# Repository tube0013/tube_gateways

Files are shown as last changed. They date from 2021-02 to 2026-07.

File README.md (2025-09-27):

# TubesZB Coordinators and Routers

⚠️ **Site Re-Organization in progress** ⚠️

Latest Documentation can be found here: https://tube0013.github.io/tube_gateways/

Information and documentation on TubeZB coordinators and routers. Pre-assembled hardware devices can be purchased from https://tubeszb.com

TubesZB Coordinators work via serial over Ethernet for use with any zigbee controller project that can access and interface with a remote Serial to IP bridge/proxy server device. 

This can today be used by home automation applications such as example; [Home Assistant (ZHA integration)](https://www.home-assistant.io/integrations/zha/) and [Zigbee2MQTT](https://www.zigbee2mqtt.io/).

## Check out my Addon Repository
With Firmware flashing and other tools for HASSOS/Supervised users: https://github.com/tube0013/tubeszb_addons



## Current Products 
**Find latest Firmware and Source files**

| **CC2652 Products** | | |
| ----- | --- | --- |
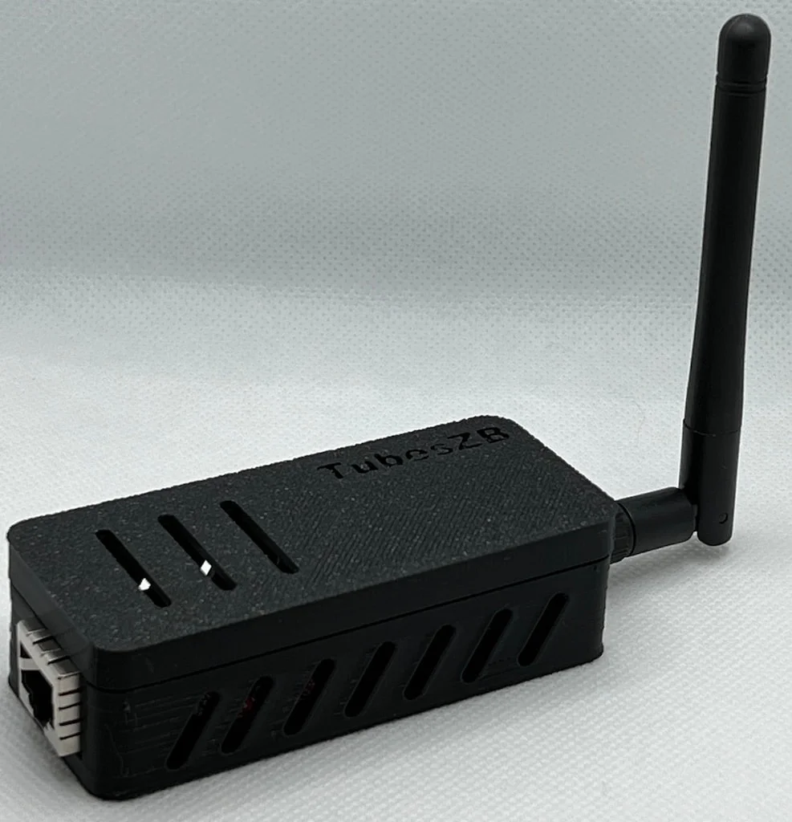
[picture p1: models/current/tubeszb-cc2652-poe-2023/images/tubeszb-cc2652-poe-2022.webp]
|   | [tubeszb-cc2652-poe-2023](https://github.com/tube0013/tube_gateways/tree/main/models/current/tubeszb-cc2652-poe-2023) | CC2652P2 Radio Module + Olimex ESP32-PoE Module |
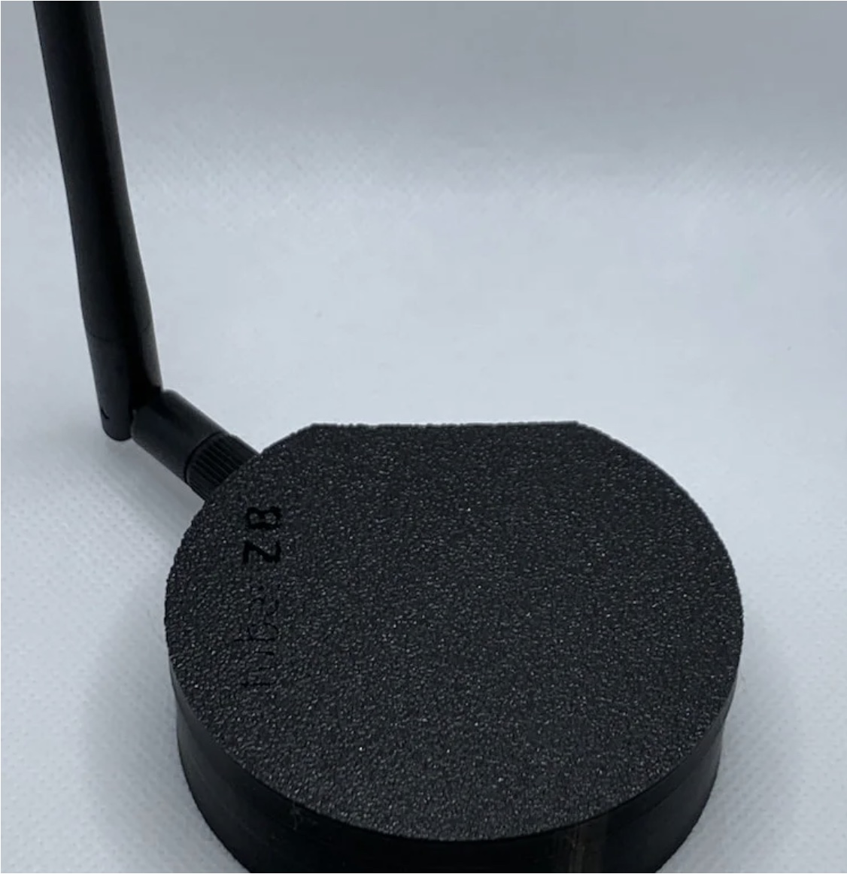
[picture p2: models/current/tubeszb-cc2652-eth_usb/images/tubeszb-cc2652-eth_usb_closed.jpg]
|   | [tubeszb-cc2652-eth_usb](https://github.com/tube0013/tube_gateways/tree/main/models/current/tubeszb-cc2652-eth_usb) | CC2652P2 Radio Module + WirelessTag WT32-ETH01 ESP32 Module |
| pic | [tubeszb-router](https://github.com/tube0013/tube_gateways/tree/main/models/current/tubeszb-router) | CC2652P2 Based Zigbee Router |
| **EFR32 Products** | | |
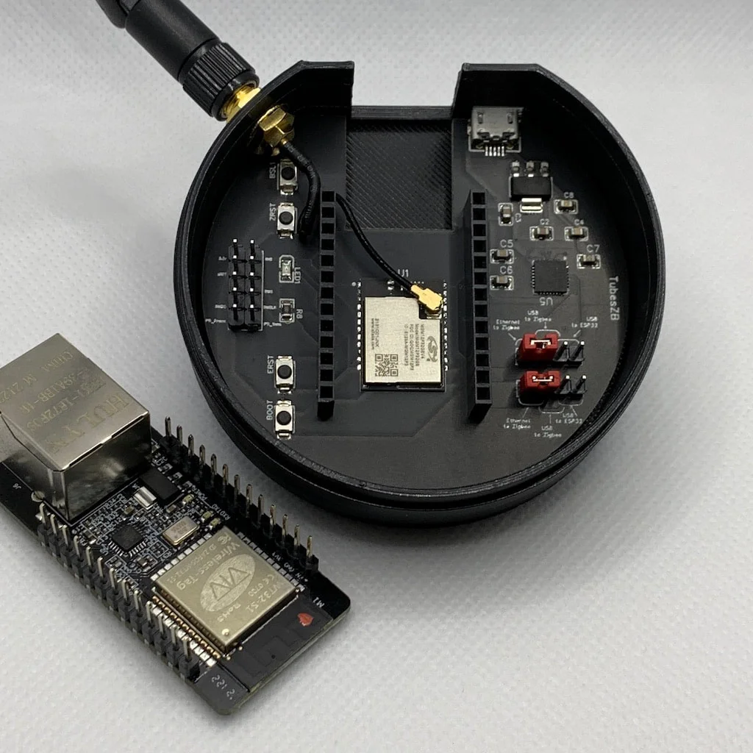
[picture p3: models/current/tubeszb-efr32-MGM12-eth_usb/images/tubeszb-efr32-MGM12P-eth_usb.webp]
|  | [tubeszb-efr32-MGM12-eth_usb](https://github.com/tube0013/tube_gateways/tree/main/models/current/tubeszb-efr32-MGM12-eth_usb) | MGM12P Radio Module + WirelessTag WT32-ETH01 ESP32 Module |
| BT Proxy | | |
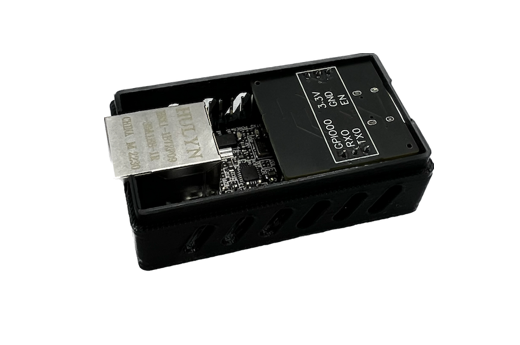
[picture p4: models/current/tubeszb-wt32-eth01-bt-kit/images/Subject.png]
|  | [tubeszb-wt32-eth01-bt-kit](https://github.com/tube0013/tube_gateways/tree/main/models/current/tubeszb-wt32-eth01-bt-kit) | WirelessTag WT32-ETH01 ESP32 Module with USB-C for Power/Flashing |

## Retired Products - Previous hardware versions 
**Find the latest Firmware and Source files**

| **CC2652 Products** | | |
| ----- | --- | --- |
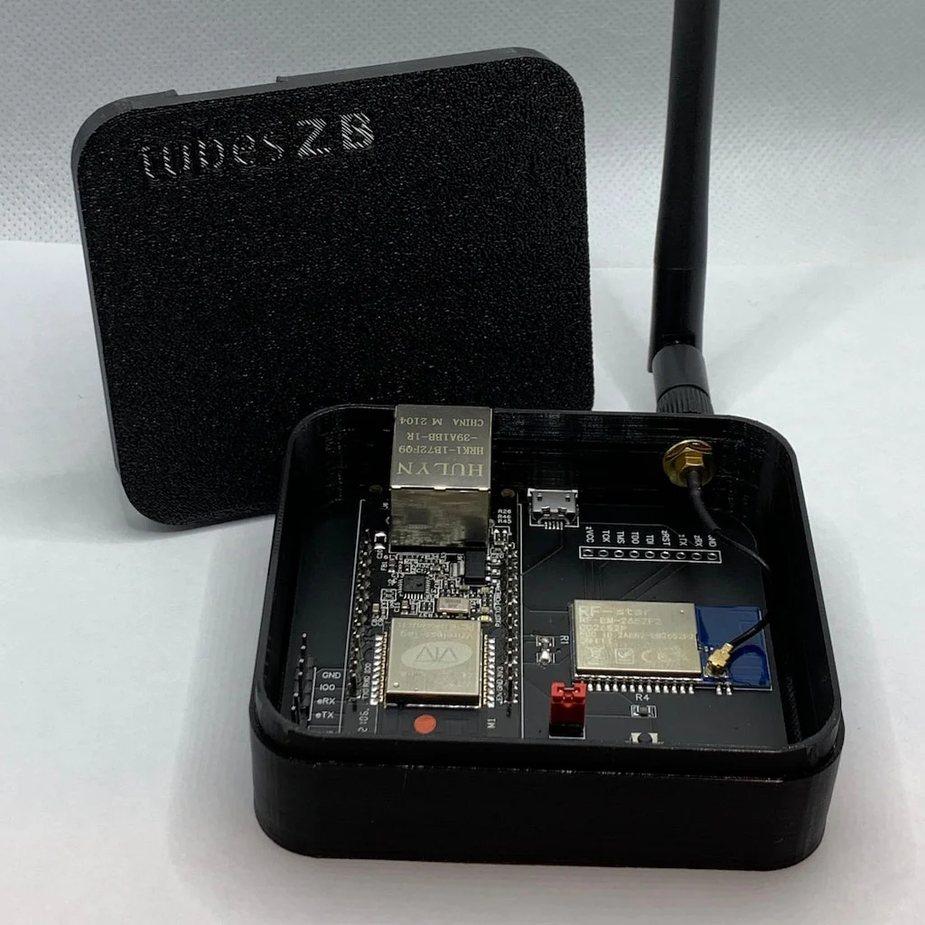
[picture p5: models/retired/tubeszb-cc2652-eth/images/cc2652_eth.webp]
|  | [tubeszb-cc2652-eth](https://github.com/tube0013/tube_gateways/tree/main/models/retired/tubeszb-cc2652-eth) | CC2652P2 Radio Module + WirelessTag WT32-ETH01 ESP32 Module |
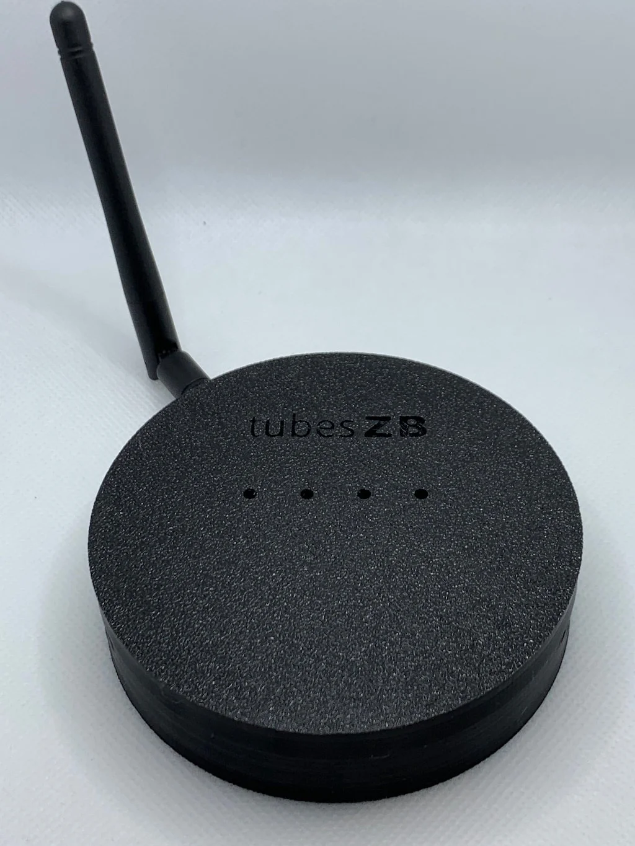
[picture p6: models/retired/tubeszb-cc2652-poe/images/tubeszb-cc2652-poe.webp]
|   | [tubeszb-cc2652-poe](https://github.com/tube0013/tube_gateways/tree/main/models/retired/tubeszb-cc2652-poe) | CC2652P2 Radio Module + Olimex ESP32-PoE Module |
| **EFR32 Products** | | |
| pic | [tubeszb-efr32-MGM112-pro1](https://github.com/tube0013/tube_gateways/tree/main/models/retired/tubeszb-efr32-MGM112-pro1) | MGM12P Radio Module + WirelessTag WT32-ETH01 ESP32 Module |
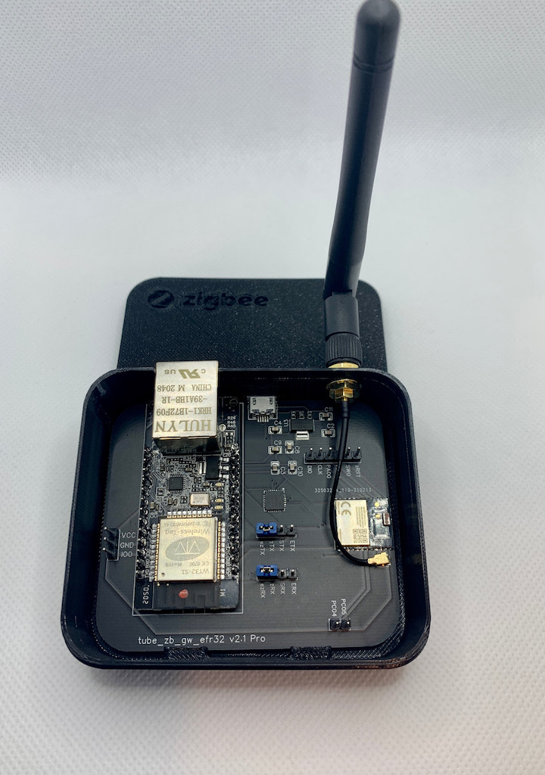
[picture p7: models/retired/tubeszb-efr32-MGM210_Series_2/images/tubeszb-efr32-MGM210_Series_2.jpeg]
|  | [tubeszb-efr32-MGM210_Series_2](https://github.com/tube0013/tube_gateways/tree/main/models/retired/tubeszb-efr32-MGM210_Series_2) | MGM210 Radio Module + WirelessTag WT32-ETH01 ESP32 Module |

## Getting up and Running

## ZHA 

### Network Coordinators
*For EFR32 Gateways see specific insturctions for config file* visit product page

1. Connect the gateway to a ethernet cable which has access you your local network.
2. Power on the gateway with a micro usb cable and 5v 1.5 - 2 amp power supply. The link lights on the ethernet port will start blinking as it tries to negotiate a connection with your home network router.

If the Device is AutoDiscovered, click through the Config flow to add it to HA. 

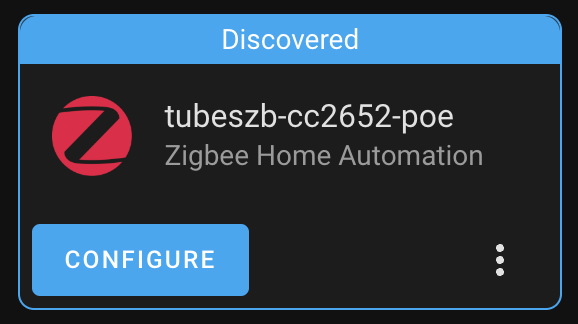
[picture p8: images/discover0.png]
 

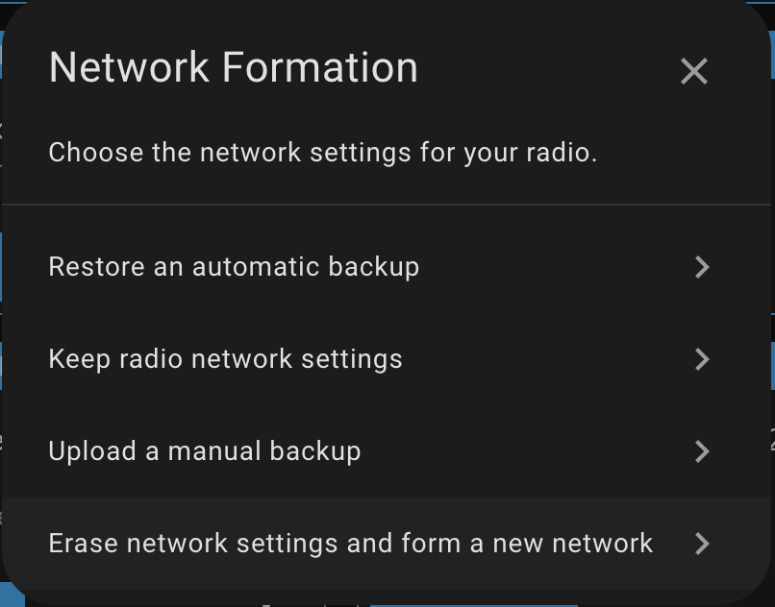
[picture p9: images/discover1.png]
 

If not move on to the below steps.

3. Determine the device's ip address

    **Using a Reserved or static IP Address is strongly advised. Reserve the address in the router **

4. Configure your software to access the device.

    **For HomeAssistant's Built in ZHA implementation:**

    Add the ZHA Integration via the Add Integrations option:

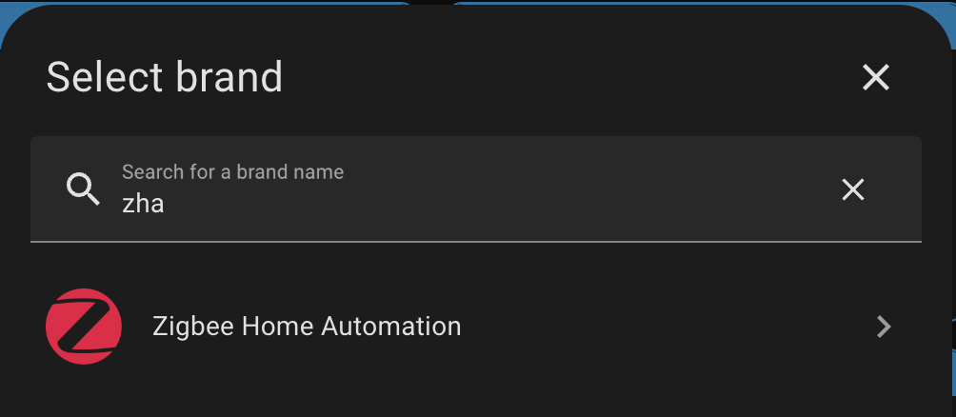
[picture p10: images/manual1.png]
    

    In the next dialog select *Set up another instance of Zigbee Home Automation*:

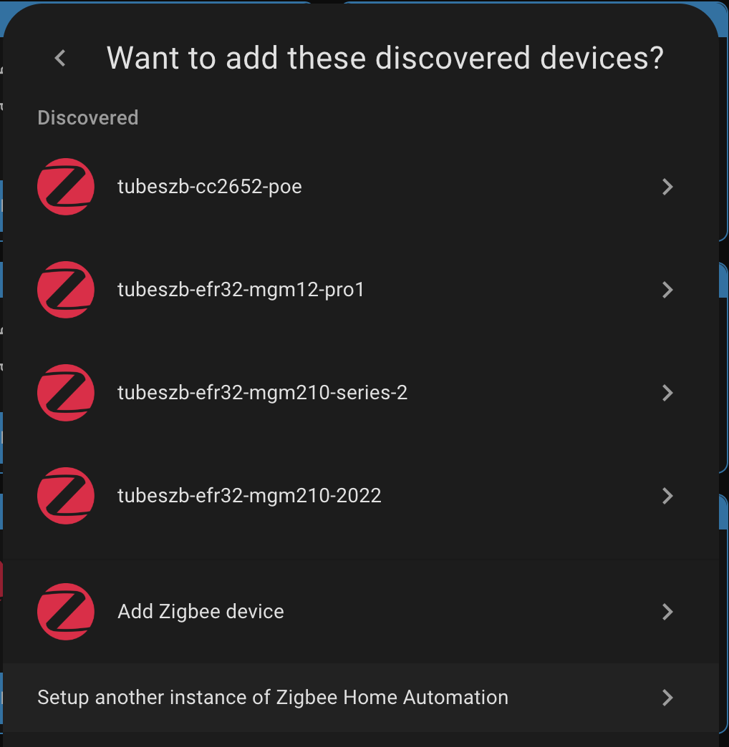
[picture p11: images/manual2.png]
    

    Select the Radio type:

    *For CC2652p based gateways select ZNP*

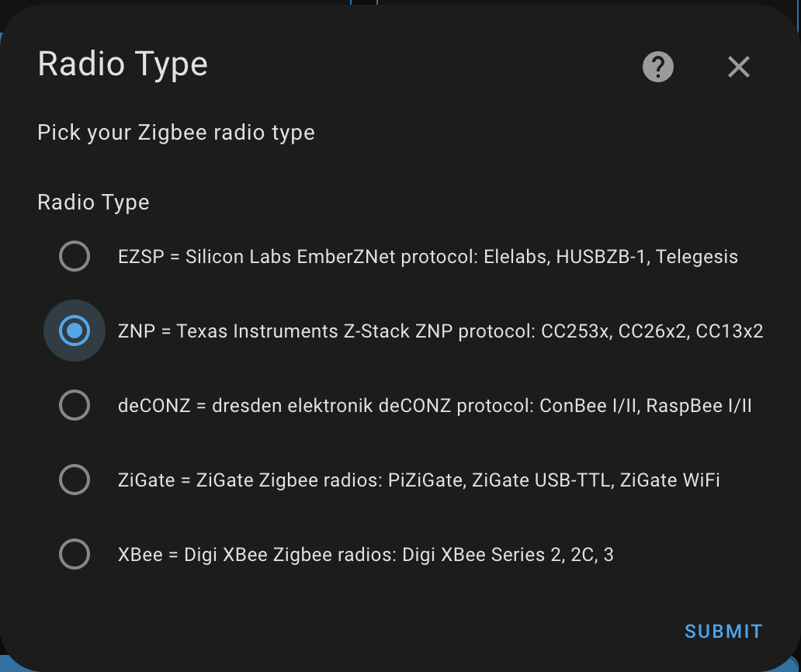
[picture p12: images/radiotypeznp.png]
    

    *For EFR32 based gateways select EZSP*
    
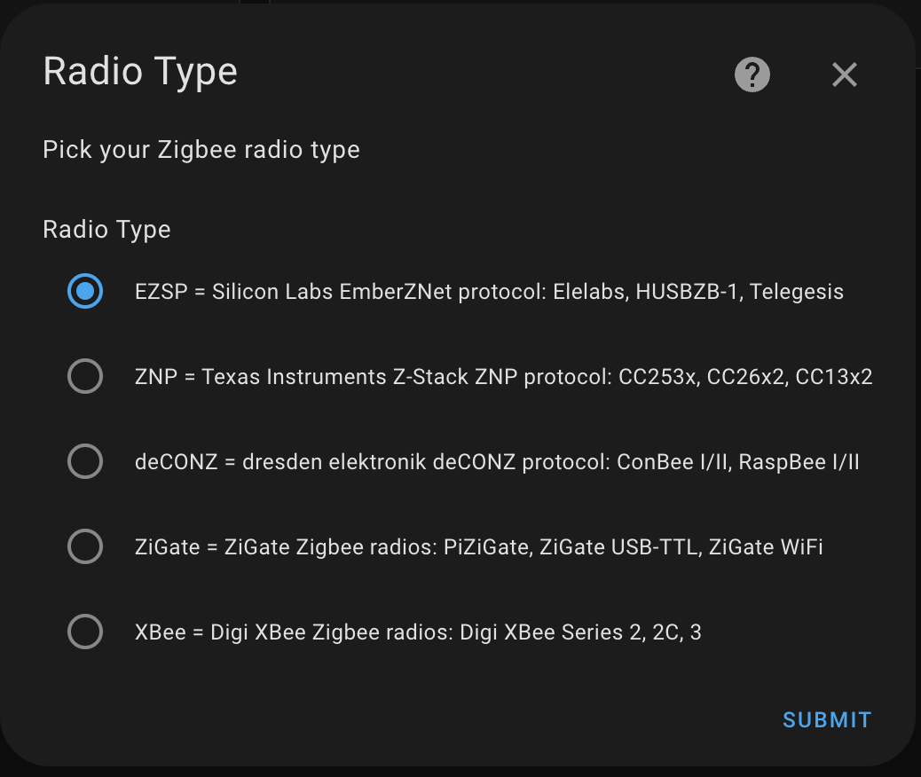
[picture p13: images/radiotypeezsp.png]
    

    For the Specifying the Port Specific Settings: Enter socket://ip_or_localdns_name:6638 and Port Speed of 115200 and Software Flow Control.

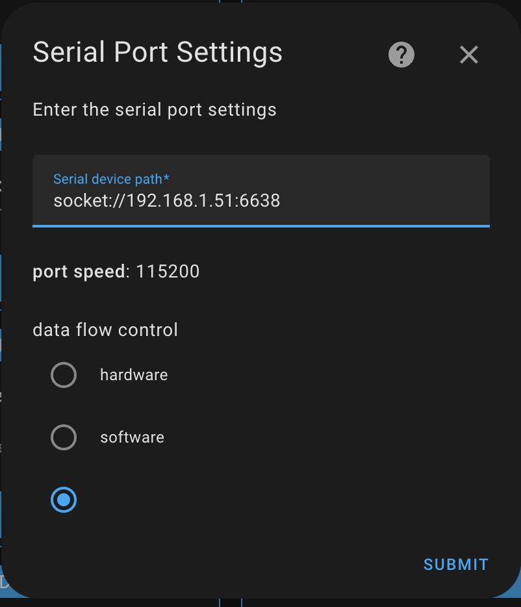
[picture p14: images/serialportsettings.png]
    

### USB Coordinators

Coordinator should be auto disovered 

## Zigbee2MQTT
*For Zigbee2mqtt - Only the CC2652p based gateway is supported at this time, EFR32 may work but is not recommended*

**If Autodiscovered for ZHA, select to ignore the device**

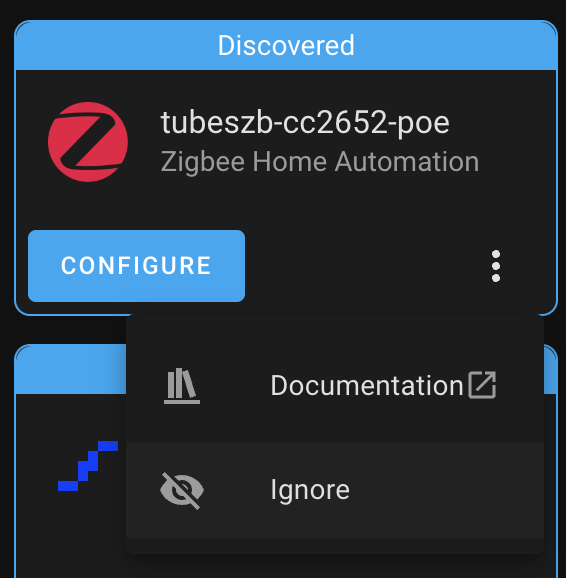
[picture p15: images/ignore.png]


### Network Coordinators 
No need to pass any devices through to Zigbee2MQTT docker container setups.
The docker containers for Zigbee2MQTT do not wrk well with mdns, so for coordinators WITH Ethernet use the ip address of the coordinator here.

Following the Zigbee2MQTT docs, you can skip to step 3. 
https://www.zigbee2mqtt.io/advanced/remote-adapter/connect_to_a_remote_adapter.html#_3-configure

in the Zigbee2MQTT `configuration.yaml`:

For CC2652 based Radios:

```yaml
serial:
  port: 'tcp://IPADDRESS:6638'
  adapter: zstack
```

For EFR32 based radios with 7.4.x or later firmware:
```yaml
serial:
  port: 'tcp://IPADDRESS:6638'
  adapter: ember
```
 
### USB Connected Coordinantors - NO Ethernet 

If not using HAOS be sure to pass the device through to the docker container. Donig that is outside the scope of this documentation.

Find the Devices port:

For using HAOS:
Settings > System > Hardware > 3 Dot menu > All Hardware

OR

Go to the HA command line (for exmaple using this https://community.home-assistant.io/t/home-assistant-community-add-on-ssh-web-terminal/33820) type `ha hardware info` and find the adapter and look for the line `by_id`.

It should look something like 

```
/dev/serial/by-id/usb-1a86_TubesZB_971207DO-if00-port0
```

But may not match exactly depending on the OS/System

Enter that value in the Zigbee2MQTT Addon config or  `configuration.yaml`:

```yaml
serial:
  port: '/dev/serial/by-id/usb-1a86_TubesZB_971207DO-if00-port0'
  adapter: zstack
```

## ESPHome

The ESP32 in the gateway runs ESPHome. Configured in ESPHome are switches in order to prep the zigbee modules for firmware updates if needed. **It is Highly Advised to Ignore these entities in HomeAssistant as accidential toggling could reset the zigbee modules.**

To access the ESPHome Web Interface on the gateway connect to it in your Browser via it's IP address.

Binaries and yaml configs for the devices are under the individual product pages.

## Firmware update instructions are under the individual product pages.

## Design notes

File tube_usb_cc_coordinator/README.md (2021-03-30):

# Tube USB CC2652P2 USB Coordinator

This device functions just as any other USB "Stick" with HA/Z2M. You plug it into your device running HA or z2m, and locate the serial port ceated, typically you will want to use the serial/by-id device so it stays consistent an example would be:

```
/dev/serial/by-id/usb-1a86_USB_Serial-if00-port0
```

HA should autodetect the serial port and show it as an option when setting up ZHA.

For z2m you need to device the port in Z2M's configuration.yaml file.

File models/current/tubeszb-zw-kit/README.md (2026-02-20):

## Notice

The ESPHome configs in this folder are superseded by the TubesZB-ESPHome-Builder repository.
The YAMLs here are kept for historical reference and are not expected to compile with current ESPHome versions.
Use the manifest for this device:
Manifest filename for Red PCB: `tubeszb-zw.yaml`
- [tubeszb-zw.yaml](https://github.com/tube0013/TubesZB-ESPHome-Builder/blob/main/manifests/tubeszb-zw.yaml)

Manifest filename for Purple PCB: `tubeszb-2026-zw.yaml`
- [tubeszb-2026-zw.yaml](https://github.com/tube0013/TubesZB-ESPHome-Builder/blob/main/manifests/tubeszb-2026-zw.yaml)

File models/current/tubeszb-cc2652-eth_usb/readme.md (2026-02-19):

## TubesZB CC2652 Ethernet/USB Coordiniator

## Notice

The ESPHome configs for this device are superseded by the TubesZB-ESPHome-Builder repository.
The YAMLs in this repo are kept for historical reference and are not expected to compile with current ESPHome versions.
Manifest filenames: `tubeszb-cc2652p2-ethusb-2022.yaml`, `tubeszb-cc2652p2-ethusb-2023.yaml`
- [tubeszb-cc2652p2-ethusb-2022.yaml](https://github.com/tube0013/TubesZB-ESPHome-Builder/blob/main/manifests/tubeszb-cc2652p2-ethusb-2022.yaml)
- [tubeszb-cc2652p2-ethusb-2023.yaml](https://github.com/tube0013/TubesZB-ESPHome-Builder/blob/main/manifests/tubeszb-cc2652p2-ethusb-2023.yaml)

<p float="left">
 
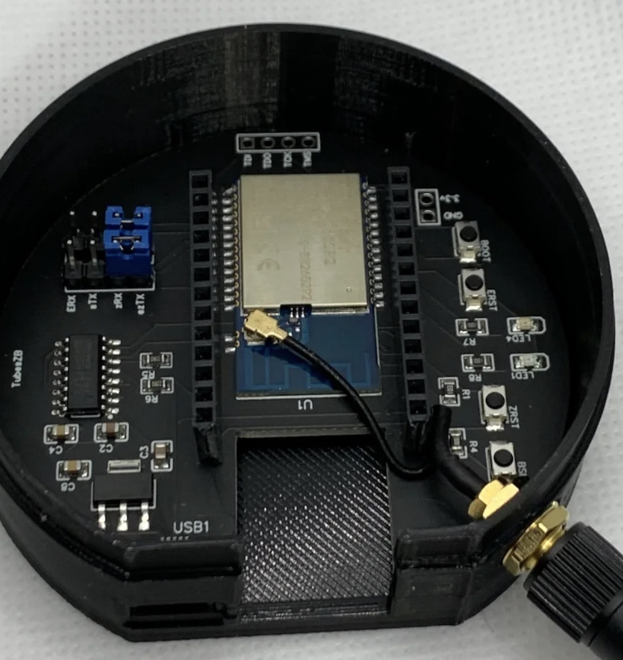
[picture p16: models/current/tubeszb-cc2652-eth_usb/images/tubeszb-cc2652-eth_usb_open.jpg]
 
 </p>

 Available to purchase at the [TubesZB Store](https://tubeszb.com/product/cc2652p2-based-zigbee-to-ethernet-usb-serial-coordinator/) 

 This is the second version of the TubesZB CC2652 Ethernet Coordinator. It takes the place of both the Original CC2652 Ethernet Coordninator and the Original TubesZB USB Coordinator as it can be bought/made with or without ethernet. 
 
 For the USB only variation ethernet can be added at a later time and attachs to the female headers shown in the image above. Adding it is shown in this short YouTube video: https://youtu.be/qbWw0O2dzP0
 
 With regard to flashing the device note that they come pre-flashed. Should an update be required then be aware the adapters WITH Ethernet have two different firmwares and the USB version has one. Both have the zigbee module firmware and how to update that is in the [CC2652 Firmware Flashing section](https://github.com/tube0013/tube_gateways/tree/main/models/current/tubeszb-cc2652-eth_usb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). For the adapters WITH Ethernet the flashing of that module is described in the [ESP32 Flashing section](https://github.com/tube0013/tube_gateways/tree/main/models/current/tubeszb-cc2652-eth_usb#esp32-flashing)  

***

## Jumper Discriptions:

### Zigbee connection over Ethernet (Serial over TCP):

Jumpers positioned on the 2 header pins closes to the Female headers for the WT032-E01 ESP32 module:

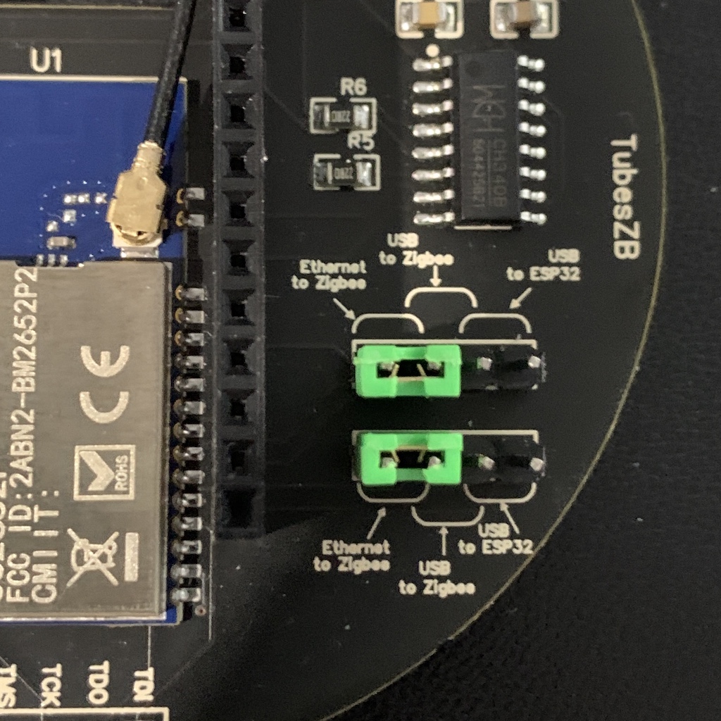
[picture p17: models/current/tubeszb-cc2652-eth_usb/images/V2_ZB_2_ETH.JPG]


---

### Zigbee connection via USB:

Jumpers positions on the middle 2 header pins:

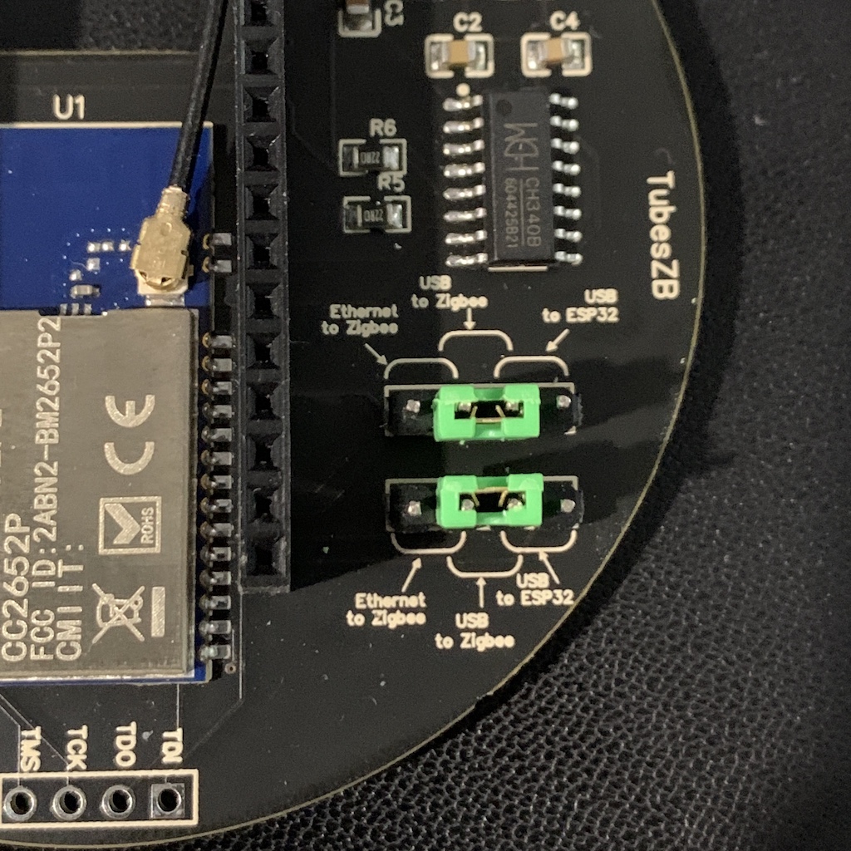
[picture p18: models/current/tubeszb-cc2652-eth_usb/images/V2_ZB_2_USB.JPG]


---

### ESP32 Flashing Mode - ESP32 serial connection via USB:

Jumpers positons on the 2 headers pins furthest from the female headers:

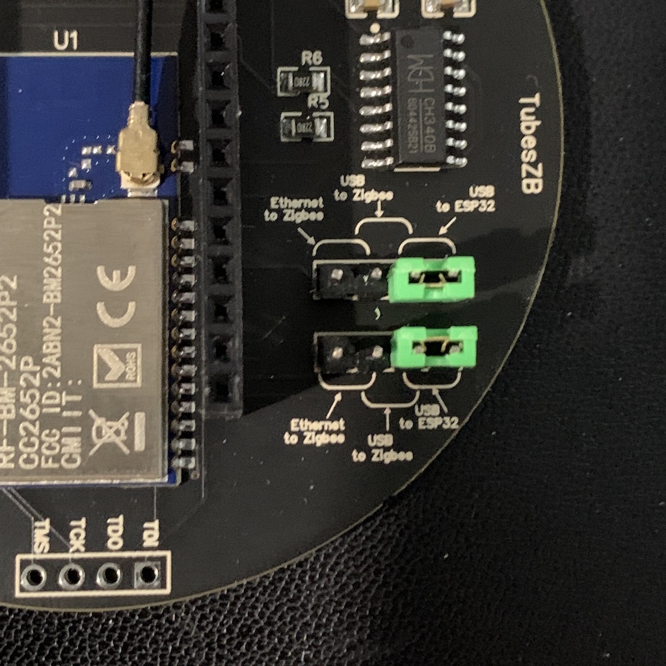
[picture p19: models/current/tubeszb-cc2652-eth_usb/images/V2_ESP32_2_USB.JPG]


---

### Zigbee over Ethernet with ESP32 Debug over USB access:

2 pairs of jumpers side by side:

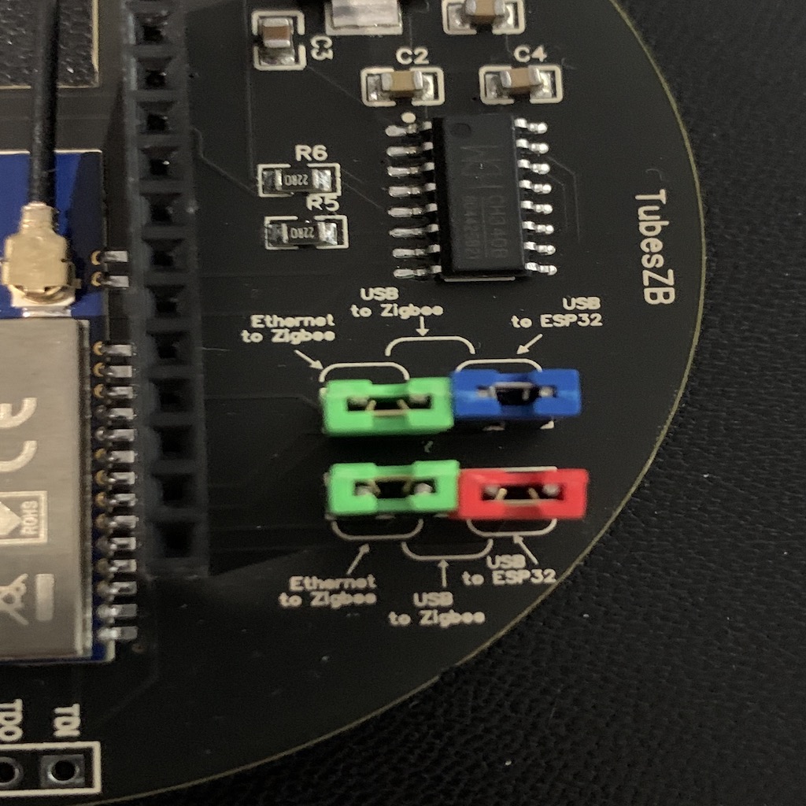
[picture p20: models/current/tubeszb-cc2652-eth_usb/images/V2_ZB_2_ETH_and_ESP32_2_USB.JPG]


## ESP32 Flashing

This section is only relevant for adapters with an ESP32 Ethernet module.

Firmware is available in the [firmware directory for this model](https://github.com/tube0013/tube_gateways/tree/main/models/current/tubeszb-cc2652-eth_usb/firmware/esphome).

Recommend the ESPHome Flasher tool:
https://github.com/esphome/esphome-flasher/releases

Windows will require the CH340 Serial driver. I version can be found [downloaded here](https://www.olimex.com/Products/Breadboarding/BB-CH340T/resources/CH341SER.zip)

Move the jumpers to the ESP32 Flashing mode as described above.

Press and hold the button labeled BOOT on the main pcb board while plugging the USB into the computer that will be flashing the device.

After the flashing completes you can tap the ERST button to do a first boot of the new FW while showing the console in the flashing tool window to confirm it was flashed okay.

## CC2652 Firmware Flashing
This section is relevant to all adapters and relates to the updating of the firmware on the zigbee module.

Firmware - use the **CC1352P2_CC2652P_launchpad_*.zip** based firmware available here:  
https://github.com/Koenkk/Z-Stack-firmware/tree/master/coordinator/Z-Stack_3.x.0/bin

**Be sure you have a current backup of your coordinator before flashing as the update will erase the zigbee module completely** 

Zigbee2MQTT should automatically create a backup on Startup, so start and stop Z2M one time to be sure it is current. Check your z2m config folder for the backup json before flashing.

ZHA Also takes periodic auto backups and will restore the last one automatically when the zha is restarted after an update. you can also download a backup from the ZHA configuration page.

The cc2538-bsl programmer available here:  
https://github.com/JelmerT/cc2538-bsl

(Please note the Dependecies called out on the cc2538-bsl main page: https://github.com/JelmerT/cc2538-bsl#dependencies )

### USB
Move jumpers to Zigbee to USB mode as shown above.

Windows will require the CH340 Serial driver. I version can be found [downloaded here](https://www.olimex.com/Products/Breadboarding/BB-CH340T/resources/CH341SER.zip)

1. Hold the BSL button while plugging in the usb cable.
2. Run the cc2538-bsl flasher:
```
cc2538-bsl.py -p /dev/serial/by-id/usb-1a86_TubesZB_971207DO-if00-port0 -evw path_to_firmware_file/CC1352P2_CC2652P_launchpad_coordinator_20220219.hex
```
Note firmware file name will be different depending on version

3. Confirm the successful flash via the out put from the cc2638-bsl.py script:
```
Verifying by comparing CRC32 calculations.
    Verified (match: 0xddfc152d)
```

### Network
Jumpers in Zigbee to Ethernet mode as shown above

1. Go to the Coordinators web console in your browser - http://coordinatore_ip_address

2. Click the Prep cc2652 for firmware toggle in the web interface - the console will show a message after ~ 10 seconds

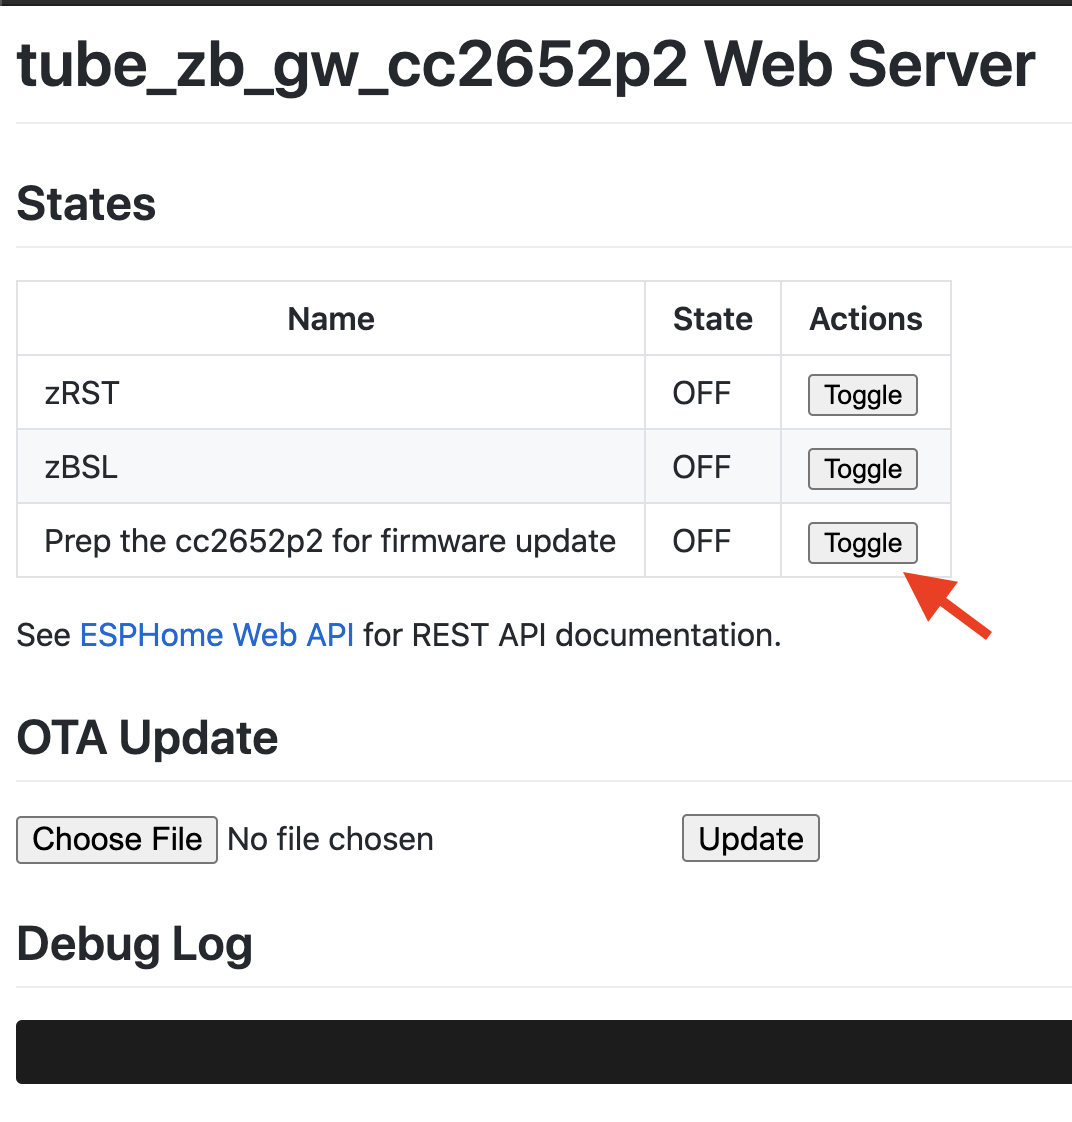
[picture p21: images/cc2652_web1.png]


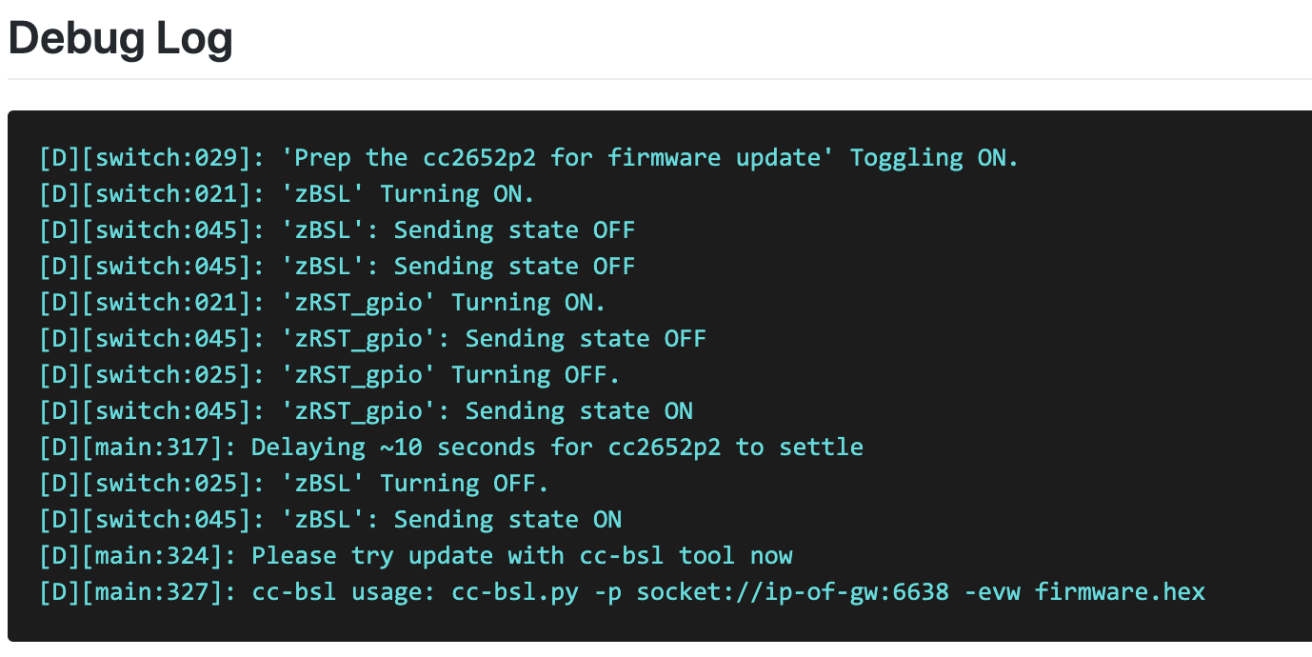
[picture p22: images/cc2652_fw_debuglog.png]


3. Run the cc2538-bsl flasher
```
cc2538-bsl.py -p socket://IP:6638 -evw path_to_firmware_file/CC1352P2_CC2652P_launchpad_coordinator_20220219.hex
```
Note firmware file name will be different depending on version
Flashing over network serial will take approxiamately 5 minutes.

4. Confirm the successful flash via the out put from the cc2638-bsl.py script:
```
Verifying by comparing CRC32 calculations.
    Verified (match: 0xddfc152d)
```

Retry the above steps if bootloader mode is not detected by the script:

```
ERROR: Timeout waiting for ACK/NACK after 'Synch (0x55 0x55)'
```

Another option is to trigger the bootloader manually, to do this, pop the top with the device unpowered, hold down the BSL button while plugging in power, it's important to hold it for several seconds as the ESP32 will trigger a reset of the zigbee module after it boots. Then try the update script again

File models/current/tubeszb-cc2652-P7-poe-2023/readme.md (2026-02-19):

# TubesZB CC2652 P7 PoE Coordinator

## Notice

The ESPHome configs for this device are superseded by the TubesZB-ESPHome-Builder repository.
The YAMLs in this repo are kept for historical reference and are not expected to compile with current ESPHome versions.
Manifest filename: `tubeszb-cc2652p7-poe-2023.yaml`
- [tubeszb-cc2652p7-poe-2023.yaml](https://github.com/tube0013/TubesZB-ESPHome-Builder/blob/main/manifests/tubeszb-cc2652p7-poe-2023.yaml)

<p float="left">
 
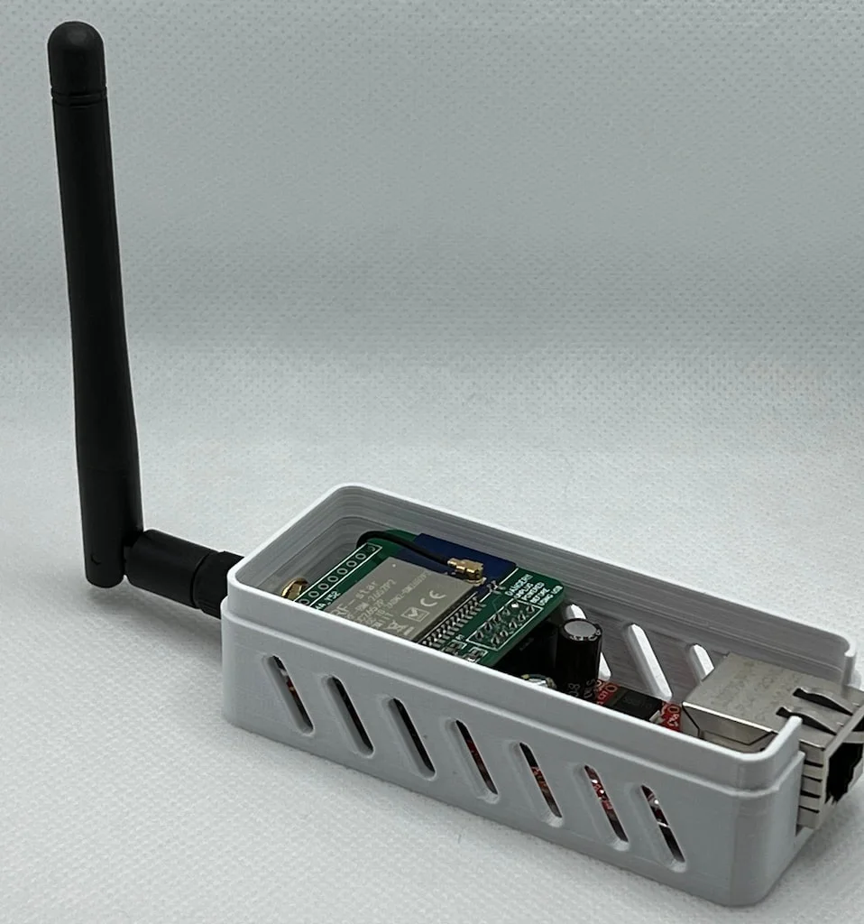
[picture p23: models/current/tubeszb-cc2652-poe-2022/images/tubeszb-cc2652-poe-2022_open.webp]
 
 </p>

 Available to purchase at the [TubesZB Store](https://tubeszb.com/product/cc2652p7-zigbee-to-poe-coordinator-2023/) 

## Power Requirement
PoE switch or Injector required to power

IEEE 802.3-compliant, including pre-standard (legacy) PoE support. The PoE powering requires at least 37V DC to operate successfully

🔴 **_Do Not connect PoE and USB (internal USB port) at the same time - you will burn out the board or computer or both!_** 🔴

## ESP32 Flashing

Firmware is available in the [firmware directory for this model](https://github.com/tube0013/tube_gateways/tree/main/models/current/tubeszb-cc2652-P7-poe-2023/firmware/esphome).

Recommend the ESPHome Flasher tool:
https://github.com/esphome/esphome-flasher/releases

Windows will require the CH340 Serial driver. A version can be found [downloaded here](https://www.olimex.com/Products/Breadboarding/BB-CH340T/resources/CH341SER.zip)

Partially removed the board from the case to access the microUSB port on the Olimex ESP32-PoE module. Use a USB cable (not power only) to connect the the board to the computer doing the flashing. Reminder do not connect USB and Powered ethernet concurrently.

After the flashing completes the esp32 will automatically reset and boot the new FW while showing the console in the flashing tool window to confirm it was flashed okay.

## CC2652 Firmware Flashing

Firmware - use the **CC1352P7_coordinator_*.zip** based firmware available here:  
https://github.com/Koenkk/Z-Stack-firmware/tree/master/coordinator/Z-Stack_3.x.0/bin

**Be sure you have a current backup of your coordinator before flashing as the update will erase the zigbee module completely** 

Zigbee2MQTT should automatically create a backup on Startup, so start and stop Z2M one time to be sure it is current. Check your z2m config folder for the backup json before flashing.

ZHA Also takes periodic auto backups and will restore the last one automatically when the zha is restarted after an update. you can also download a backup from the ZHA configuration page.

https://github.com/zigpy/zigpy-znp/blob/dev/TOOLS.md#backup-and-restore

The cc2538-bsl programmer available here: 
https://github.com/JelmerT/cc2538-bsl

(Please note the Dependecies called out on the cc2538-bsl main page: https://github.com/JelmerT/cc2538-bsl#dependencies )

### USB

USB can be used to flash the cc2652 module if you have an external USB to serial adapter and dupont connector cables.

(More details coming)

### Network

1. Go to the Coordinators web console in your browser - http://coordinatore_ip_address

2. Click the `Trigger Zigbee Module Bootloader` toggle in the web interface - the console will show a message after ~ 10 seconds

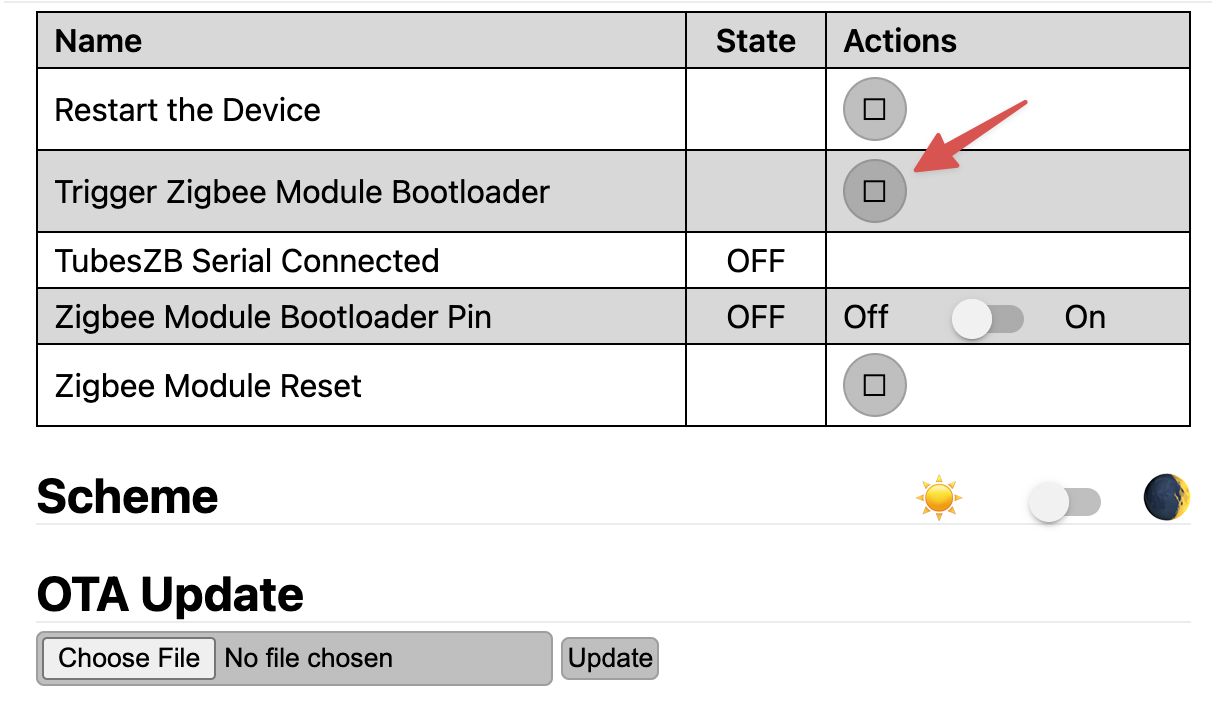
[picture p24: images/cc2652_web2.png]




3. Run the cc2538-bsl flasher
```
cc2538-bsl.py -p socket://IP:6638 -evw path_to_firmware_file/CC1352P7_coordinator_20240710.hex
```
Note firmware file name will be different depending on version
Flashing over network serial will take approxiamately 5 minutes.

4. Confirm the successful flash via the out put from the cc2638-bsl.py script:
```
Verifying by comparing CRC32 calculations.
    Verified (match: 0xddfc152d)
```

Retry the above steps if bootloader mode is not detected by the script:

```
ERROR: Timeout waiting for ACK/NACK after 'Synch (0x55 0x55)'
```

Another option is to trigger the bootloader manually, to do this, pop the top with the device unpowered, hold down the BSL button while plugging in power, it's important to hold it for several seconds as the ESP32 will trigger a reset of the zigbee module after it boots. Then try the update script again

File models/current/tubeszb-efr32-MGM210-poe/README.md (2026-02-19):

# TubesZB EFR32 MGM210 PoE Coordinator

## Notice

The ESPHome configs for this device are superseded by the TubesZB-ESPHome-Builder repository.
The YAMLs in this repo are kept for historical reference and are not expected to compile with current ESPHome versions.
Manifest filenames: `tubeszb-efr32-mgm210-poe-2022.yaml`, `tubeszb-efr32-mgm210-poe-2023.yaml`
- [tubeszb-efr32-mgm210-poe-2022.yaml](https://github.com/tube0013/TubesZB-ESPHome-Builder/blob/main/manifests/tubeszb-efr32-mgm210-poe-2022.yaml)
- [tubeszb-efr32-mgm210-poe-2023.yaml](https://github.com/tube0013/TubesZB-ESPHome-Builder/blob/main/manifests/tubeszb-efr32-mgm210-poe-2023.yaml)

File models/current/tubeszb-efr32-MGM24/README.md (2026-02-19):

# TubesZB EFR32 MGM24 Coordinator

## Notice

The ESPHome configs for this device are superseded by the TubesZB-ESPHome-Builder repository.
The YAMLs in this repo are kept for historical reference and are not expected to compile with current ESPHome versions.
Manifest filename: `tubeszb-efr32-mgm24-2023.yaml`
- [tubeszb-efr32-mgm24-2023.yaml](https://github.com/tube0013/TubesZB-ESPHome-Builder/blob/main/manifests/tubeszb-efr32-mgm24-2023.yaml)

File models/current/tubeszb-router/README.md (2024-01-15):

# Tube's Router

Device should go into pairing mode as soon as it is powered up for the first time.

To factory reset, open case (it's a friction fit) and a single press of the BSL button will reset the device.

FW Updates require the use of a serial to usb converter.
hold the BSL button when powering the device, keep it held for ~10 seconds to get the device into bootloader mode. Release the button and then use the Use the cc2538-bsl programmer available here: https://github.com/JelmerT/cc2538-bsl to update the FW. if it stalls or fails just repeat.

Devices shipped in 2021 are flashed with Firmware from the Z-Stack Router FW Repository: https://github.com/Koenkk/Z-Stack-firmware/tree/master/router/Z-Stack_3.x.0/bin  specfically the CC1352P2_CC2652P_launchpad_router_* FW.

In 2022 I made some tweaks to the FW and it can be found here along with the changes described: https://github.com/tube0013/tube_gateways/tree/main/models/current/tubeszb-router/firmware

## Flashing the Router

To flash new firmware onto the router you will need a USB to Serial adaptor. Something like this will work well and is similar to the ones I uses: [CP2102 USB to TTL modules](https://amzn.to/3HjQ7bx) Note generally you can find adaptors with the cp210x, ch340 for FTDI chips. most are supported fine on Linux or Mac but you may need drivers for Windows.

Just with the coordinator firmware you'll need the cc2538-bsl programmer available here: https://github.com/JelmerT/cc2538-bsl

Using the dupont jumper wires, connect them to the serial adaptor using the 3.3v, GND, RX and TX pins. line up the other end of the wires so that they are in the GND,TX,RX,3.3v order. these will connect to the router's GND,RX,TX, and 3.3v pins.

With the USB cto serial adaptor plugged into a computer, hold the 4 dupont connectors together lined up in order. Hold the BSL button down while sliding the 4 connectors over the pins on the board.

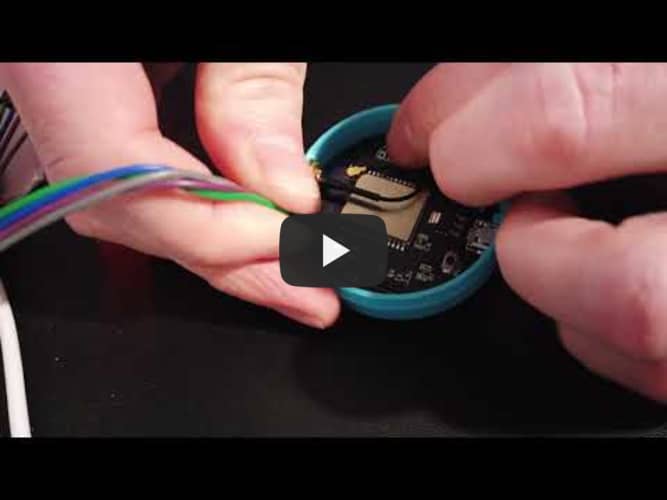
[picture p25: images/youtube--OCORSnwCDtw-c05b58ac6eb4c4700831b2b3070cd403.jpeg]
TubesZB Router FW Update Wiring Setup (https://youtu.be/OCORSnwCDtw "TubesZB Router FW Update Wiring Setup")


At this point the cc2652 module should be in bootloader mode, and flashing can be done with the cc2538-bsl tool.

```cc2538-bsl.py -p /dev/cu.usbserial-00F9450F -evw /PATH_TO/tubeszb_router_20220111.hex```

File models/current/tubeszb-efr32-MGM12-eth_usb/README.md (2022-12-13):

# Specific Configuration for the Tube EFR32 Gateways
Because the EFR32 gateways uses some firmware settings different than the bellows defaults it is recommended set them in the configuration.yaml so bellows will utilize them.

## For 2022 EFR32 Pro V2 Coordinators:
**Add these lines to your configuration.yaml file**

```
zha:
  custom_quirks_path: zha_custom_quirks  # Optional Customs Quirk Path
  zigpy_config:
    ota:                                 # Optional OTA device firmware settings
      otau_directory: /config/zigpy_ota
      ikea_provider: true
      ledvance_provider: true
    source_routing: true
    handle_unknown_devices: true
    ezsp_config:
      CONFIG_APS_UNICAST_MESSAGE_COUNT: 30
      CONFIG_TX_POWER_MODE: 3
      CONFIG_MAX_END_DEVICE_CHILDREN: 32
      CONFIG_BROADCAST_TABLE_SIZE: 60
      CONFIG_SOURCE_ROUTE_TABLE_SIZE: 200
      CONFIG_ROUTE_TABLE_SIZE: 32
      CONFIG_ADDRESS_TABLE_SIZE: 32
      CONFIG_PACKET_BUFFER_COUNT: 255
      CONFIG_BINDING_TABLE_SIZE: 32
      CONFIG_NEIGHBOR_TABLE_SIZE: 16
      CONFIG_MTORR_FLOW_CONTROL: 1
      CONFIG_MAX_HOPS: 5
```

**EFR32 Firmware Updates:**

https://www.youtube.com/watch?v=zKrISuWEzL4tube-

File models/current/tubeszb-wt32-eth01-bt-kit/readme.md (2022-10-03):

# TubesZB WT32-ETH01 Bluetooth Proxy kit

Devices are shipped preflashed from the ESPHome Bluetooth Proxy site:

https://esphome.github.io/bluetooth-proxies/?diy

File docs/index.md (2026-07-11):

# Welcome to the TubesZB Documentation

This site contains all the information and documentation for Tube's ZB hardware. Find the right guide to get your new device up and running with Home Assistant.

You can purchase pre-assembled hardware from the official store:

[**Shop at tubeszb.com**](https://tubeszb.com)

## Getting Started Guides

Click on the guide that matches your product to begin the setup process.

<div class="grid cards" markdown>

-   __Zigbee Coordinators__

    ---

    Step-by-step instructions for setting up your TubeZB Zigbee Coordinator with ZHA or Zigbee2MQTT.

    [:octicons-arrow-right-24: View Zigbee Guide](getting-started/zigbee.md)

-   __Z-Wave PoE Kit__

    ---

    How to set up your Z-Wave PoE kit using the Z-Wave JS UI addon in Home Assistant.

    [:octicons-arrow-right-24: View Z-Wave Guide](getting-started/z-wave.md)

-   __Zigbee Routers__

    ---

    How to pair your TubeZB Zigbee Router to extend the range of your network.

    [:octicons-arrow-right-24: View Router Guide](getting-started/router.md)

-   __Bluetooth Proxy__

    ---

    Quickly set up and extend the Bluetooth coverage of your Home Assistant instance.

    [:octicons-arrow-right-24: View Bluetooth Proxy Guide](getting-started/bluetooth-proxy.md)

-   __Dual Radio Kit__

    ---

    The Dual Radio Kit combines a Zigbee and a Z-Wave radio on a single device. You will need to set up **both** protocols.

    !!! info "Important Note for Dual Radio Kits"
        The Zigbee and Z-Wave radios share an IP address but connect differently.
        * **Zigbee** uses the serial stream on port `6638`.
        * **Z-Wave** uses the ESPHome Z-Wave proxy on port `6053` (`esphome://`). On firmware older than `2026.07.11.0` it is a serial stream on port `6639` instead.

    [:octicons-arrow-right-24: View Zigbee Guide](getting-started/zigbee.md)
    
    [:octicons-arrow-right-24: View Z-Wave Guide](getting-started/z-wave.md)

</div>

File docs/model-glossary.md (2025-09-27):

# Model Glossary

Use this guide to visually identify your TubeZB device and find links to its specific documentation and source files.

---

## Current Models

These are the models currently available for purchase on [tubeszb.com](https://tubeszb.com). Click the model name to go to the relevant documentation page.

| Image | Model Name | Description |
| :---: | :--- | :--- |
|  | [EFR32 MGM24 PoE Coordinator 2024](zigbee-coordinators/efr32-based/index.md) | EFR32MG24 Radio + Olimex ESP32-PoE Module |
|  | [CC2652P7 PoE Coordinator 2023](zigbee-coordinators/cc2652-based/index.md) | CC2652P7 Radio + Olimex ESP32-PoE Module |
|  | [CC2652P2 PoE Coordinator 2023](zigbee-coordinators/cc2652-based/index.md) | CC2652P2 Radio + Olimex ESP32-PoE Module |
|  | [CC2652P2 Ethernet/USB Coordinator 2023](zigbee-coordinators/cc2652-based/index.md) | CC2652P2 Radio + WirelessTag WT32-ETH01 Module |
|  | [Z-Wave PoE Kit](zwave-kits/index.md) | Olimex ESP32-PoE base for Z-Wave modules |
|  | [Dual Radio Kit](dual-radio-kits/index.md) | Combines Zigbee and Z-Wave radios |
|  | [Zigbee Router](zigbee-routers/cc2652-based-routers/index.md) | CC2652P2 Based Zigbee Router/Repeater |
|  | [Bluetooth Proxy Kit](bluetooth-proxy/index.md) | WirelessTag WT32-ETH01 ESP32 Module |

---

## Retired Models

These are previous hardware versions that are no longer sold but are still supported. The links below go to the source files on GitHub.

| Image | Model Name | Description |
| :---: | :--- | :--- |
|  | [tubeszb-efr32-MGM12-eth_usb](https://github.com/tube0013/tube_gateways/tree/main/models/current/tubeszb-efr32-MGM12-eth_usb) | MGM12P Radio Module + WirelessTag WT32-ETH01 ESP32 Module |
|  | [tubeszb-cc2652-eth](https://github.com/tube0013/tube_gateways/tree/main/models/retired/tubeszb-cc2652-eth) | CC2652P2 Radio Module + WirelessTag WT32-ETH01 ESP32 Module |
|  | [tubeszb-cc2652-poe](https://github.com/tube0013/tube_gateways/tree/main/models/retired/tubeszb-cc2652-poe) | CC2652P2 Radio Module + Olimex ESP32-PoE Module |
| *Image Needed* | [tubeszb-efr32-MGM112-pro1](https://github.com/tube0013/tube_gateways/tree/main/models/retired/tubeszb-efr32-MGM112-pro1) | MGM12P Radio Module + WirelessTag WT32-ETH01 ESP32 Module |
|  | [tubeszb-efr32-MGM210_Series_2](https://github.com/tube0013/tube_gateways/tree/main/models/retired/tubeszb-efr32-MGM210_Series_2) | MGM210 Radio Module + WirelessTag WT32-ETH01 ESP32 Module |

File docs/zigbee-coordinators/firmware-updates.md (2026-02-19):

# Coordinator Firmware Updates

TubesZB coordinators have two independent firmwares:

- ESP32 firmware (ESPHome): handles Ethernet/USB bridging, web UI, and diagnostics.
- Zigbee radio firmware: the CC2652/CC1352 or EFR32 radio itself.

!!! warning "Back up before updating"
    Zigbee radio firmware updates erase the coordinator state. ZHA and Zigbee2MQTT both create automatic backups, but confirm you have a recent backup before updating.

## ESP32 Firmware (ESPHome)

ESPHome firmware is now built in the **TubesZB ESPHome Builder**. The standalone ESPHome Flasher app is no longer maintained and is not recommended.

### Recommended: Update from the device web UI

Modern TubesZB firmware supports updating directly from the coordinator without any external program.

1. Open the coordinator web UI at `http://IP_ADDRESS`.
2. Use the **Update** or **Firmware** option in the UI.
3. Upload the new `.bin` from the TubesZB ESPHome Builder.
4. Wait for the device to reboot and reconnect.

### Web flasher (USB)

If you need to flash over USB or recover a device, use the ESPHome Web Flasher:

1. Build or download the firmware `.bin` from the TubesZB ESPHome Builder.
2. Open `https://web.esphome.io` in a Chromium-based browser.
3. Connect the coordinator over USB and select the correct serial device.
4. Choose the `.bin` file and flash.

!!! tip "When to use the web flasher"
    Use the web flasher for first-time installs, recovery, or when the device web UI is unavailable.

## Zigbee Radio Firmware (CC2652/CC1352)

CC2652 and CC1352 radios update over the same TCP or USB path used for Zigbee traffic.

1. Download a coordinator firmware from the Z-Stack repository.
https://github.com/Koenkk/Z-Stack-firmware/tree/master/coordinator/Z-Stack_3.x.0/bin
2. Install the cc2538-bsl flasher.
https://github.com/JelmerT/cc2538-bsl

### Ethernet update (PoE or Ethernet/USB in Ethernet mode)

1. Open the coordinator web UI at `http://IP_ADDRESS`.
2. Trigger the Zigbee bootloader from the web UI. The toggle is labeled "Trigger Zigbee Module Bootloader" or "Prep CC2652 for firmware" depending on the firmware build.
3. Run the flasher:

```bash
cc2538-bsl.py -p socket://IP_ADDRESS:6638 -evw path_to_firmware/CC1352P2_CC2652P_launchpad_coordinator_YYYYMMDD.hex
```

For CC2652 P7 models, use a `CC1352P7_coordinator_*.hex` firmware file.

### USB update (Ethernet/USB model in USB mode)

1. Hold the BSL button while plugging the USB cable in.
2. Run the flasher:

```bash
cc2538-bsl.py -p /dev/serial/by-id/usb-1a86_TubesZB_XXXXXXXX-if00-port0 -evw path_to_firmware/CC1352P2_CC2652P_launchpad_coordinator_YYYYMMDD.hex
```

Windows users may need the CH340 USB serial driver for USB flashing.

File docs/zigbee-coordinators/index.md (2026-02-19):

# Zigbee Coordinators

TubesZB coordinators provide a reliable Ethernet or USB bridge between your Zigbee radio and Home Assistant or Zigbee2MQTT. The two platform families below cover different radio stacks while sharing the same setup flow.

## [EFR32 Platform (Silicon Labs EZSP)](efr32-based/index.md)

EFR32 radios use the Silicon Labs EZSP/Ember stack. They are supported by both ZHA and Zigbee2MQTT and are a strong choice for modern Zigbee networks.

- ZHA radio type: **EZSP**
- Zigbee2MQTT adapter: **ember**

### MGM24

- 2.4 GHz radio
- TX power up to +19.9 dBm
- 32-bit ARM Cortex-M33, 78 MHz
- 1536 KB flash program memory
- 256 KB RAM data memory

### MGM21

- 2.4 GHz radio
- TX power up to +20 dBm
- 32-bit ARM Cortex-M33 with DSP instructions and floating point unit
- 1024 KB flash program memory
- 96 KB RAM data memory
- Embedded Trace Macrocell (ETM) for advanced debugging

### MGM12

- 32-bit ARM Cortex-M4 core, 40 MHz maximum operating frequency
- Up to 1 MB flash and 256 KB RAM
- Pin-compatible across EFR32MG families (5V-tolerant pins excluded)
- 12-channel Peripheral Reflex System, low-energy sensor interface, and multi-channel capacitive sense interface
- Autonomous hardware crypto accelerator and true random number generator
- Integrated PA with up to 19 dBm (2.4 GHz) or 20 dBm (Sub-GHz) TX power
- Integrated balun for 2.4 GHz
- Robust peripheral set and up to 65 GPIO

## [CC2652 Platform (TI ZNP)](cc2652-based/index.md)

CC2652/CC1352 radios use the Texas Instruments ZNP stack and are widely supported in both ZHA and Zigbee2MQTT. These models are known for broad device compatibility and a mature firmware ecosystem.

- ZHA radio type: **ZNP**
- Zigbee2MQTT adapter: **zstack**

### CC2652 / CC1352

- 48 MHz ARM Cortex-M4F processor
- 704 KB in-system programmable flash (352 KB on P2)
- 256 KB ROM for protocol and library functions
- 8 KB cache SRAM (or general-purpose RAM)
- 144 KB ultra-low leakage SRAM (80 KB on P2)
- Output power up to +20 dBm
- Z-Stack firmware supports 50 direct children, 100 normal routes, and 200 source routes

## Supported in ZHA and Zigbee2MQTT

Both CC2652 and EFR32 platforms are supported by Home Assistant's ZHA integration and Zigbee2MQTT. The main difference is the adapter selection in each platform's configuration. Setup steps and TCP/USB connection paths are the same across both families.

## Radio Migration Guides

- ZHA migration: <a href="https://www.home-assistant.io/integrations/zha/#migrating-to-a-new-zigbee-adapter-inside-zha" target="_blank" rel="noopener">Home Assistant ZHA migration guide</a>
- Zigbee2MQTT migration: <a href="https://www.zigbee2mqtt.io/guide/faq/#how-do-i-migrate-from-one-adapter-to-another" target="_blank" rel="noopener">Zigbee2MQTT adapter migration FAQ</a>

## Choose Your Path

- [CC2652-Based Coordinators](cc2652-based/index.md)
- [EFR32-Based Coordinators](efr32-based/index.md)
- [Coordinator Firmware Updates](firmware-updates.md)

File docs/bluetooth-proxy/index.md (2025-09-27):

# WT32-ETH01 Bluetooth Proxy Kit

<figure markdown>
  Bluetooth Proxy Kit
</figure>

The TubeZB Bluetooth Proxy Kit is a simple and effective way to extend the Bluetooth coverage of your Home Assistant instance. It uses a wired ethernet connection for maximum reliability.

---

## Getting Started

For initial setup and integration with Home Assistant, please follow the main Bluetooth Proxy getting started guide.

[:octicons-arrow-right-24: View Bluetooth Proxy Getting Started Guide](../getting-started/bluetooth-proxy.md)

---

## How It Works

This kit acts as a remote "ear" for Home Assistant. You can place it anywhere in your home where you have an ethernet connection. It will listen for Bluetooth Low Energy (BLE) advertisements from devices like temperature sensors, smart locks, and more. It then relays these messages back to Home Assistant over your wired network.

This allows you to integrate Bluetooth devices that are far away from your main Home Assistant server.

---

## Firmware

The device comes pre-flashed with a standard ESPHome Bluetooth proxy firmware. If you ever need to re-flash or update the device, you can do so easily.

### Flashing Instructions

1.  Connect the Bluetooth Proxy Kit to your computer using a **USB-C data cable**.
2.  Navigate to the **[TubesZB Web Flasher](https://tube0013.github.io/TubesZB-ESPHome-Builder/)**.
3.  Select "Bluetooth Proxy" from the device dropdown menu.
4.  Follow the on-screen instructions to connect to the device and flash the latest firmware.

### Advanced Users & Source YAML

This kit is based on the official ESPHome Wireless Tag WT32-ETH01 project. Advanced users who wish to compile their own custom firmware can find the base YAML configuration files in the **[ESPHome GitHub repository](https://github.com/esphome/bluetooth-proxies/tree/main/wt32)**.

For more in-depth details on how the proxy functionality works within ESPHome, please refer to the official **[ESPHome Bluetooth Proxy Documentation](https://esphome.io/components/bluetooth_proxy.html)**.

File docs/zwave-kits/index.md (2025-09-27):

# Z-Wave PoE Kit

<figure markdown>
  Z-Wave PoE Kit
</figure>

The TubeZB Z-Wave PoE Kit provides a reliable, network-connected Z-Wave radio for Home Assistant. It is powered by Power over Ethernet (PoE) and uses an ESP32 microcontroller to bridge the Z-Wave serial module to your network.

---

## Getting Started

For initial setup and integration with Home Assistant, please follow the main Z-Wave getting started guide.

[:octicons-arrow-right-24: View Z-Wave Getting Started Guide](../getting-started/z-wave.md)

---

## Hardware Components

The Z-Wave PoE Kit consists of two main printed circuit boards (PCBs):

1.  **Olimex ESP32-PoE Board:** This is the brains of the device. It's an ESP32 development board that includes a built-in PoE module, allowing it to be powered directly from a compatible network switch or injector. It runs a custom ESPHome firmware to manage the network connection and communication with the Z-Wave radio.

2.  **Raspberry Pi GPIO to Olimex UEXT Converter:** This is a custom adapter board designed specifically to connect Z-Wave modules with a Raspberry Pi GPIO-style header to the Olimex board's UEXT connector. You can find more details on the [converter's product page](https://tubeszb.com/product/raspberry-pi-gpio-to-olimex-uext-for-z-wave-adaptors/).

### 3D Printed Enclosure

For those who wish to print their own case, the STL files are available on GitHub.

[:octicons-file-zip-16: Download Case STL Files](https://github.com/tube0013/tube_gateways/tree/main/models/current/tubeszb-zw-kit/Case)

---

## Firmware Updates

There are two separate firmwares on this device that can be updated: the **ESPHome firmware** on the ESP32, and the **firmware on the Z-Wave radio module** itself.

### ESPHome Firmware (ESP32)

The ESPHome firmware handles the network connectivity. You can update it using the web-based flashing tool. For advanced users, the base ESPHome YAML configuration is also available.

- **[View the current ESPHome YAML Configuration](https://raw.githubusercontent.com/tube0013/TubesZB-ESPHome-Builder/refs/heads/main/manifests/tubeszb-zw.yaml)**

#### Flashing Instructions

1.  **Disconnect PoE Power:**
    !!! danger "CRITICAL SAFETY WARNING"
        You **MUST** unplug the ethernet cable providing PoE before connecting the device to your computer via USB. Failure to do so can permanently damage the USB port on the ESP32 board and potentially the USB controller on your computer.

2.  **Access the USB Port:**
    * Remove the lid from the 3D-printed enclosure.
    * Gently lift the end of the boards near the ethernet port to pivot the assembly upwards. This will expose the micro-USB port on the Olimex ESP32-PoE board.

3.  **Connect to Computer:**
    * Connect a micro-USB data cable from the ESP32 board to your computer.

4.  **Flash the Firmware:**
    * **For standard DHCP firmware:** Use the **[TubesZB Web Flasher](https://tube0013.github.io/TubesZB-ESPHome-Builder/)**. Select "TubesZB ZWave Kit" from the dropdown and follow the on-screen instructions to connect and flash.
    * **For a static IP:** You must first build a custom firmware binary. Go to the **[TubesZB ESPHome Builder repository](https://github.com/tube0013/TubesZB-ESPHome-Builder)** and create a new issue using the "ESPHome Static IP Configuration" template. Fill out your network details, and a GitHub Action will automatically compile a firmware for you to download and flash.

### Z-Wave Radio Firmware

Updating the firmware on the Z-Wave radio module itself depends on the model you are using.

#### Zooz ZAC93 Module

The firmware on the Zooz ZAC93 module can be updated directly through the Z-Wave JS UI in Home Assistant.

1.  Obtain the correct firmware file from the **[Zooz OTA Firmware Files page](https://www.support.getzooz.com/kb/article/1158-zooz-ota-firmware-files/)**.
2.  In the Z-Wave JS UI, navigate to the **Control Panel**.
3.  Select your Zooz controller node.
4.  Expand the **Advanced** actions.
5.  Under **Firmware update**, upload the file and begin the process.

#### Z-Wave.me RaZberry 7 Pro Module

Updating the RaZberry module is a more advanced process that currently requires a Raspberry Pi.

1.  Safely shut down your Z-Wave PoE Kit and remove the RaZberry module.
2.  Install the RaZberry module onto the GPIO header of a Raspberry Pi.
3.  Download and install the **[Z-Way software](https://z-wave.me/z-way/download-z-way/)** from Z-Wave.me on the Raspberry Pi.
4.  Access the Z-Way Expert UI in your browser.
5.  Use the built-in firmware update tool within the Expert UI to flash the new firmware onto the module.
6.  Once complete, remove the module from the Raspberry Pi and reinstall it in your Z-Wave PoE Kit.

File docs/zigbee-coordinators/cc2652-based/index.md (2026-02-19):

# CC2652-Based Coordinators

TubesZB CC2652 coordinators use the TI ZNP stack and expose the Zigbee radio over TCP (Ethernet/PoE) or USB. These models work with both ZHA and Zigbee2MQTT.

!!! tip "Start here"
    If you are setting up your coordinator for the first time, begin with the [Getting Started guide for Zigbee coordinators](../../getting-started/zigbee.md).

## Models

| Model | Connection | Radio | ESPHome Builder manifest |
| --- | --- | --- | --- |
| CC2652 PoE 2022 | Ethernet (PoE) | CC2652P2 | [tubeszb-cc2652p2-poe-2022.yaml](https://github.com/tube0013/TubesZB-ESPHome-Builder/blob/main/manifests/tubeszb-cc2652p2-poe-2022.yaml) |
| CC2652 PoE 2023 | Ethernet (PoE) | CC2652P2 | [tubeszb-cc2652p2-poe-2023.yaml](https://github.com/tube0013/TubesZB-ESPHome-Builder/blob/main/manifests/tubeszb-cc2652p2-poe-2023.yaml) |
| CC2652 P7 PoE 2023 | Ethernet (PoE) | CC1352P7 | [tubeszb-cc2652p7-poe-2023.yaml](https://github.com/tube0013/TubesZB-ESPHome-Builder/blob/main/manifests/tubeszb-cc2652p7-poe-2023.yaml) |
| CC2652 Ethernet/USB 2022/2023 | Ethernet or USB | CC2652P2 | [tubeszb-cc2652p2-ethusb-2022.yaml](https://github.com/tube0013/TubesZB-ESPHome-Builder/blob/main/manifests/tubeszb-cc2652p2-ethusb-2022.yaml) and [tubeszb-cc2652p2-ethusb-2023.yaml](https://github.com/tube0013/TubesZB-ESPHome-Builder/blob/main/manifests/tubeszb-cc2652p2-ethusb-2023.yaml) |

!!! note "ESPHome configs moved"
    ESPHome YAMLs in this repo are kept for historical reference and are not expected to compile with current ESPHome versions. Use the ESPHome Builder manifests above for active builds.

## Model Highlights

### CC2652 PoE 2022

Photo: [front view](https://github.com/tube0013/tube_gateways/raw/main/models/current/tubeszb-cc2652-poe-2022/images/tubeszb-cc2652-poe-2022.webp)

- PoE powered Ethernet coordinator
- CC2652P2 radio (ZNP)
- TCP port `6638`

### CC2652 PoE 2023

Photo: [front view](https://github.com/tube0013/tube_gateways/raw/main/models/current/tubeszb-cc2652-poe-2022/images/tubeszb-cc2652-poe-2022.webp)

- PoE powered Ethernet coordinator
- CC2652P2 radio (ZNP)
- TCP port `6638`

### CC2652 P7 PoE 2023

Photo: [front view](https://github.com/tube0013/tube_gateways/raw/main/models/current/tubeszb-cc2652-poe-2022/images/tubeszb-cc2652-poe-2022.webp)

- PoE powered Ethernet coordinator
- CC1352P7 radio (ZNP)
- TCP port `6638`

### CC2652 Ethernet/USB 2022/2023

Photo: [closed view](https://github.com/tube0013/tube_gateways/raw/main/models/current/tubeszb-cc2652-eth_usb/images/tubeszb-cc2652-eth_usb_closed.jpg)

- Works over Ethernet or USB
- CC2652P2 radio (ZNP)
- TCP port `6638` when in Ethernet mode

## Power and Safety

PoE models require a PoE switch or injector and at least 37V DC. USB-only models use standard 5V power.

!!! danger "Do not mix power sources"
    Do not connect PoE and USB power at the same time. Doing so can permanently damage the board or your computer.

## ZHA and Zigbee2MQTT Setup

ZHA setup uses the ZNP radio type and connects over TCP or USB.

ZHA over Ethernet:
`socket://IP_ADDRESS:6638`

ZHA over USB:
Use the `/dev/serial/by-id/...` path shown in Home Assistant Hardware.

Zigbee2MQTT over Ethernet:

```yaml
serial:
  port: 'tcp://IP_ADDRESS:6638'
  adapter: zstack
```

Zigbee2MQTT over USB:

```yaml
serial:
  port: '/dev/serial/by-id/usb-1a86_TubesZB_XXXXXXXX-if00-port0'
  adapter: zstack
```

## Firmware Updates

ESP32 firmware updates now use the TubesZB ESPHome Builder and the device web UI or the ESPHome Web Flasher. The standalone ESPHome Flasher app is no longer maintained.

See [Coordinator Firmware Updates](../firmware-updates.md) for the current workflow.

## CC2652 Ethernet/USB Jumper Modes

These images apply to the CC2652 Ethernet/USB coordinator.

Zigbee over Ethernet (serial over TCP):

<figure markdown>
  Zigbee to Ethernet jumpers
  <figcaption>Jumpers closest to the female headers route Zigbee to Ethernet.</figcaption>
</figure>

Zigbee over USB:

<figure markdown>
  Zigbee to USB jumpers
  <figcaption>Middle jumpers route Zigbee to USB.</figcaption>
</figure>

ESP32 flashing mode:

<figure markdown>
  ESP32 flashing jumpers
  <figcaption>Jumpers farthest from the female headers route the ESP32 serial to USB.</figcaption>
</figure>

Zigbee over Ethernet with ESP32 debug over USB:

<figure markdown>
  Zigbee to Ethernet and ESP32 debug
  <figcaption>Two jumper pairs enable Zigbee over Ethernet while keeping ESP32 debug on USB.</figcaption>
</figure>

## Legacy Models

Retired CC2652 coordinators and legacy instructions are kept in the legacy page.

See [CC2652 Legacy Models](legacy.md).

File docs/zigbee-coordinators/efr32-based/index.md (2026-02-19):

# EFR32-Based Coordinators

TubesZB EFR32 coordinators use Silicon Labs EZSP (Ember) radios and expose the Zigbee interface over TCP (Ethernet/PoE) or USB depending on model. These models work with ZHA and Zigbee2MQTT.

!!! tip "Start here"
    If you are setting up your coordinator for the first time, begin with the [Getting Started guide for Zigbee coordinators](../../getting-started/zigbee.md).

## Models

| Model | Connection | Radio | Photo | ESPHome Builder manifest |
| --- | --- | --- | --- | --- |
| EFR32 MGM210 PoE 2022/2023 | Ethernet (PoE) | EZSP | [enclosure reference](https://github.com/tube0013/tube_gateways/raw/main/models/current/tubeszb-cc2652-poe-2022/images/tubeszb-cc2652-poe-2022.webp) | [tubeszb-efr32-mgm210-poe-2022.yaml](https://github.com/tube0013/TubesZB-ESPHome-Builder/blob/main/manifests/tubeszb-efr32-mgm210-poe-2022.yaml) and [tubeszb-efr32-mgm210-poe-2023.yaml](https://github.com/tube0013/TubesZB-ESPHome-Builder/blob/main/manifests/tubeszb-efr32-mgm210-poe-2023.yaml) |
| EFR32 MGM24 2023 | Ethernet (PoE) | EZSP | [connection diagram](https://github.com/tube0013/tube_gateways/raw/main/images/efr32_connection.png) | [tubeszb-efr32-mgm24-2023.yaml](https://github.com/tube0013/TubesZB-ESPHome-Builder/blob/main/manifests/tubeszb-efr32-mgm24-2023.yaml) |
| EFR32 MGM12 2022 | Ethernet or USB | EZSP | [front view](https://github.com/tube0013/tube_gateways/raw/main/models/current/tubeszb-efr32-MGM12-eth_usb/images/tubeszb-efr32-MGM12P-eth_usb.webp) | Not yet in the ESPHome Builder manifests |

!!! note "ESPHome configs moved"
    ESPHome YAMLs in this repo are kept for historical reference and are not expected to compile with current ESPHome versions. Use the ESPHome Builder manifests when available.

## Model Highlights

### EFR32 MGM210 PoE 2022/2023

Photo: [enclosure reference](https://github.com/tube0013/tube_gateways/raw/main/models/current/tubeszb-cc2652-poe-2022/images/tubeszb-cc2652-poe-2022.webp)

- PoE powered Ethernet coordinator
- EZSP radio
- TCP port `6638`

### EFR32 MGM24 2023

Photo: [connection diagram](https://github.com/tube0013/tube_gateways/raw/main/images/efr32_connection.png)

- PoE powered Ethernet coordinator
- EZSP radio
- TCP port `6638`

### EFR32 MGM12 2022

Photo: [front view](https://github.com/tube0013/tube_gateways/raw/main/models/current/tubeszb-efr32-MGM12-eth_usb/images/tubeszb-efr32-MGM12P-eth_usb.webp)

- Ethernet or USB connectivity
- EZSP radio
- TCP port `6638` when in Ethernet mode

## ZHA and Zigbee2MQTT Setup

ZHA setup uses the EZSP radio type and connects over TCP or USB.

ZHA over Ethernet:
`socket://IP_ADDRESS:6638`

ZHA over USB:
Use the `/dev/serial/by-id/...` path shown in Home Assistant Hardware.

Zigbee2MQTT over Ethernet:

```yaml
serial:
  port: 'tcp://IP_ADDRESS:6638'
  adapter: ember
```

Zigbee2MQTT over USB:

```yaml
serial:
  port: '/dev/serial/by-id/usb-1a86_TubesZB_XXXXXXXX-if00-port0'
  adapter: ember
```

!!! note "Zigbee2MQTT firmware requirement"
    Zigbee2MQTT requires EFR32 coordinator firmware 7.4.x or newer.

## Firmware Updates

ESP32 firmware updates now use the TubesZB ESPHome Builder and the device web UI or the ESPHome Web Flasher. The standalone ESPHome Flasher app is no longer maintained.

See [Coordinator Firmware Updates](../firmware-updates.md) for the current workflow.

## Legacy Settings and Jumpers

Legacy EFR32 settings and jumper references are documented separately.

See [EFR32 Legacy Reference](legacy.md).

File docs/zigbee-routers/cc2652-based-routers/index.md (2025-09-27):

# TubesZB CC2652P2 Zigbee Router

This page contains technical details for the TubesZB CC2652P2 Zigbee Router, including factory reset and firmware update procedures.

---

## Device Operations

### Factory Reset

If you need to re-pair the router or start fresh, you can perform a factory reset.

1.  Carefully open the router's enclosure to access the circuit board.
2.  Locate the small button labeled **BSL** (Boot Strap Loader).
3.  With the router powered on, give the **BSL** button a single, quick press.

The device will reset and should immediately enter pairing mode again.

---

## Firmware Updates

Updating the firmware on the CC2652P2 module requires a physical connection to a computer and the use of a specific flashing tool.

**Required Tool:** [cc2538-bsl.py](https://github.com/JelmerT/cc2538-bsl)

The flashing process differs slightly depending on whether your router has a USB-C or a Micro-USB port.

### Flashing a Router with a USB-C Port

Newer routers with a USB-C port have a built-in serial-to-USB converter, which simplifies the process.

1.  Press and hold the **BSL** button on the router's circuit board.
2.  While still holding the button, plug the router into your computer using a USB-C cable.
3.  Continue holding the BSL button for about 10 seconds, then release. The device is now in bootloader mode.
4.  Use the `cc2538-bsl.py` tool to flash the new firmware.

### Flashing a Router with a Micro-USB Port

Older routers with a Micro-USB port require an external USB-to-Serial adapter for flashing.

!!! warning "Serial Adapter Required"
    You will need a 3.3V USB-to-Serial TTL adapter to flash this device. Adapters using CP210x, CH340, or FTDI chips are common and will work.
    * [Example CP2102 USB to TTL module (Affiliate Link)](https://amzn.to/3HjQ7bx)

#### Flashing Steps

1.  **Connect the Adapter:** Use dupont jumper wires to connect your serial adapter to the router's programming pins. The connection order is critical:

| Serial Adapter | Router Pin |
| :--- | :--- |
| 3.3V | 3.3V |
| GND | GND |
| RX | TX |
| TX | RX |

2.  **Enter Bootloader Mode:**
    * Plug the USB-to-Serial adapter into your computer.
    * Press and hold the **BSL** button on the router.
    * While holding the button, slide the 4 connected dupont wires over the corresponding pins on the router.
    * Release the BSL button. The device is now in bootloader mode.

3.  **Flash the Firmware:** Use the `cc2538-bsl.py` tool to flash the new firmware.

    TubesZB Router FW Update Wiring Setup (https://youtu.be/OCORSnwCDtw "TubesZB Router FW Update Wiring Setup")

#### Example Flash Command

The command will look similar to this. Replace the port and file path with your own.

```bash
cc2538-bsl.py -p /dev/cu.usbserial-00F9450F -evw /PATH_TO/tubeszb_router_20220111.hex

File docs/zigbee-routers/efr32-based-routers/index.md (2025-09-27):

# EFR32 Based Zigbee Router

This page contains technical details for the Tube's EFR32 based Zigbee Routers, including button functions and firmware update procedures.

---

## Getting Started

Initial pairing is simple and works the same way as other TubeZB routers. Please follow the main router getting started guide for instructions.

[:octicons-arrow-right-24: View Router Getting Started Guide](../../getting-started/router.md)

---

## Device Operations

The single button on the EFR32 router has multiple functions depending on the state of the device and the duration of the press.

!!! tip "Settings are Temporary"
    Toggled statuses from a short button press (like network steering) only remain active while the router is powered on. Power cycling the router will reset it to its default behavior.

### If the Router is NOT Joined to a Network:

* **Short Press:** Toggles "Network Steering". This starts or stops the router's attempt to find and join a Zigbee network. This is useful if you want to power on the device without it immediately trying to pair.
* **Long Press (>5s):** Reboots the router into bootloader mode. This is used to prepare the device for a firmware update.

### If the Router IS Joined to a Network:

* **Short Press:** Toggles "Source Route Discovery". This is an advanced feature that is generally not needed for most networks. It starts/stops the broadcasting of MTORRs (Many-to-One Route Requests).
* **Long Press (>5s):** Makes the router leave its current Zigbee network. It will need to be re-paired after this action.

---

## Firmware Updates

### Firmware Source

The recommended firmware for these routers is developed by Nerivec and is available for download from the **[silabs-firmware-builder releases page](https://github.com/Nerivec/silabs-firmware-builder/releases)**.

### Flashing Methods

There are two primary methods for flashing firmware to the EFR32 routers.

#### Method 1: Universal Silicon Labs Flasher (Advanced)

This is a Python-based command-line tool for flashing Silicon Labs devices. It is a powerful tool for users who are comfortable working in a terminal.

1.  **Install the Tool:** Follow the installation instructions on the **[Universal Silicon Labs Flasher GitHub page](https://github.com/NabuCasa/universal-silabs-flasher/)**.
2.  **Enter Bootloader Mode:** Before flashing, you must put the router into bootloader mode. While the device is powered on, press and hold the button for more than 5 seconds until the LED changes.
3.  **Run the Flasher:** Use the tool to flash the downloaded firmware file. The command will look something like this:
    ```bash
    universal-silabs-flasher --device /dev/tty.usbmodem1101 flash --firmware your-firmware-file.gbl
    ```

#### Method 2: Tube's Home Assistant Addon (Recommended for HA Users)

For users running Home Assistant OS or Supervised, the easiest method is to use the TubesZB Addon, which provides a user-friendly interface for flashing.

1.  Install the **[TubesZB Addon Repository](https://github.com/tube0013/tubeszb_addons)** in Home Assistant.
2.  Install the appropriate flashing utility from the addon store.
3.  Follow the instructions within the addon's documentation to flash your router.

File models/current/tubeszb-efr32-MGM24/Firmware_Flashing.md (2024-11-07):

# Flashing Firware on a TubesZB MGM24 Coordinator using Universal-silabs-flasher

This guide provides step-by-step instructions for flashing a Network Co-Processor (NCP) `.gbl` firmware file to the Tube's Zigbee MGM24 PoE Coordinator over a remote TCP socket using the `universal-silabs-flasher`.

If you use HAOS and can install addons I recommend you use the [TubesZB Silicon Labs Flasher Add-on](https://github.com/tube0013/tubeszb_addons/blob/main/tzb-silabs-flasher/DOCS.md)

## Requirements

- **Tube's Zigbee MGM24 PoE Coordinator**
- **NCP `.gbl` file** for the MGM24 (e.g., `your_firmware.gbl`)  
  - You can download the latest `.gbl` firmware files from the [Tube Gateways Firmware Repository](https://github.com/tube0013/tube_gateways/tree/main/models/current/tubeszb-efr32-MGM24/firmware/mgm24/ncp).
- **Universal Silabs Flasher** software
- A computer with **Python 3.7+**
- **IP Address and Port** of the remote device socket

## Installation

### Step 1: Set Up a Python Virtual Environment

1. **Install Python 3.7+**  
   Make sure Python 3.7 or higher is installed. You can check your version by running:  
   ```python3 --version```

2. **Create a Virtual Environment**  
   In the directory where you want to set up the project, create a virtual environment:  
   ```python3 -m venv env```

3. **Activate the Virtual Environment**  
   - On **Linux/macOS**:  
     ```source env/bin/activate```
   - On **Windows**:  
     ```.\env\Scripts\activate```

   You should now see `(env)` at the beginning of your command line, indicating that the virtual environment is active.

### Step 2: Install Universal Silabs Flasher

Install `universal-silabs-flasher` directly from PyPI:  
```pip install universal-silabs-flasher```

For more details, you can visit the [universal-silabs-flasher GitHub repository](https://github.com/NabuCasa/universal-silabs-flasher).

## Flashing the Firmware Over a TCP Socket

1. **Get the Device IP Address and Port**  
   Ensure you have the correct IP address and port for the MGM24 Coordinator's remote TCP socket.

2. **Disable ZHA/Zigbee2MQTT**
   Ensure no services are connecting to the TCP Serial Port. You can check this by going to the coordinator's web frontend and observing the Serial Connected sensor state.

3. **Flash the NCP `.gbl` File**  
   Use `universal-silabs-flasher` to flash the `.gbl` file to the MGM24 Coordinator over the TCP socket by specifying the address in `socket://IP_ADDRESS:PORT` format:  
   ```universal-silabs-flasher --device socket://<IP_ADDRESS>:<PORT> --bootloader-baudrate 115200 --ezsp-baudrate 115200 flash --firmware--firmware your_firmware.gbl```

   Replace `<IP_ADDRESS>` and `<PORT>` with the actual IP address and port of your coordinator, and `your_firmware.gbl` with the path to your `.gbl` file.

   **Example Command:**  
   ```universal-silabs-flasher --device socket://192.168.1.100:6638 --bootloader-baudrate 115200 --ezsp-baudrate 115200 flash --firmware--firmware your_firmware.gbl```

4. **Wait for Flashing to Complete**  
   The flashing process will take a minute or 2 to complete. Once finished, you should see the progress bar showing 100% indicating that the firmware has been flashed successfully.

5. **Deactivate the Virtual Environment**  
   After you're done, you can deactivate the virtual environment by running:  
   ```deactivate```

6. **Restart ZHA/Zigbee2MQTT**
   Check logs for any errors.

## Troubleshooting

- **Errors*  
  Make sure ZHA or Zigbee2MQTT are shutdown and nothing is accessing the TCP Serial Port
  Ensure that the coordinator is properly connected and that the correct IP address and port are specified.

---

## Additional Resources

- [TubesZB GitHub Resository](https://github.com/tube0013/tube_gateways)
- [Universal Silabs Flasher GitHub Repository](https://github.com/NabuCasa/universal-silabs-flasher)
- [Latest NCP Firmware Files for MGM24 Coordinators](https://github.com/tube0013/tube_gateways/tree/main/models/current/tubeszb-efr32-MGM24/firmware/mgm24/ncp)

---

This guide should help you flash the NCP firmware to the Tube's Zigbee MGM24 PoE Coordinator over a TCP socket using a Python virtual environment.

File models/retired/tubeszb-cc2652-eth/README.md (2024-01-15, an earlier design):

## Zigbee Module Firmware Updates:
This section relates to updating the firmware of the zigbee module. If you have an adapter WITH Ethernet and want to update the firmware of the ESP32 Ethernet module then go back to the top of this page and select the links to the firmware for the product you have. These links also have further information for how to flash the zigbee module and should be read in conjunction with the below https://github.com/tube0013/tube_gateways#current-products

**CC2652p based Gateways:**  
Firmware - use the **CC1352P2_CC2652P_launchpad_*.zip** based firmware available here:  
https://github.com/Koenkk/Z-Stack-firmware/tree/master/coordinator/Z-Stack_3.x.0/bin

**Both Zigbee2MQTT and ZHA have automatic backups. It is still advised to confirm/save ahead of a FW update **
For ZHA, go to Settings > Devices & Services > ZHA - Cnnfigure and Click Download Backup

For Z2M check he Z2M Config folder for a backup.json or similar named file, and check the date stamp. If not recent shutdown and restart Z2M to generate a more current version.

Use the cc2538-bsl programmer available here: https://github.com/JelmerT/cc2538-bsl
(Please note the Dependecies called out on the cc2538-bsl main page: https://github.com/JelmerT/cc2538-bsl#dependencies )

**Ethernet version :**
1. Prep the Module for firmware update:

Click the button to intiate the bootloader mode for the module:



Watch the Debug output and when pompted go to step 2.



2. Run the cc2538-bsl programmer:
```
cc2538-bsl.py -p socket://tube_zb_gw_cc2652p2.local:6638  -evw ../CC1352P2_CC2652P_launchpad_20210120.hex
Opening port socket://tube_zb_gw_cc2652p2.local:6638, baud 500000
Reading data from ../CC1352P2_CC2652P_launchpad_20210120.hex
Your firmware looks like an Intel Hex file
Connecting to target...
CC1350 PG2.0 (7x7mm): 352KB Flash, 20KB SRAM, CCFG.BL_CONFIG at 0x00057FD8
Primary IEEE Address: 00:12:4B:00:21:B4:97:D8
    Performing mass erase
Erasing all main bank flash sectors
    Erase done
Writing 360448 bytes starting at address 0x00000000
Write 104 bytes at 0x00057F980
    Write done
Verifying by comparing CRC32 calculations.
    Verified (match: 0xdb4192ef)
```

## ESP32 Serial Flash

You will need an Serial to USB TTL adaptor - I use one similar to this one and it works well: [CP2102 USB to TTL modules](https://amzn.to/3HjQ7bx)

Grab the current esp fw bin file: https://github.com/tube0013/tube_gateways/tree/main/models/retired/tubeszb-cc2652-eth/firmware/esphome

I use the esphome flasher tool which works well for me:
https://github.com/esphome/esphome-flasher/releases

you’ll need 3 jumper wires, the board has pins, so will need females on that end and female/male on the other depending on your Serial TTL adaptor board.

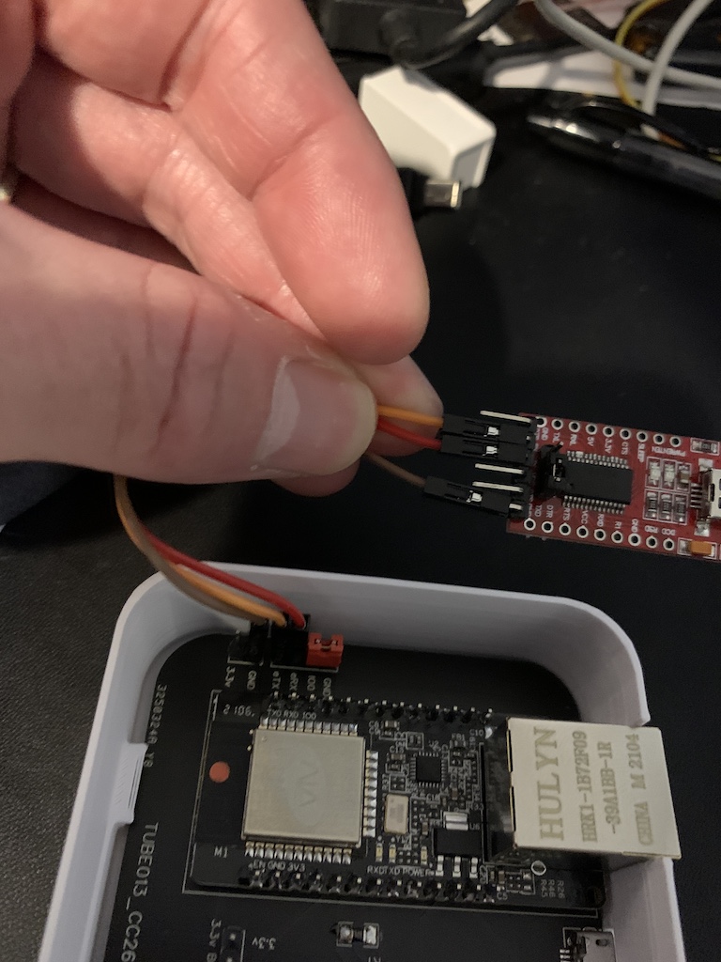
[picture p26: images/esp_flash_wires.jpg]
  

TX on the Serial TTL adaptor goes to the eRX pin on the board (red wire in pic)

RX on the Serial TTL adaptor goes to the eTX pin on the board (orange wire in pic)

Ground from the Serial TTL adaptor goes to the Ground pin on the board (closest to 3.3v) (brown wire in pic)

Use the jumper from the 3.3v_Bridge on the board (or another female to female jumper wire) to bridge the ground and IO0 pins (the spacing is tight I found tweezer so pinch nosed pliers best for adding the jumper)

Once all that is connected up, power on by plugging in the micro usb or by using a 4th jumper wire to connect the 3.3 volts on the Serial TTL adaptor to the 3.3v pin on the board.

## Flashing

Fire up the flasher and select the correct port and point it to the downloaded FW bin:

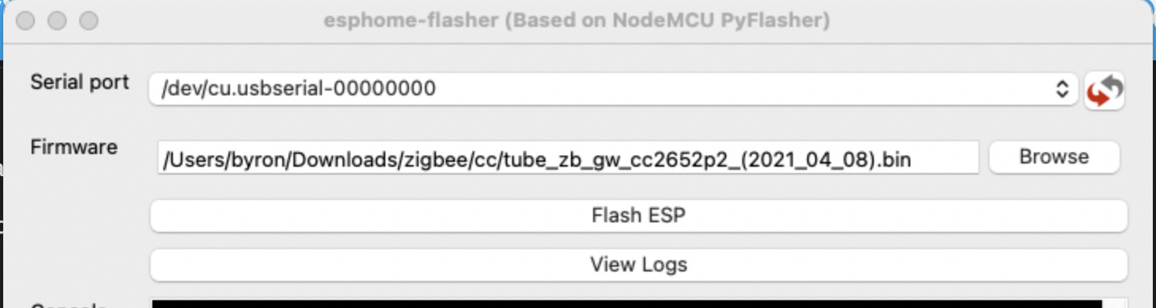
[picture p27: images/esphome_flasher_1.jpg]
  

Hit flash, and you should see something like this:

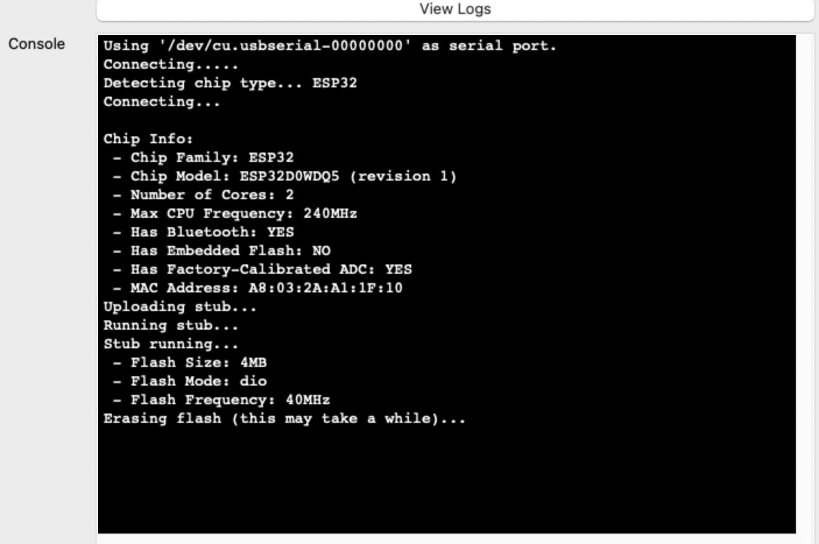
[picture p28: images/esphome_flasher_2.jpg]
  

after about a minute or so:

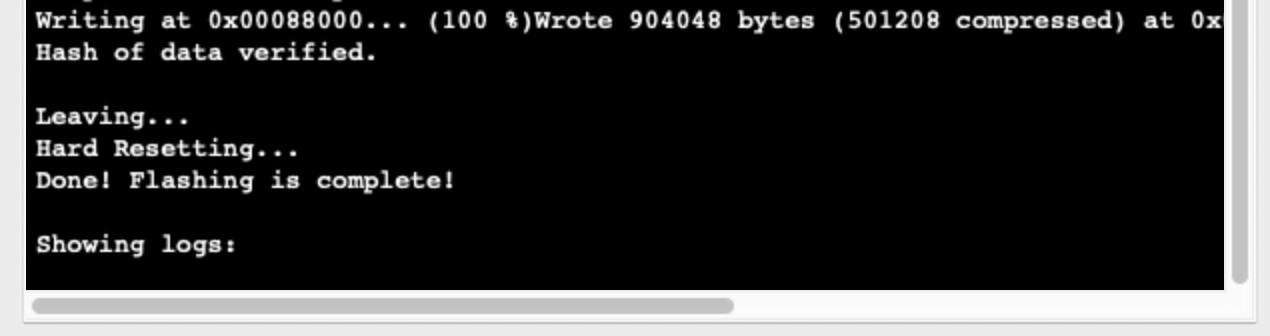
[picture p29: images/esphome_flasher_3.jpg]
  

pull the power, and move the jumper back to the 3.3v_Bridge. you can leave the cables connected to do a test boot with serial logging if you want. Just plug it back in, and hit the show logs button in the flasher:

you should see something like this if not connected to ethernet, or maybe on it’s first try of connecting:

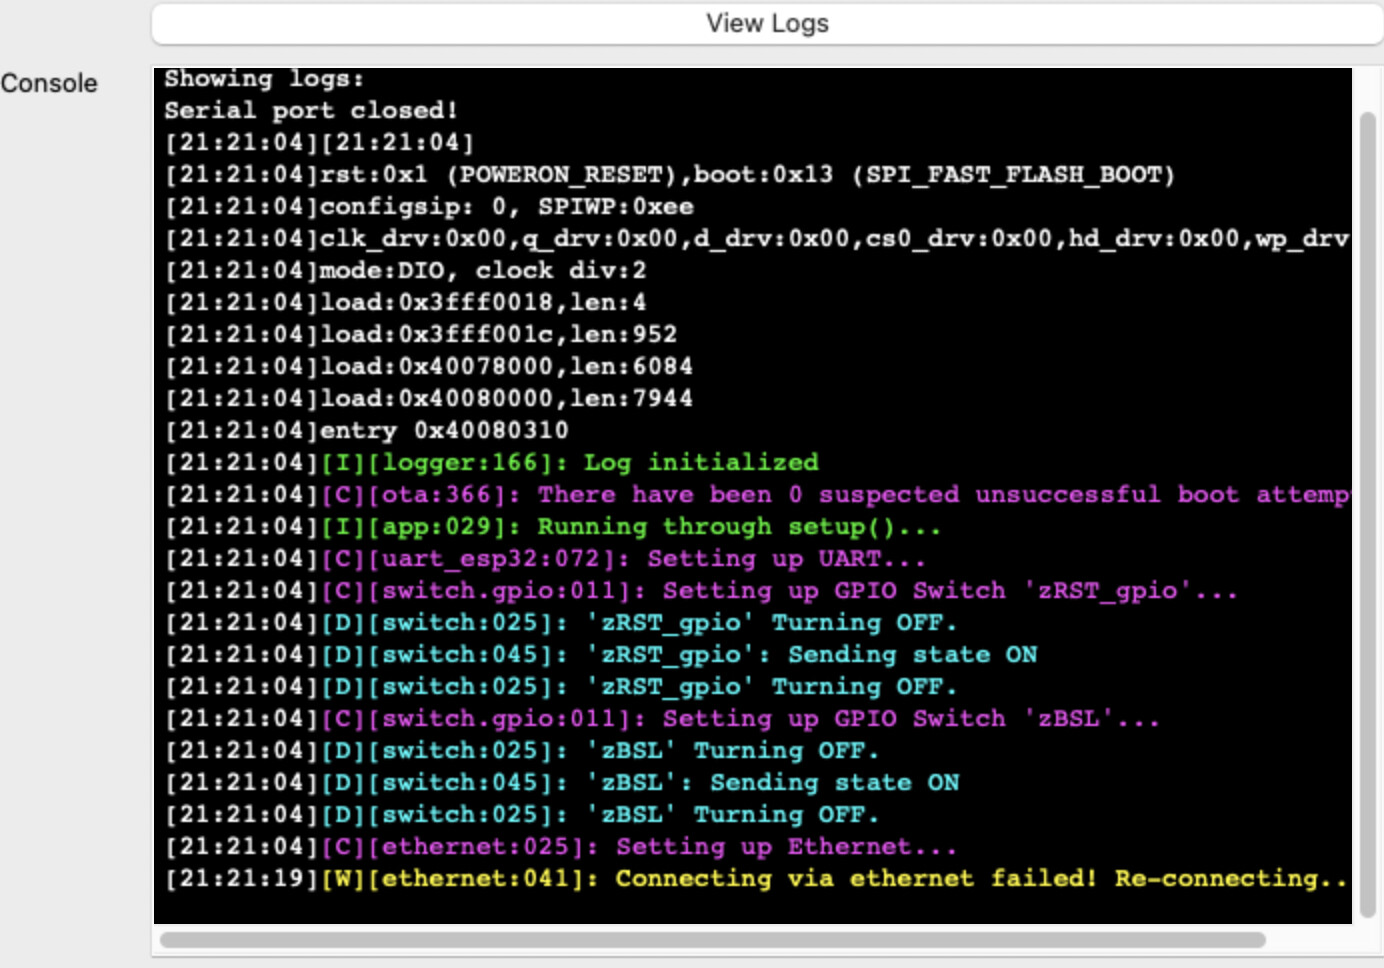
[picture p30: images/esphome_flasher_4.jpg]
  

if connected to network, should see something like this:

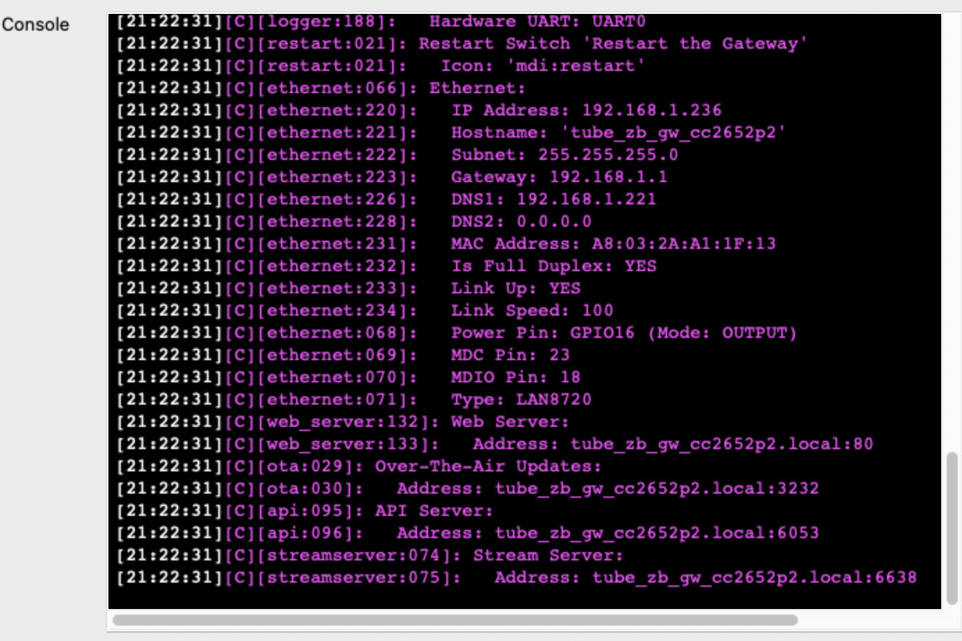
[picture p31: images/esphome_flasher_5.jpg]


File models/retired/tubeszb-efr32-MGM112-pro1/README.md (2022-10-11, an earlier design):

# Specific Configuration for the Tube EFR32 Gateways
Because the EFR32 gateways uses some firrmware settings different than the bellows defaults it is recommended set them in the configuration.yaml so bellows will utilize them.

## For EFR32 Pro and Series 2 Gateways with 6.9.1 based firmware (shippied before June 2021)
**Add these lines to your configuration.yaml file:**

```
zha:
  zigpy_config:
    source_routing: true
    ezsp_config:
      CONFIG_APS_UNICAST_MESSAGE_COUNT: 30
      CONFIG_MAX_END_DEVICE_CHILDREN: 64
      CONFIG_SOURCE_ROUTE_TABLE_SIZE: 200
      CONFIG_ROUTE_TABLE_SIZE: 16
      CONFIG_ADDRESS_TABLE_SIZE: 32
      CONFIG_PACKET_BUFFER_COUNT: 254
      CONFIG_BINDING_TABLE_SIZE: 32
      CONFIG_NEIGHBOR_TABLE_SIZE: 26
```

**Note if using HA lower than 2021.03.x you will need to use lower values as bellows was not able to use the higher values until the release bundled with 2021.03.**

Use these lines if using HA < 2021.03

```
zha:
  zigpy_config:
    source_routing: true
    ezsp_config:
      CONFIG_APS_UNICAST_MESSAGE_COUNT: 30
      CONFIG_MAX_END_DEVICE_CHILDREN: 32
      CONFIG_SOURCE_ROUTE_TABLE_SIZE: 200
      CONFIG_ROUTE_TABLE_SIZE: 16
      CONFIG_ADDRESS_TABLE_SIZE: 32
      CONFIG_PACKET_BUFFER_COUNT: 254
      CONFIG_BINDING_TABLE_SIZE: 32
      CONFIG_NEIGHBOR_TABLE_SIZE: 16
```

# Using the onboard headers/jumpers to select the serial output

The 2 groups of four headers control the connection of the serial.

  eTX and eRX connect to the esp’s main/flashing serial connection * *see note below*

  sTX and sRX are the TX and RX pins on the built I serial module.

  zTX and zRX are the TX and RX pins on the zigbee modules

  ezTX and ezRX are the secondary uart pins for the esp for use when running the coordinator through Ethernet

Jumpers all the way toward to esp module as pictured the serial runs to the esp for network usage:

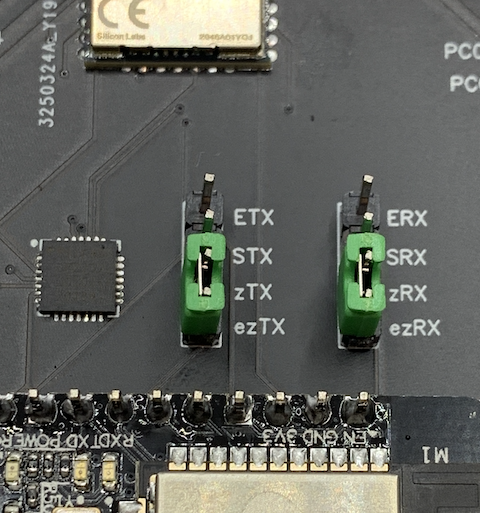
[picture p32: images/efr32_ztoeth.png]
 

Move the jumpers to the middle two pins and the zigbee serial goes through the embedded serial converter:

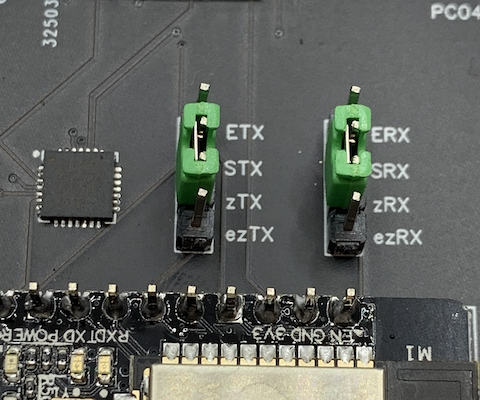
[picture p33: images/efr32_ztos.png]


*My goal was to have the esp’s main flashing/log console serial connection available by moving it all the way to the other side however I messed up the TX>RX and RX>TX here (and it’s the one place I can’t fix it with firmware) so jumpers are needed to connect the sTX to the eRX in the other row and the sRX to the eTX. Then the esp is available over serial and the log for esphome should show when connected to serial.

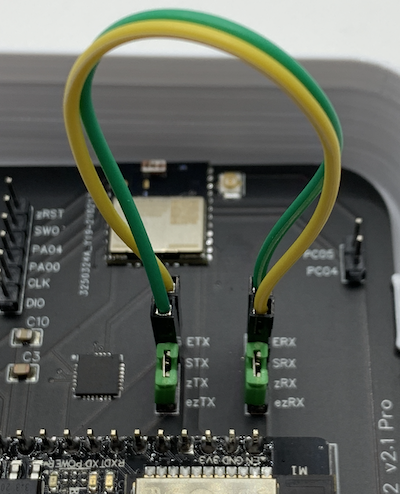
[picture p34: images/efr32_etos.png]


Finaly by connecting ground to IO0, you and powering up the gw, the ESP32 will be in flash mode and flashable over serial if needed.

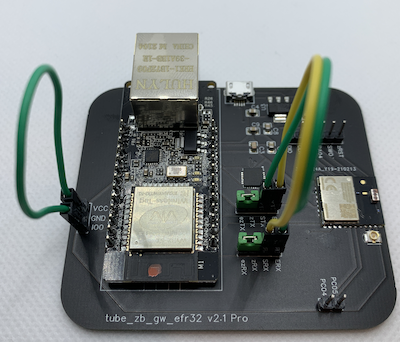
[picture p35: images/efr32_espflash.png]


**EFR32 Firmware Updates:**

https://www.youtube.com/watch?v=zKrISuWEzL4tube-

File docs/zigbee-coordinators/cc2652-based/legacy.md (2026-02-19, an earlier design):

# CC2652 Legacy Models

This page collects retired CC2652-based coordinators and legacy references. These models are no longer actively updated.

!!! note "Historical reference only"
    Files in the model folders are kept for historical reference and may not compile with current ESPHome versions.

## Retired Models

- CC2652 Ethernet (original)
- CC2652 PoE (original)
- CC2652 PoE ISO
- CC2652 USB

If you still operate a retired model, use the same Zigbee setup flow as current CC2652 models and refer to the coordinator firmware update instructions when needed.

See [Coordinator Firmware Updates](../firmware-updates.md).

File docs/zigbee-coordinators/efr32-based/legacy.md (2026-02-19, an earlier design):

# EFR32 Legacy Reference

This page captures legacy settings and jumper references for retired EFR32-based coordinators.

!!! note "Historical reference only"
    These settings apply to older 6.9.x firmware and pre-2021 Home Assistant builds. Current models usually do not need them.

## Legacy Jumper Reference (EFR32 Pro and Series 2)

Zigbee serial routed to Ethernet (ESP32):

<figure markdown>
  EFR32 Zigbee to Ethernet
  <figcaption>Jumpers toward the ESP32 route Zigbee serial to Ethernet.</figcaption>
</figure>

Zigbee serial routed to the onboard USB serial adapter:

<figure markdown>
  EFR32 Zigbee to Serial
  <figcaption>Middle jumpers route Zigbee serial to the USB adapter.</figcaption>
</figure>

ESP32 flashing mode:

<figure markdown>
  EFR32 ESP32 flashing
  <figcaption>Ground IO0 during boot to enter ESP32 flash mode.</figcaption>
</figure>

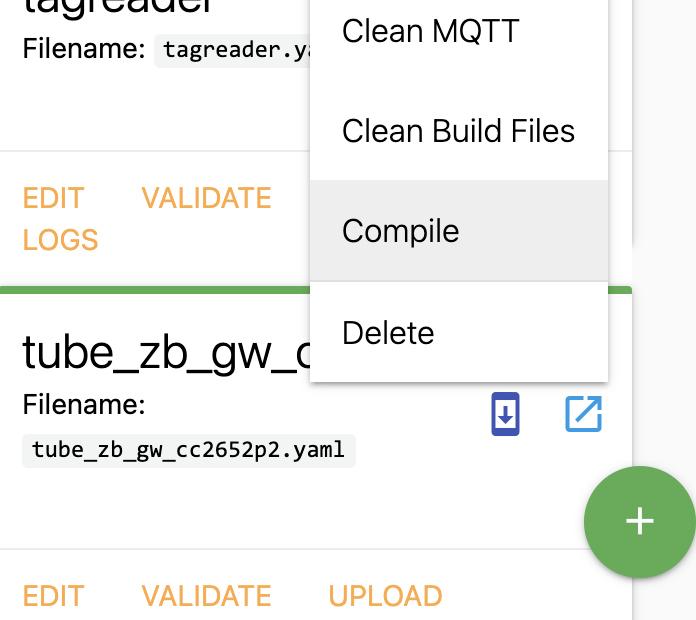
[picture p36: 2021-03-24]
images/esphome2.png

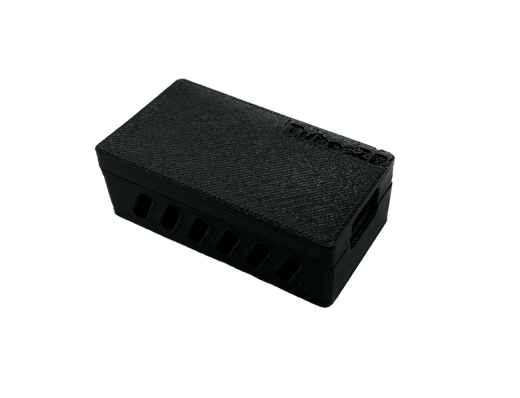
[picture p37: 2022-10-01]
models/current/tubeszb-wt32-eth01-bt-kit/images/WT32_BT_1.png

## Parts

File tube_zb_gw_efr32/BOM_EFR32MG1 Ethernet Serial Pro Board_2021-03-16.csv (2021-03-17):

ID | Name | Designator | Footprint | Quantity | Manufacturer Part | Manufacturer
1 | 10uF | C2,C3 | C0805 | 2 | 0805F106M160NT | FH
2 | 100nF | C4,C5,C6,C8 | C0805 | 4 | CL21B104KCFNNNE | SAMSUNG
3 | 4.7uF | C7 | C0805 | 1 | C0805C475K4RACAUTO | KEMET
4 | Header-Male-2.54_1x6 | H1 | HDR-TH_6P-P2.54-V | 1 | Header-Male-2.54_1x6 | BOOMELE
5 | Header-Male-2.54_1x4 | H2,H4 | HDR-TH_4P-P2.54-V | 2 | 210S-1*4P L=11.6MMGold-plated black | Ckmtw
6 | Header-Male-2.54_1x3 | H5 | HDR-TH_3P-P2.54-V | 1 | Header2.54mm 1*3P | BOOMELE
7 | WT32-ETH01 | U1 | WT32-ETH01 | 1 | WT32-ETH01 | Wireless-Tag
8 | MGM12P22F1024GA-V2 | U2 | WIRELM-SMD_MGM12P22F1024GA-V2 | 1 | MGM12P22F1024GA-V2 | SILICON LABS
9 | AMS1117-3.3_C165482 | U3 | SOT-223_L6.5-W3.5-P2.30-LS7.0-BR | 1 | AMS1117-3.3 | SK
10 | CP2102-GMR | U5 | QFN-28_L5.0-W5.0-P0.50-BL-EP | 1 | CP2102-GMR | SILICON LABS
11 | micro USBFemale | USB1 | MICRO-USB-SMD_5P-P0.65-H-F_C10418 | 1 | micro USBFemale | ValuePro

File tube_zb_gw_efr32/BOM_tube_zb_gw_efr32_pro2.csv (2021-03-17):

ID | Name | Designator | Footprint | Quantity | Manufacturer Part | Manufacturer
1 | 10uF | C2,C3 | C0805 | 2 | 0805F106M160NT | FH
2 | 100nF | C4,C8,C9,C10 | C0805 | 4 | CL21B104KCFNNNE | SAMSUNG
3 | 4.7uF | C11 | C0805 | 1 | C0805C475K4RACAUTO | KEMET
4 | U.FL-R-SMT-1 | CN1 | U.FL-R-SMT-1 | 1 | U.FL-R-SMT-1 | Hirose Electric Co Ltd
5 | Header-Male-2.54_1x6 | H1 | HDR-TH_6P-P2.54-V | 1 | Header-Male-2.54_1x6 | BOOMELE
6 | Header-Male-2.54_1x4 | H2,H4 | HDR-TH_4P-P2.54-V | 2 | 210S-1*4P L=11.6MMGold-plated black | Ckmtw
7 | Header-Male-2.54_1x2 | H3 | HDR-TH_2P-P2.54-V | 1 | 826629-2 | TE Connectivity
8 | Header-Male-2.54_1x3 | H5 | HDR-TH_3P-P2.54-V | 1 | Header2.54mm 1*3P | BOOMELE
9 | WT32-ETH01 | U2 | WT32-ETH01 | 1 | WT32-ETH01 | Wireless-Tag
10 | AMS1117-3.3_C165482 | U3 | SOT-223_L6.5-W3.5-P2.30-LS7.0-BR | 1 | AMS1117-3.3 | SK
11 | MGM210PA32JIA2 COPY | U4 | MGM210PA32JIA2 | 1 | MGM210PA32JIA2 | Silicon Labs
12 | CP2102-GMR | U5 | QFN-28_L5.0-W5.0-P0.50-BL-EP | 1 | CP2102-GMR | SILICON LABS
13 | micro USBFemale | USB1 | MICRO-USB-SMD_5P-P0.65-H-F_C10418 | 1 | micro USBFemale | ValuePro

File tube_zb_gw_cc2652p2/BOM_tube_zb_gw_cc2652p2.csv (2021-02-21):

ID | Name | Designator | Footprint | Quantity | Manufacturer Part
1 | DEBUG | H3 | HEADER 1X9_2.54 | 1
2 | 10K | R1 | 1206 | 1 | 1206W4J0103T5E
3 | micro USBFemale | USB1 | MICRO-USB-SMD_5P-P0.65-H-F_C10418 | 1 | micro USBFemale
4 | Header-Male-2.54_1x4 | H2 | HDR-TH_4P-P2.54-V | 1 | 210S-1*4P L=11.6MMGold-plated black
5 | WT32-ETH01 | U2 | WT32-ETH01 | 1 | WT32-ETH01
6 | 100 | R4 | R0805 | 1 | 080500F1000T5E
7 | Header-Male-2.54_1x2 | H1 | HDR-TH_2P-P2.54-V | 1 | 826629-2
8 | 3.3v_Jumper | H4 | HDR-TH_2P-P2.54-V | 1 | 826629-2
9 | cc2652 Modul | U1 | RF-BM-2652P2 | 1 | RF-star
10 | SKRKAEE020 | BSL | SW-SMD_L3.9-W3.0-P4.45 | 1 | SKRKAEE020

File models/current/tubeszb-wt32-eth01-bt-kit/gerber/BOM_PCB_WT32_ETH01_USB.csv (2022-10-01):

뿯붿ID | Name | Designator | Footprint | Quantity | Manufacturer Part | Manufacturer | Supplier | Supplier Part
1 | 10uF | C2,C3 | C0805 | 2 | 0805F106M160NT | FH | LCSC | C90545
2 | 100nF | C4,C8 | C0805 | 2 | CL21B104KCFNNNE | SAMSUNG | LCSC | C28233
3 | BC817 | Q1,Q2 | SOT-23(SOT-23-3) | 2 | BC817 | CJ | LCSC | C8589
4 | 5.1K | R2,R3 | R0805 | 2 | 0805W8F5101T5E | UniOhm | LCSC | C27834
5 | 10K | R13,R14 | 0805 | 2 | RC0805DR-0710KL | YAGEO | LCSC | C163503
6 | CH34䌰∀ऀ∀唀㄀∀ऀ∀匀伀䤀䌀ⴀ㄀㘀开䰀㤀⸀㤀ⴀ圀㌀⸀㤀ⴀ倀㄀⸀㈀㜀ⴀ䰀匀㘀⸀ ⴀ䈀䰀∀ऀ∀㄀∀ऀ∀䌀䠀㌀㐀 䌀∀ऀ∀圀䌀䠀∀ऀ∀䰀䌀匀䌀∀ऀ∀㡃㘴ㄸ
7 | AMS1117-3.3_C165482 | U3 | SOT-223_L6.5-W3.5-P2.30-LS7.0-BR | 1 | AMS1117-3.3 | SK | LCSC | C165482
8 | TYPE-C-31-M-12 | USBC1 | USB-C_SMD-TYPE-C-31-M-12 | 1 | TYPE-C-31-M-12 | Rectangular Connectors - Contacts | LCSC | C165948
�

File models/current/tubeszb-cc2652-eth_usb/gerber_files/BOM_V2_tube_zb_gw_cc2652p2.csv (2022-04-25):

ID | Name | Designator | Footprint | Quantity | Manufacturer Part | Manufacturer
1 | U254-051N-4BH806 | USB1 | MICRO-USB-SMD_U254-051N-4BH806 | 1 | U254-051N-4BH806 | XKB Enterprise
2 | Header-Male-2.54_1x4 | H1,H3,H4 | HDR-TH_4P-P2.54-V | 3 | 210S-1*4P L=11.6MMGold-plated black | Ckmtw
3 | Yellow green 0805 | LED1,LED4 | LED0805-R-RD | 2 | Yellow green 0805 | KENTO
4 | SKRKAEE020 | BOOT,BSL1,ERST,ZRST | SW-SMD_L3.9-W3.0-P4.45 | 4 | SKRKAEE020 | ALPS
5 | 10uF | C2,C3 | C0805 | 2 | 0805F106M160NT | FH
6 | 100nF | C4,C8 | C0805 | 2 | CL21B104KCFNNNE | SAMSUNG
7 | Header-Male-2.54_1x2 | H2 | HDR-TH_2P-P2.54-V | 1 | 826629-2 | TE Connectivity
8 | 10K | R1 | R0805 | 1 | 080500F1000T5E | UniOhm
9 | 100 | R4 | R0805 | 1 | 080500F1000T5E | UniOhm
10 | 1K | R7,R8 | R0805 | 2 | TC0525B1001T5E | UniOhm
11 | cc2652 Modul | U1 | RF-BM-2652P2 | 1 | NF-star
12 | AMS1117-3.3_C165482 | U3 | SOT-223_L6.5-W3.5-P2.30-LS7.0-BR | 1 | AMS1117-3.3 | SK
13 | CH340B | U4 | SOIC-16_L9.9-W3.9-P1.27-LS6.0-BL | 1 | CH340B | WCH
14 | 22 | R5,R6 | R0805 | 2 | 0805W8F220JT5E | UniOhm
15 | WT32-ETH01 | U2 | WT32-ETH01 COPY FP | 1 | WT32-ETH01 | Wireless-Tag

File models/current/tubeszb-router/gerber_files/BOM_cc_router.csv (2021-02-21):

ID | Name | Designator | Footprint | Quantity | Manufacturer Part | Manufacturer
1 | 10KΩ | R1 | R0805 | 1 | SDNT2012X103J3950HTF | Sunlord
2 | Yellow green 0805 | LED3,LED4 | LED0805-R-RD | 2 | Yellow green 0805 | KENTO
3 | 1K | R3,R2 | R0805 | 2 | TC0525B1001T5E | UniOhm
4 | micro USBFemale | USB1 | MICRO-USB-SMD_5P-P0.65-H-F_C10418 | 1 | micro USBFemale | ValuePro
5 | AMS1117-3.3_C165482 | U3 | SOT-223_L6.5-W3.5-P2.30-LS7.0-BR | 1 | AMS1117-3.3 | SK
6 | Header-Male-2.54_1x4 | H1,H2 | HDR-TH_4P-P2.54-V | 2 | 210S-1*4P L=11.6MMGold-plated black | Ckmtw
7 | 100 | R4 | R0805 | 1 | 080500F1000T5E | UniOhm
8 | 100nF | C8,C4 | C0805 | 2 | CL21B104KCFNNNE | SAMSUNG
9 | 10uF | C3,C2 | C0805 | 2 | 0805F106M160NT | FH
10 | cc2652 Modul | U1 | RF-BM-2652P2 | 1 | RF-star
11 | SKRKAEE020 | RST1,BSL1 | SW-SMD_L3.9-W3.0-P4.45 | 2 | SKRKAEE020 | ALPS

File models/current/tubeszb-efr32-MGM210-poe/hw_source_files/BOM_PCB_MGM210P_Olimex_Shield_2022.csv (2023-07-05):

ID | Name | Designator | Footprint | Quantity | Manufacturer Part | Manufacturer
1 | SKRKAEE020 | BOOTLOADER | SW-SMD_L3.9-W3.0-P4.45 | 1 | SKRKAEE020 | ALPS
2 | U.FL-R-SMT-1 | CN1 | U.FL-R-SMT-1 | 1 | U.FL-R-SMT-1 | Hirose Electric Co Ltd
3 | MGM210PA32JIA2 COPY | U4 | MGM210PA32JIA2 | 1 | MGM210PA32JIA2 | Silicon Labs
4 | Header-Male-2.54_1x10 | H1 | HDR-TH_10P-P2.54-V-M-1 | 1 | Headers Pins2.54mm1*10P
5 | HDR2X5-2.54 | U2 | HDR-TH_10P_C9900008731 | 1 | HDR2X5-2.54座 | null

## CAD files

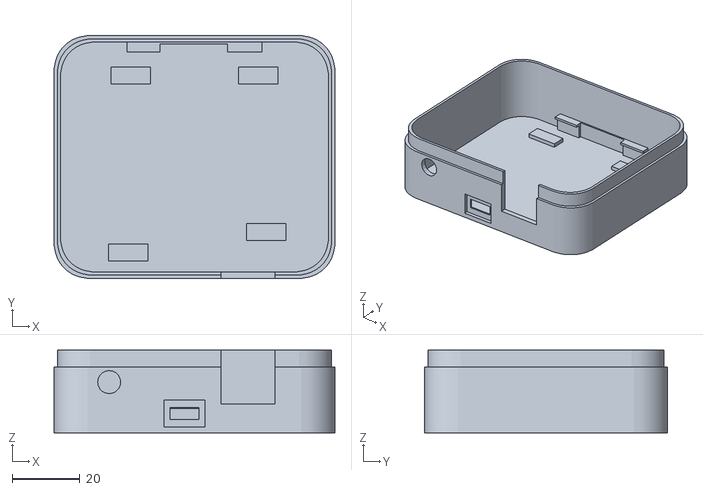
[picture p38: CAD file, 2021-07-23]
Case STL/GW_bottom_v7.stl
83.0 x 71.8 x 24.4

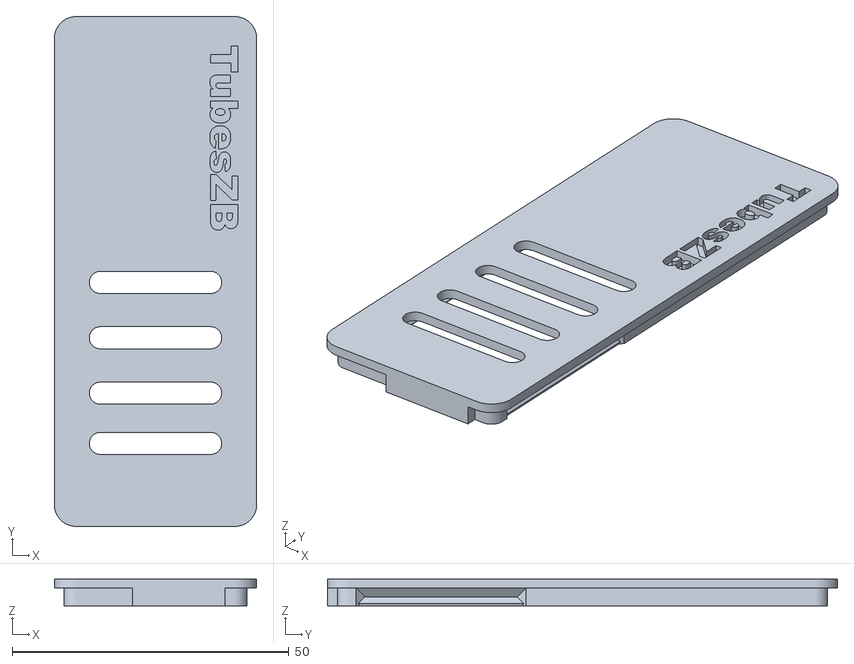
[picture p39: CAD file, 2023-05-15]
models/current/tubeszb-cc2652-P7-poe-2023/case/TubesZB_PoE_Top_20230305.stl
36.6 x 92.2 x 4.80

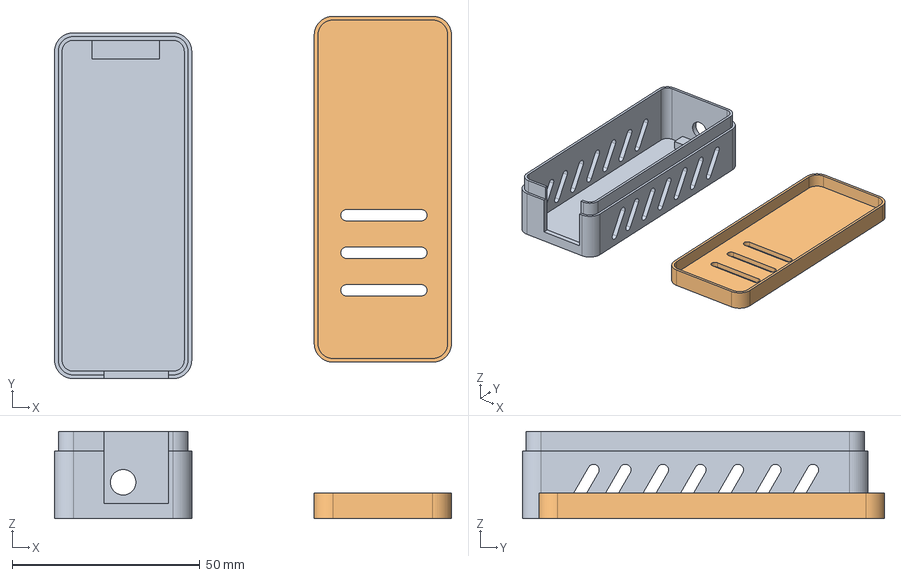
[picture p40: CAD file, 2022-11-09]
models/current/tubeszb-cc2652-poe-2022/case/Step_Fusion360/TubesZB_2022_PoE_Coordinator_Case_Rev_K_Olimex.step
105.8 x 96.6 x 23.2 mm

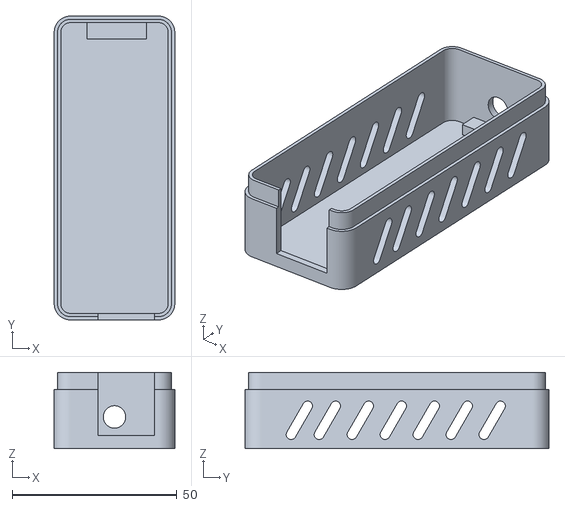
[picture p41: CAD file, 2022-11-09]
models/current/tubeszb-cc2652-poe-2022/case/tubeszb-cc2652-poe-2022_Bot_Rev_K_Olimex.stl
36.6 x 92.2 x 23.2

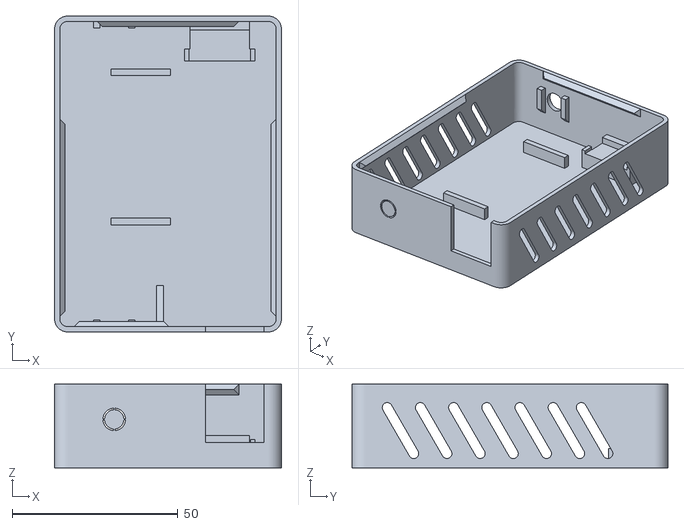
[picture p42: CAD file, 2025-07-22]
models/current/tubeszb-dual-radio-kit/case/tubeszb_dual-radio_bottom_07012025.stl
68.4 x 95.2 x 25.2

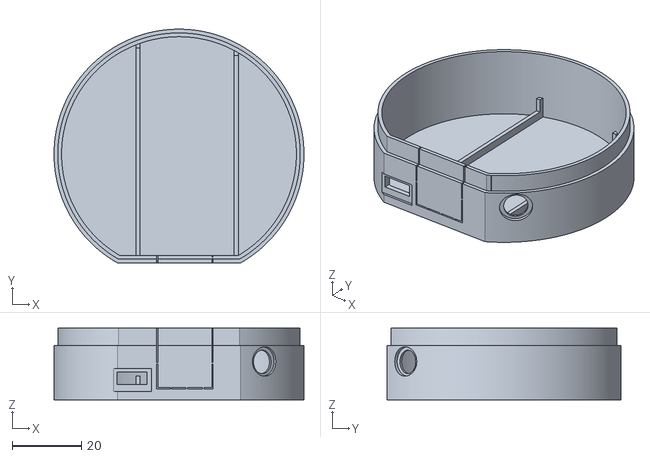
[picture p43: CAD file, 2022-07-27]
models/current/tubeszb-efr32-MGM12-eth_usb/case/tubeszb-cc2652-eth_usb_bottom.stl
72.4 x 67.7 x 20.8

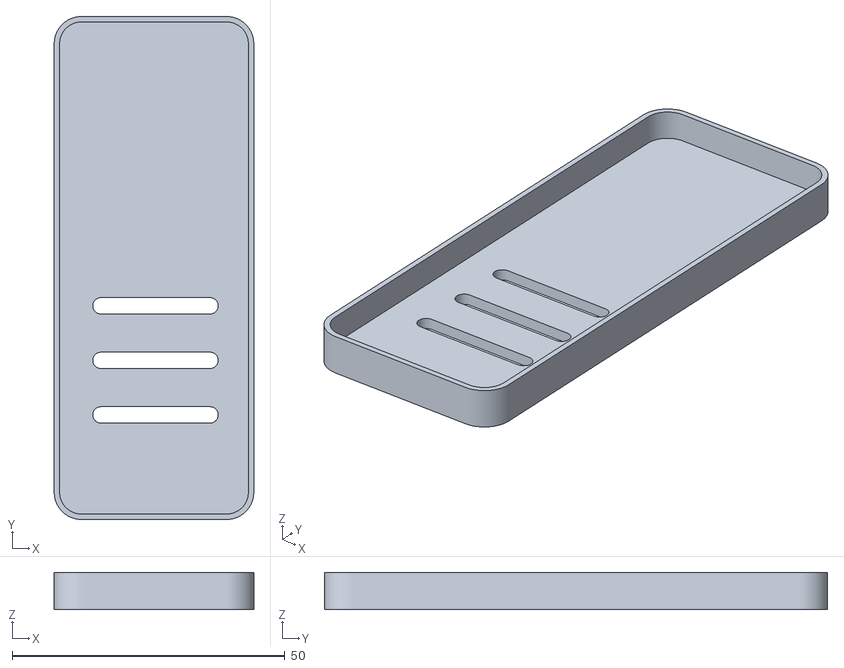
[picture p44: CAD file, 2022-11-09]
models/current/tubeszb-efr32-MGM210-poe/case/tubeszb-cc2652-poe-2022_Top_Rev_K_Olimex.stl
36.6 x 92.2 x 6.80

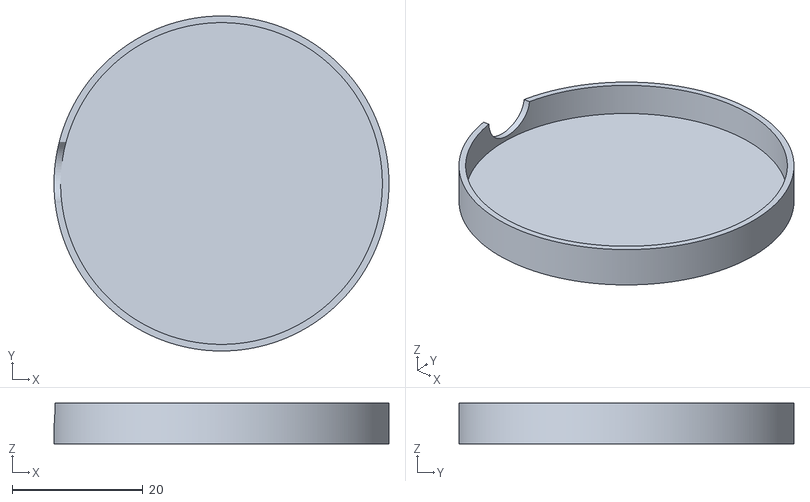
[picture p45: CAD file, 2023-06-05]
models/current/tubeszb-router/case/tubesZB_router_top_v12.stl
51.2 x 51.2 x 6.24

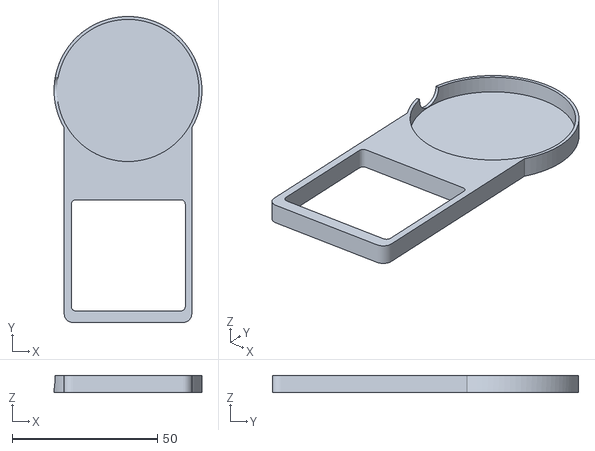
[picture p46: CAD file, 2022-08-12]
models/current/tubeszb-router/case/usermods/cover over usb power.stl
51.0 x 105.5 x 6.00

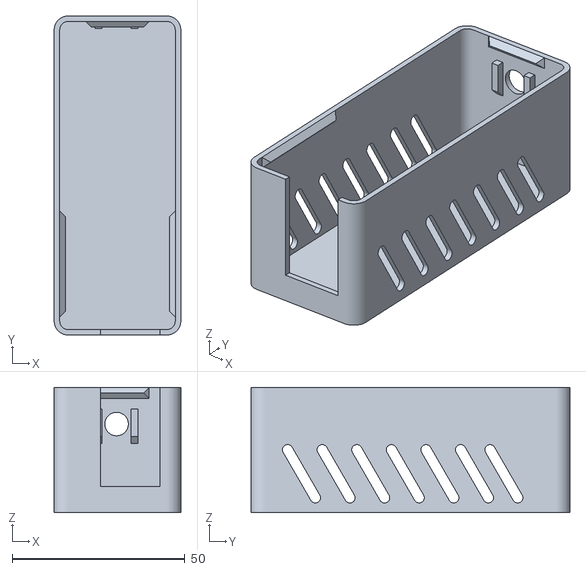
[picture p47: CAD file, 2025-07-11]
models/current/tubeszb-zw-kit/Case/Z-Wave_POE_RAZ_Bottom.stl
36.6 x 92.2 x 36.2

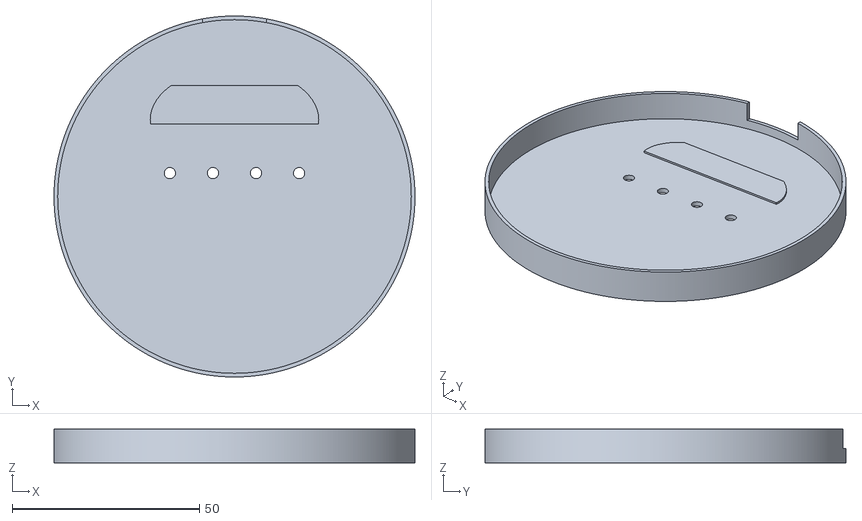
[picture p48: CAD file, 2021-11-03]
tube_poe_coordinator/PoE2_Top_v0.1c.stl
96.4 x 96.4 x 9.05

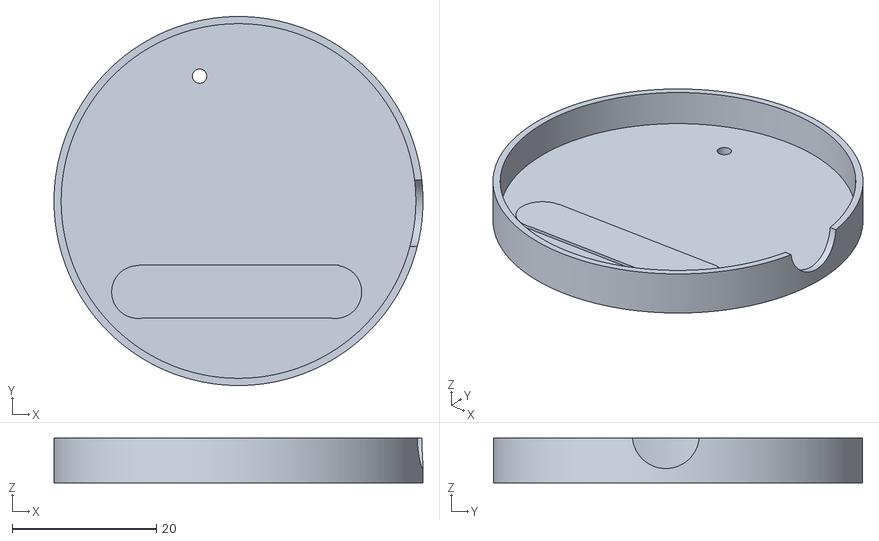
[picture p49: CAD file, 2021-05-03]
tube_usb_cc_coordinator/STL_files/cc_usb_cord_top_v0.5.stl
51.2 x 51.2 x 6.24

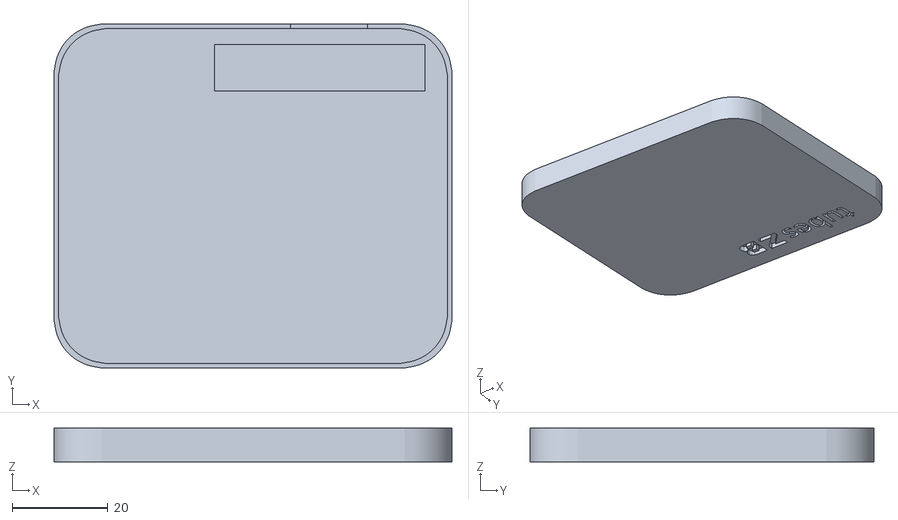
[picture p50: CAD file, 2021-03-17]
Case STL/GW_top_v7.stl
83.0 x 71.8 x 7.00

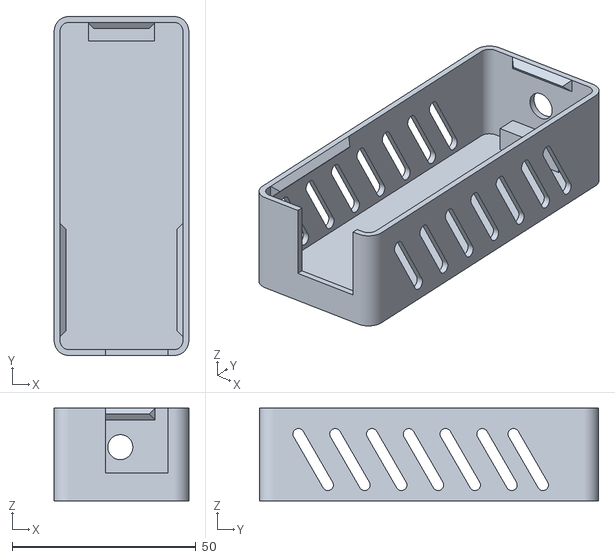
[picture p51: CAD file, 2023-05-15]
models/current/tubeszb-cc2652-P7-poe-2023/case/TubesZB_PoE_Bottom_20230305.stl
36.6 x 92.2 x 25.2

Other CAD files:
models/current/tubeszb-dual-radio-kit/case/tubeszb_dual-radio_top_2025.stl
models/current/tubeszb-efr32-MGM12-eth_usb/case/tubeszb-cc2652-eth_usb_top.stl
models/current/tubeszb-cc2652-poe-2022/case/Step_Fusion360/TubesZB_2022_PoE_Coordinator_Case_Rev_K_Olimex.3mf
models/current/tubeszb-cc2652-poe-2022/case/Step_Fusion360/TubesZB_2022_PoE_Coordinator_Case_Rev_K_Olimex.f3d
models/current/tubeszb-efr32-MGM210-poe/case/Step_Fusion360/TubesZB_2022_PoE_Coordinator_Case.f3d
models/current/tubeszb-efr32-MGM210-poe/case/Step_Fusion360/TubesZB_2022_PoE_Coordinator_Case.step
models/current/tubeszb-efr32-MGM210-poe/case/Step_Fusion360/TubesZB_2022_PoE_Coordinator_Case_Rev_K_Olimex.3mf
models/current/tubeszb-efr32-MGM210-poe/case/Step_Fusion360/TubesZB_2022_PoE_Coordinator_Case_Rev_K_Olimex.f3d
models/current/tubeszb-efr32-MGM210-poe/case/tubeszb-cc2652-poe-2022_Bot.stl
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

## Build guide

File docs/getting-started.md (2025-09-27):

# Getting Started

This guide will walk you through setting up your new TubeZB Coordinator.

## First Steps: Physical Setup

For **Network (Ethernet) Coordinators**:

1.  Connect the gateway to your local network using an ethernet cable.
2.  Power on the gateway using a 5v 1.5-2A power supply with a micro USB cable. The ethernet port's link lights will begin to blink as it connects to your network.
3.  Determine the device's IP address from your router's client list.

!!! tip "Use a Static IP"
    It is strongly advised to configure a static IP address or DHCP reservation for your coordinator in your router's settings. This prevents connection issues if the IP address changes.

For **USB Coordinators**:

1.  Simply plug the coordinator into an available USB port on your Home Assistant machine. It should be auto-discovered.

---

## Home Assistant (ZHA) Setup

Follow these instructions to configure your coordinator with the built-in ZHA integration.

### Method 1: Auto-Discovery (Recommended)

If Home Assistant discovers the device automatically, you will see a notification. Simply click through the configuration flow to add it to Home Assistant.

<figure markdown>
  ZHA Discovery Notification
  <figcaption>ZHA Discovery Notification</figcaption>
</figure>

<figure markdown>
  ZHA Discovery Configuration
  <figcaption>ZHA Discovery Configuration</figcaption>
</figure>

### Method 2: Manual Setup

If your coordinator is not discovered automatically, follow these steps:

1.  Navigate to **Settings > Devices & Services** and click **Add Integration**.
2.  Search for and select **Zigbee Home Automation**.
    Add ZHA Integration
3.  When asked, choose to **Set up another instance of Zigbee Home Automation**.
    Set up another instance
4.  Select the **Radio Type** based on your coordinator model:
    * For **CC2652p** based gateways, select **ZNP**.
    * For **EFR32** based gateways, select **EZSP**.
5.  In the Port Specific Settings dialog:
    * Enter `socket://IP_ADDRESS:6638` (replace `IP_ADDRESS` with your device's actual IP).
    * Set Port Speed to `115200`.
    * Select **Software** Flow Control.
    ZHA Serial Port Settings

---

## Zigbee2MQTT Setup

!!! warning "ZHA vs. Zigbee2MQTT"
    A coordinator can only be controlled by **one** service at a time. If Home Assistant auto-discovers the device for ZHA, you **must** choose to **Ignore** it before setting up Zigbee2MQTT.
    Ignore ZHA Discovery

!!! note "EFR32 Support"
    At this time, only CC2652p based gateways are officially supported by Zigbee2MQTT. EFR32 gateways may work but are not recommended.

### Configuring the `serial` section

Whether you are using the Zigbee2MQTT addon or a standalone `configuration.yaml` file, you will need to edit the `serial` section.

1.  Navigate to the Zigbee2MQTT addon **Configuration** tab or open your `configuration.yaml` file.
2.  Find the `serial:` block. If it doesn't exist, add it.
3.  Use the tabs below to copy the correct configuration for your device.

<figure markdown>
  Zigbee2MQTT Addon Configuration
  <figcaption>Editing the serial settings in the addon configuration tab.</figcaption>
</figure>

=== "Network Coordinator (Ethernet)"

    For coordinators connected via Ethernet, use the `tcp://` port format. Replace `IP_ADDRESS` with your device's actual IP.

    ```yaml
    serial:
      port: 'tcp://IP_ADDRESS:6638'
      # adapter: zstack  # For CC2652 based radios
      # adapter: ember   # For EFR32 based radios
    ```

=== "USB Coordinator"

    For coordinators connected via USB, find the device path under **Settings > System > Hardware > All Hardware**. It will start with `/dev/serial/by-id/...`.

    ```yaml
    serial:
      port: '/dev/serial/by-id/usb-1a86_TubesZB_971207DO-if00-port0'
      # adapter: zstack  # For CC2652 based radios
      # adapter: ember   # For EFR32 based radios
    ```

---

## ESPHome Web Interface

The ESP32 microcontroller inside the gateway runs ESPHome. You can access its web interface by navigating to the device's IP address in a browser.

!!! danger "Ignore ESPHome Entities in Home Assistant"
    ESPHome creates switch entities in Home Assistant that are used to prep the Zigbee module for firmware updates. It is **highly advised** to ignore or disable these entities. Accidentally toggling them can reset the Zigbee module and disrupt your network.

## Firmware Updates
Firmware update instructions can be found on the individual product pages.

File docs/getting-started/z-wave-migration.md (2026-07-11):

# Advanced: Migrating an Existing Z-Wave Network

Migrating your Z-Wave mesh to a TubesZB network controller lets you retire a USB stick without re-including every device. This guide focuses on migrations performed entirely inside **Z-Wave JS UI** while connecting to the TubesZB controller over the network (`esphome://`).

!!! warning "Read this first"
    Migrations copy the controller's Non-Volatile Memory (NVM). If anything goes wrong you may lose access to your devices until the original controller is restored. 

## When to Use This Guide

Use these instructions when you already run Home Assistant with the **Z-Wave JS** or **Z-Wave JS UI** add-on (or a separate Z-Wave JS UI instance) and want to move the existing network to one of the following TubesZB controllers:

* Z-Wave PoE kit (single radio)
* Dual radio PoE kit

Both connect through the ESPHome Z-Wave proxy on port `6053` (firmware `2026.07.11.0` and newer — see the [Z-Wave Proxy Firmware Update](z-wave-proxy-update.md) guide). On older firmware the Z-Wave radio is instead exposed as a TCP serial stream on port `6638` (single radio) or `6639` (dual radio).

If you are starting from scratch, follow the standard [Z-Wave Getting Started guide](z-wave.md) instead.

## Prerequisites

Before you touch any hardware, confirm the following:

- **Z-Wave JS UI access**: You can open the web UI for the instance that manages your current Z-Wave network.
- **Security keys recorded**: Copy the existing `S2 Access Control`, `S2 Authenticated`, `S2 Unauthenticated`, and `S0 Legacy` keys from the current controller. Reusing the exact values is mandatory for secure devices to function after the migration.
- **Old controller firmware**: Update the firmware on the controller you are migrating *from* to the latest vendor release (SDK 7.19.x+ for 800-series radios is strongly recommended). Updated firmware fixes NVM compatibility bugs that can block migration.
- **Home Assistant 2023.9 or newer**: Required for the most recent `zwave_js` integration features referenced here.
- **TubesZB controller on your network**: The device is powered on, reachable over the LAN, and you know its IP address (or hostname). Assign a DHCP reservation so the address does not change mid-migration.

## Step 1 – Back Up the Existing Controller

1. Open **Z-Wave JS UI** for your current controller.
2. Go to **Settings → Z-Wave → Security Keys** and copy the four key values to a safe location (password manager or encrypted notes).
3. Scroll to the bottom of the page and select **Advanced Actions**.
4. Under **NVM Management**, click **Backup**.
5. Wait for the `.bin` (or `.nvm`) file to download. Verify the file size is larger than 100 kB; small files usually indicate a failed backup.

<figure markdown>
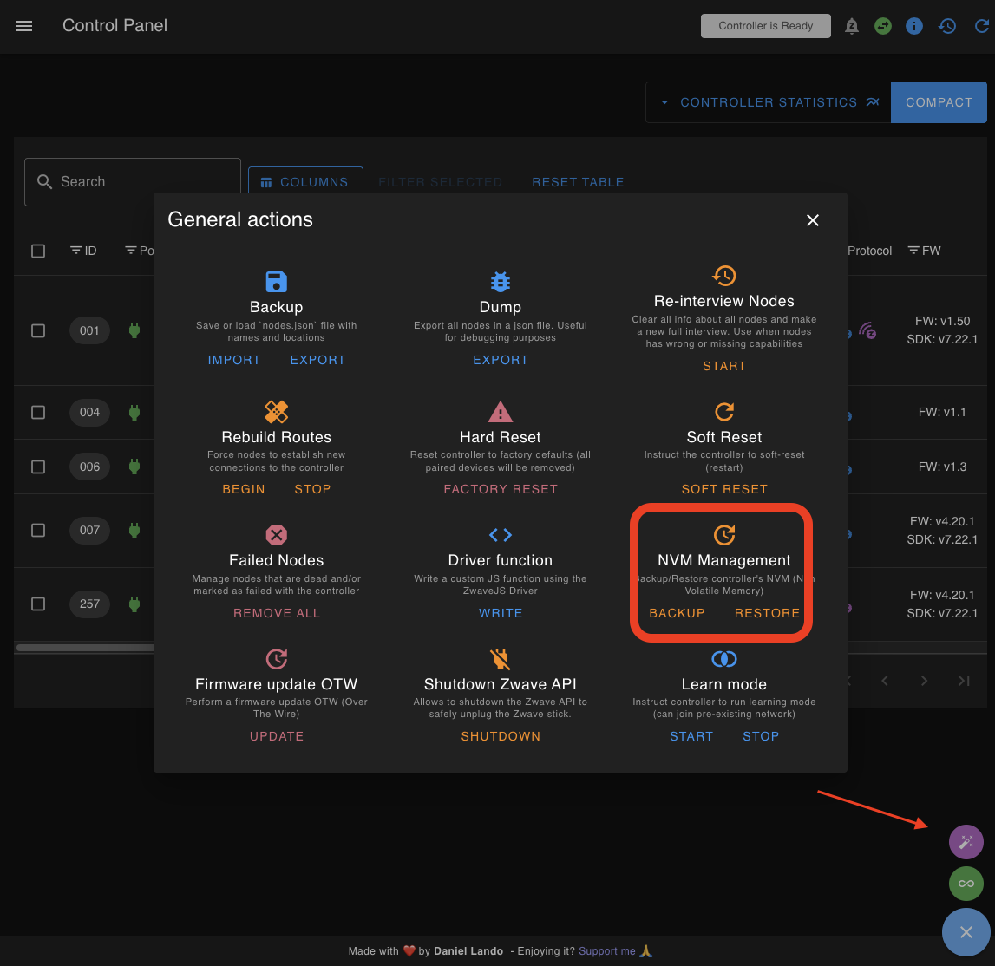
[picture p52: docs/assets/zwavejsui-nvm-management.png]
Z-Wave JS UI NVM Management dialog
  
  <figcaption>Use the NVM Management panel in Z-Wave JS UI to create the backup you will restore onto the TubesZB controller.</figcaption>
</figure>

### Download the backup from Home Assistant

Backing up from the Home Assistant UI is useful when you do not have direct access to Z-Wave JS UI or want a second copy of the data.

**Why create a backup?**
:   It is recommended to create a backup before making major changes to your Z-Wave network, such as migrating between adapters or resetting hardware. The backup captures the adapter's Non-Volatile Memory (NVM), including your node and security information, in a binary file that you can download.

**Prerequisites**
:   Administrator rights in Home Assistant.

**To download the backup**
1. In Home Assistant, go to **Settings → Devices & services**.
2. Select the **Z-Wave** integration.
3. Choose the **cogwheel** icon to open the integration options.
4. Under **Backup and restore**, select **Download backup**.
5. Confirm the browser downloads the file on the device you are using to access Home Assistant.

!!! tip "Using the Z-Wave JS add-on (no UI)"
    If you still run the legacy **Z-Wave JS** add-on without the UI, install the **Z-Wave JS UI** add-on alongside it, stop the **Z-Wave JS** add-on, start the UI version, and point it to your existing USB stick. Once the UI sees your nodes, you can take the NVM backup from the UI and continue the migration.

    Alternatively, download the backup from within Home Assistant:

    1. In Home Assistant, go to **Settings → Devices & services**.
    2. Select the **Z-Wave** integration and choose the **cogwheel** icon.
    3. Under **Backup and restore**, select **Download backup**. The file saves to the device you are using.
    4. Stop the **Z-Wave JS** add-on and disable auto-start.
    5. Remove your old controller.

## Step 2 – Prepare the TubesZB Controller

1. Make sure the TubesZB hardware is powered and connected to your network.
2. In **Z-Wave JS UI**, stay on **Settings → Z-Wave** and populate the **Serial Port** field with the path to the TubesZB kit, for example `esphome://192.168.1.42:6053` (same format for single and dual radio kits).

    !!! info "Older firmware (before 2026.07.11.0)"
        On firmware older than `2026.07.11.0`, use the TCP serial stream instead: `tcp://192.168.1.42:6638` (single radio) or `tcp://192.168.1.42:6639` (dual radio, Z-Wave side).
3. Paste the security keys you collected in Step 1 into the matching fields. Do **not** generate new keys when migrating an existing mesh.
4. Click **Save**. The service will restart and attempt to reach the new controller over TCP.

!!! danger "Only one controller at a time"
    After clicking **Save**, immediately unplug or power down the old USB controller. Running two controllers with the same Home ID at once can corrupt your mesh and create routing chaos.

## Step 3 – Restore the NVM Backup

1. In **Z-Wave JS UI**, open **Advanced Actions → NVM Management** again.
2. Choose **Restore** and upload the backup file you created in Step 1.
3. Wait for the progress dialog to reach 100%. Do not close the browser or refresh the page.
4. When prompted, allow Z-Wave JS UI to restart the controller.
5. After the restart completes, the controller should display the same Home ID as the old stick, and your devices will appear in the control panel.

!!! info "RF region and power"
    Double-check **Settings → Z-Wave → RF Region**. Z-Wave JS should auto select the correct region if not select the region that matches your regulatory requirements before you restore the NVM. Changing the region afterwards requires another restore.

## Step 4 – Verify Home Assistant and Rebuild Routes

1. Open **Settings → Devices & Services** in Home Assistant and ensure the existing `Z-Wave JS` integration shows as **Connected**. If it is unavailable, select **Configure** and confirm that the WebSocket URL still points to your Z-Wave JS UI instance (typically `ws://a0d7b954-zwavejsui:3000`).
2. In **Z-Wave JS UI**, review a few nodes to confirm their interview status is **Complete**.
3. Launch **Advanced Actions → Rebuild Routes**.
   - Enable **Include sleeping nodes** so battery-powered devices refresh their paths.
   - Enable **Delete priority return routes** to discard stale manual routes from the old controller.
4. Monitor the control panel for failed nodes. Wake sleeping devices manually if needed to finish the rebuild.
5. Once the rebuild finishes, verify automations and entities in Home Assistant behave as expected.

## Step 5 – Clean Up and Update Backups

- Archive the NVM backup you created in Step 1 along with a fresh backup taken from the TubesZB controller after the restore.
- Label the old USB stick and store it powered off. Do not plug it back in unless you intend to roll back to it.
- Update any documentation or diagrams that list the controller address so they reference the `esphome://` endpoint.

## Troubleshooting

**Controller refuses the connection**
:   Confirm the TubesZB kit is running the latest ESPHome firmware and that your firewall allows outbound TCP 6053 from Home Assistant (6638/6639 on pre-`2026.07.11.0` firmware).

**Nodes show as failed or missing after restore**
:   Wake battery devices, then run **Advanced Actions → Heal Node** on problematic nodes. If secure devices still fail, verify the security keys exactly match the originals (no extra whitespace).

**Home Assistant keeps rediscovering a second controller**
:   You may have left the old USB stick connected. Remove it, reboot Home Assistant, and clear ignored discovery notifications.

**Restoring the NVM fails immediately**
:   The old controller firmware may pre-date the TubesZB controller's stack version. Update the original controller to a newer SDK, re-connect it temporarily, create a fresh backup, and try again.

## Further Reading

- [Home Assistant: Migrating a Z-Wave network to a new adapter](https://www.home-assistant.io/integrations/zwave_js/#migrating-a-z-wave-network-to-a-new-adapter)
- [Nabu Casa: Migrating an existing Z-Wave network to Home Assistant Connect ZWA-2](https://support.nabucasa.com/hc/en-us/articles/29529265751965)
- [Z-Wave JS UI Documentation](https://zwave-js.github.io/zwave-js-ui/)

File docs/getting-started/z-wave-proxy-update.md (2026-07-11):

# Updating to the Z-Wave Proxy Firmware

Firmware **2026.07.11.0** moves all TubesZB devices with a Z-Wave radio from the raw TCP serial stream to the native **ESPHome Z-Wave Proxy**. A recent zwave-js change ([zwave-js#8861](https://github.com/zwave-js/zwave-js/pull/8861)) breaks reconnection over serial-over-TCP streams; the proxy is the supported path going forward.

!!! danger "Breaking change — action required"
    After installing this firmware update, the Z-Wave TCP serial port is **removed** (`6638` on Z-Wave-only kits, `6639` on Dual Radio kits). Z-Wave JS will **not reconnect** until you update its connection settings as described below. Plan for a few minutes of Z-Wave downtime.

**Affected devices:**

* Z-Wave PoE Kit (`tubeszb-zw`, `tubeszb-2026-zw`)
* Dual Radio Kits (`tubeszb-dual-radio-kit-cc2652`, `tubeszb-dual-radio-kit-mgm24`, `tubeszb-dual-radio-mgm21-2022`)

!!! note "Zigbee is unaffected"
    On Dual Radio kits, the Zigbee serial stream (port `6638`) is unchanged. No Zigbee2MQTT or ZHA changes are needed.

## Before You Update

* **Your Z-Wave network is safe.** The network (nodes, security, routing) is stored on the Z-Wave radio module itself; this firmware update does not touch it.
* **Take a backup anyway (recommended).** In Home Assistant go to **Settings → Devices & Services → Z-Wave**, and under **Backup and restore** select **Download backup**. It's free insurance.
* **Note your device's IP address.** You'll need it for the new connection path. A DHCP reservation is strongly recommended if you don't have one already.
* **Update Z-Wave JS UI / the Z-Wave JS add-on to the latest version** so it supports `esphome://` connections.

## Step 1 – Install the Firmware Update

1. In Home Assistant, open the TubesZB device page under **Settings → Devices & Services → ESPHome**.
2. Find the **TubesZB Firmware Update** entity and select **Install**.
3. Wait for the device to flash and reboot (about a minute). The Z-Wave JS connection will drop — this is expected.

!!! tip "Alternative: web installer"
    You can also update from the device's built-in web page (`http://<device-ip>`) using the firmware update entity there, or flash the latest release binary from the [Latest Release folder](https://tube0013.github.io/TubesZB-ESPHome-Builder/Latest_Release/).

## Step 2 – Point Z-Wave JS at the Proxy

The connection path changes from `tcp://<device-ip>:6638` (or `:6639`) to:

```
esphome://<device-ip>:6053
```

Follow the section that matches your setup.

### Home Assistant Z-Wave Integration

1. Go to **Settings → Devices & Services → Z-Wave**.
2. Select **Migrate adapter** (under the integration's configuration).
3. In the **Migrate or reconfigure** dialog, choose **Reconfigure the current adapter** — you are keeping the same radio, only changing how it's reached.
4. Select **Use Socket**, and replace the old `tcp://` path in the **Socket device path** field with the new one, e.g. `esphome://192.168.1.7:6053`.
5. Submit and wait for the driver to restart.

<figure markdown>
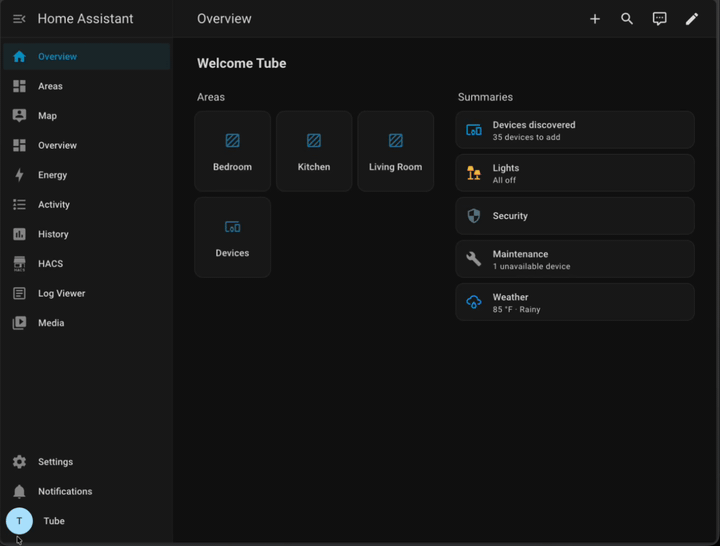
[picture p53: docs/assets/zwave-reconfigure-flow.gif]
Reconfiguring the adapter to the ESPHome proxy
  
  <figcaption>The full flow: Migrate adapter → Reconfigure the current adapter → Use Socket → esphome:// path.</figcaption>
</figure>

### Z-Wave JS UI (Standalone / Docker)

1. Open **Settings → Z-Wave** in the Z-Wave JS UI web interface.
2. In the **Serial Port** field, replace the old `tcp://` path with `esphome://<device-ip>:6053`.
3. Leave your **Security Keys** exactly as they are.
4. Click **Save**. The service restarts and connects through the proxy.

## Step 3 – Verify

* The Z-Wave integration / control panel shows the controller as **Connected**, with the **same Home ID** as before.
* Your nodes appear with their interview status intact — no re-inclusion is needed.
* On the device's web page, the old "Z-Wave Serial Connection Status" sensor is gone; the device now reports firmware `2026.07.11.0` under **TubesZB ESPHome FW Version**.

## Troubleshooting

**Z-Wave JS says the connection failed after updating its settings**
:   Confirm the device actually took the firmware update — check that **TubesZB ESPHome FW Version** on the device page (or web UI) reads `2026.07.11.0` or newer. On older firmware, keep using the `tcp://` path until you update.

**`esphome://` is not accepted in the path field**
:   Your Z-Wave JS UI / add-on version predates ESPHome proxy support. Update the add-on / container to the latest version and try again.

**Connected but no traffic / driver won't start**
:   The proxy allows **one** client at a time. Make sure no second Z-Wave JS instance (an old add-on still running, a test container) is connected to the same device, then restart the driver.

**I need to roll back**
:   Previous release binaries remain available on the [GitHub releases page](https://github.com/tube0013/TubesZB-ESPHome-Builder/releases). Flash the prior version via the device web page and restore your old `tcp://` settings.

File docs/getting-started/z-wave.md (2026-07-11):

# Getting Started with the Z-Wave PoE Kit

This guide will walk you through setting up your new TubeZB Z-Wave PoE Kit with Home Assistant.

!!! info "Choose the right path"
    - Setting up your first Z-Wave network? Continue with this guide.
    - Migrating from another controller? Follow the [Advanced: Migrating an Existing Z-Wave Network](z-wave-migration.md) guide instead.

## 1. Physical Setup

Your setup steps will depend on whether you purchased the kit with the Zooz Z-Wave module pre-installed or the "No Radio" version.

### Option A: Kit with Pre-installed Zooz ZAC93

If you purchased the kit with the Zooz ZAC93 module included, it comes pre-installed and ready to go.

1.  Connect the Z-Wave PoE Kit to your local network using an ethernet cable that provides Power over Ethernet (PoE).
2.  The device will power on and connect to your network.
3.  Find the IP Address assigned to the device from your router's client list.

!!! tip "Use a DHCP Reservation (Recommended)"
    To ensure the device's IP address doesn't change, it is strongly advised to configure a **DHCP Reservation** for it in your router's settings. This links the device's unique MAC address to a specific IP, so it gets the same one every time it connects.

    !!! info "Advanced: Static IP Firmware"
        Setting a true static IP requires custom firmware. For advanced users who need this, you can build a custom firmware binary using the **[TubesZB ESPHome Firmware Builder](https://github.com/tube0013/TubesZB-ESPHome-Builder)**.

!!! success "Register Your Zooz Module!"
    If you purchased a kit including the Zooz ZAC93, be sure to **[register your module with Zooz](https://www.getzooz.com/register/)** within 30 days of purchase. This gives you a 5-Year Extended Warranty, direct access to firmware updates, and expedited support.

### Option B: Kit with No Radio (Bring Your Own Module)

If you purchased the "No Radio" version of the kit, you will need to provide and install your own compatible Z-Wave module.

#### Compatible Modules

This kit is designed for Z-Wave modules that use the Raspberry Pi GPIO pin layout.

* **[Zooz 800 Long Range ZAC93](https://amzn.to/3O2ewpM)**
* **[Z-Wave.me RaZberry 7 Pro](https://amzn.to/41XOFVK)**

!!! info "Affiliate Link Disclosure"
    The links above are Amazon affiliate links. As an Amazon Associate, I earn from qualifying purchases.

#### Installation

1.  Carefully open the 3D printed enclosure.
2.  Align the GPIO pins on your Z-Wave module with the female GPIO header on the Olimex ESP32-PoE board.
3.  Press down firmly and evenly to seat the module securely. Ensure all pins are correctly engaged.
4.  Close the enclosure.
5.  Follow the steps in **Option A** to connect the device to your network and find its IP address.

---

## 2. Home Assistant Setup

The recommended method for using this Z-Wave kit is with the **Z-Wave JS UI** addon in Home Assistant.

1.  **Install and Start the Addon:**
    * Click the badge below to open the Z-Wave JS UI addon page in your Home Assistant instance and click **Install**.

    

    * Once installed, go to the **Info** tab and **Start** the addon.

2.  **Configure the Addon via the Web UI:**
    * After the addon has started, click **Open Web UI**.
    * In the Z-Wave JS UI interface, navigate to **Settings** (the gear icon) and then select **Z-Wave**.
    * In the **Serial Port** field, enter the network path for your Z-Wave kit, replacing `IP_ADDRESS` with the IP you found earlier:
      ```
      esphome://IP_ADDRESS:6053
      ```
    <figure markdown>
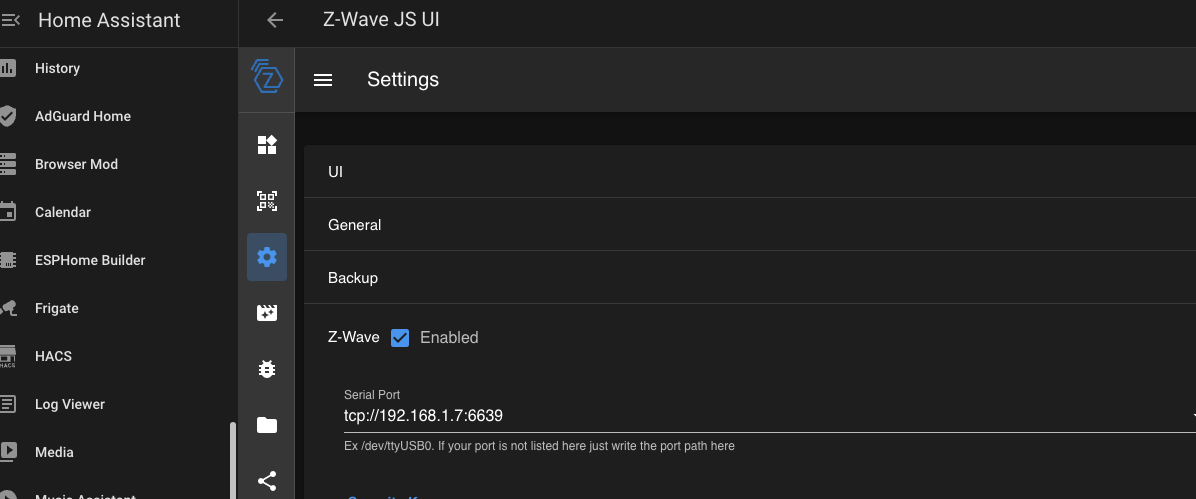
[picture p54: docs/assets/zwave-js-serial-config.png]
Z-Wave JS UI Serial Port Configuration
      
      <figcaption>Entering the connection path in the Serial Port field.</figcaption>
    </figure>

        !!! info "Older firmware (before 2026.07.11.0)"
            Devices running firmware older than `2026.07.11.0` expose a raw TCP serial stream instead of the ESPHome Z-Wave proxy. On those, use `tcp://IP_ADDRESS:6638` (or `tcp://IP_ADDRESS:6639` on a **Dual Radio kit**) — and consider [updating to the Z-Wave Proxy firmware](z-wave-proxy-update.md). The `esphome://` path is the same on all models, single and dual radio.

    * **Generate and Save Security Keys:**
        !!! danger "Critical Step for New Networks"
            If you are setting up a **new** network, you **must** generate new security keys. These keys are essential for securely including devices and for backing up your network.

         1.  Scroll down to the **Security Keys** section.
         2.  Click the refresh icon next to **each** of the four keys (`S2_AccessControl`, `S2_Authenticated`, `S2_Unauthenticated`, and `S0_Legacy`) to generate new random values.
         3.  **Copy and save these keys somewhere safe**, like a password manager. You will need them if you ever have to restore your network.

    <figure markdown>
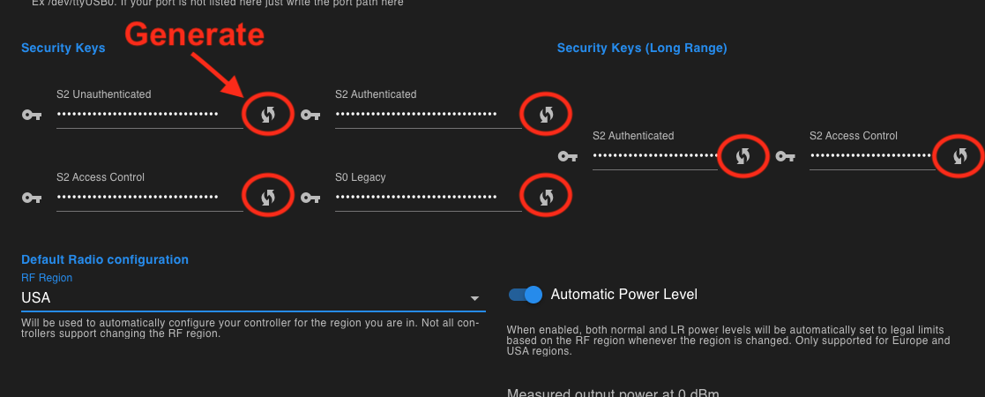
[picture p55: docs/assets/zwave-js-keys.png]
Z-Wave JS UI Security Keys
      
      <figcaption>Generating new security keys by clicking the refresh icon for each key.</figcaption>
    </figure>

    * Click **Save** at the bottom of the page. The addon will restart and connect to your Z-Wave PoE Kit. You can check the **Control Panel** to see your Z-Wave stick appear as the controller.

3.  **Install the Z-Wave JS Integration:**
    * Navigate back to Home Assistant and go to **Settings > Devices & Services**.
    * Home Assistant should now auto-discover the Z-Wave JS integration. Click **Configure** and follow the prompts.
    * If it is not discovered, click **Add Integration** and search for **Z-Wave**.
    * You will be prompted to either use the recommended installation or a custom one. Since we are using the Z-Wave JS UI addon, you can proceed with the **Recommended installation**.
    <figure markdown>
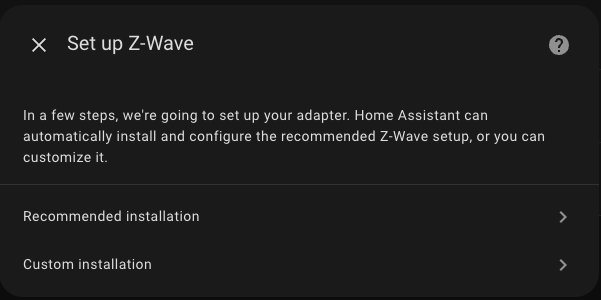
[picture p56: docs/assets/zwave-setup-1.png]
Set up Z-Wave Dialog
      
      <figcaption>Choose the recommended installation.</figcaption>
    </figure>
    * In the next dialog, **uncheck** the box that says "Use the Z-Wave Supervisor add-on" and click **Submit**.
    <figure markdown>
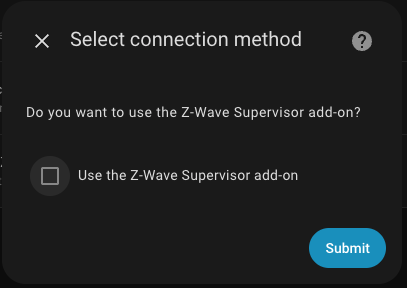
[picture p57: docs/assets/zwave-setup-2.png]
Select Connection Method
      
      <figcaption>Uncheck the box to provide the URL manually.</figcaption>
    </figure>
    * You will now be asked for a URL. For the official Home Assistant addon, you can find the correct hostname on the addon's page.
    <figure markdown>
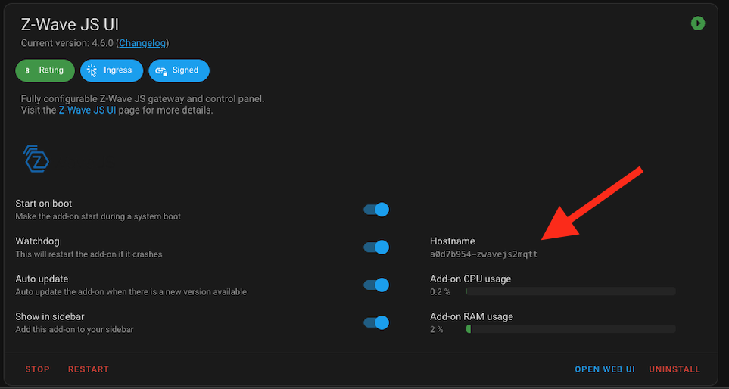
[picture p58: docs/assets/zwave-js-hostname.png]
Z-Wave JS UI Hostname
      
      <figcaption>The addon hostname can be found on the Addon Info page.</figcaption>
    </figure>
    * Enter the following value, which tells the integration how to connect to your Z-Wave JS UI addon:
      ```
      ws://a0d7b954-zwavejsui:3000
      ```
    <figure markdown>
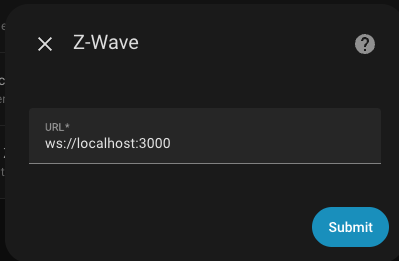
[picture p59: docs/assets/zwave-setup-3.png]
Enter WebSocket URL
      
      <figcaption>Enter the addon's WebSocket URL.</figcaption>
    </figure>
    !!! tip "Connecting to a Remote Z-Wave JS UI"
        If you are running Z-Wave JS UI on a different computer (not as a Home Assistant addon), you must replace `a0d7b954-zwavejsui` with the hostname or IP address of that computer. For example: `ws://192.168.1.100:3000`.
    * Click **Submit** to complete the setup. The integration will connect, and your Z-Wave devices will appear in Home Assistant.

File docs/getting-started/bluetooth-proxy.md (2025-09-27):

# Getting Started with Bluetooth Proxies

This guide will walk you through setting up your new TubeZB Bluetooth Proxy.

## What is a Bluetooth Proxy?

A Bluetooth Proxy extends the range of Bluetooth reception for your Home Assistant instance. If you have Bluetooth devices (like temperature sensors, smart locks, etc.) that are too far away from your main Home Assistant machine to connect reliably, you can place a proxy closer to them. The proxy will listen for Bluetooth signals and relay them back to Home Assistant over your network (WiFi or Ethernet).

## Physical Setup

1. Connect the Bluetooth Proxy to your local network using an ethernet cable (recommended for best reliability).

2. Power on the device using a 5V USB-C power supply.

## Home Assistant Setup

Tube's Bluetooth Proxies run ESPHome. When you connect it to your network, Home Assistant should automatically discover it.

1. Ensure your Bluetooth Proxy is powered on and connected to the same network as your Home Assistant instance.

2. A notification should appear in **Settings > Devices & Services** for a new ESPHome device.

3. Click **Configure** and then **Submit** to add the proxy to your system.

That's it! The proxy will now automatically start listening for Bluetooth devices and forwarding the data. You don't need to do anything else. You can confirm it's working by seeing new Bluetooth devices appear in Home Assistant that were previously out of range.

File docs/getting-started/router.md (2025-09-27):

# Getting Started with Zigbee Routers

This guide covers the initial setup and pairing for all TubesZB Zigbee Routers.

## Pairing Your Router

The process is designed to be as simple as possible. Your router will automatically try to join a Zigbee network when it's first powered on.

1.  **Enable Pairing:** In your Zigbee platform (like ZHA or Zigbee2MQTT), enable "permit join" mode to allow new devices to connect.

2.  **Power On the Router:** Plug the router into a suitable USB power source.
    * **Current Models:** Use a 5V 1-2A power supply with a **USB-C** cable.
    * **Older Models:** Use a 5V 1-2A power supply with a **Micro-USB** cable.

3.  **Wait for Pairing:** The router should now be discovered and join your Zigbee network automatically. You will see it appear in your Zigbee integration's device list.

If the router does not pair, try power cycling it once while your network is still in pairing mode. For more advanced operations, please see the specific documentation for your router model.

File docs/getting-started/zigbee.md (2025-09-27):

# Getting Started with Zigbee Coordinators

This guide will walk you through setting up your new TubesZB Zigbee Coordinator with Home Assistant.

## First Steps: Physical Setup

For **Network (Ethernet) Coordinators**:

1.  Connect the gateway to your local network using an ethernet cable.
2.  For non-PoE models power the gateway using a 5v 1.5-2A power supply with the included USB-C cable (MicroUSB on older models). The ethernet port's link lights will begin to blink as it connects to your network.
3.  Determine the device's IP address from your router's client list.

!!! tip "Use a DHCP Reservation (Recommended)"
    To ensure the device's IP address doesn't change, it is strongly advised to configure a **DHCP Reservation** for it in your router's settings. This links the device's unique MAC address to a specific IP, so it gets the same one every time it connects.

    !!! info "Advanced: Static IP Firmware"
        Setting a true static IP requires custom firmware. For advanced users who need this, you can build a custom firmware binary using the **[TubesZB ESPHome Firmware Builder](https://github.com/tube0013/TubesZB-ESPHome-Builder)**.

For **USB Coordinators**:

1.  Simply plug the coordinator's USB Cable into an available USB port on your Home Assistant machine. It should be auto-discovered.

---

## Home Assistant (ZHA) Setup

Follow these instructions to configure your coordinator with the built-in ZHA integration.

### Method 1: Auto-Discovery (Recommended)

If Home Assistant discovers the device automatically, you will see a notification. Simply click through the configuration flow to add it to Home Assistant.

<figure markdown>
  ZHA Discovery Notification
  <figcaption>ZHA Discovery Notification</figcaption>
</figure>

<figure markdown>
  ZHA Discovery Configuration
  <figcaption>ZHA Discovery Configuration</figcaption>
</figure>

### Method 2: Manual Setup

If your coordinator is not discovered automatically, follow these steps:

1.  Navigate to **Settings > Devices & Services** and click **Add Integration**.
2.  Search for and select **Zigbee Home Automation**.
    Add ZHA Integration
3.  When asked, choose to **Set up another instance of Zigbee Home Automation**.
    Set up another instance
4.  Select the **Radio Type** based on your coordinator model:
    * For **CC2652p** based gateways, select **ZNP**.
    * For **EFR32** based gateways, select **EZSP**.
5.  In the Port Specific Settings dialog:
    * Enter `socket://IP_ADDRESS:6638` (replace `IP_ADDRESS` with your device's actual IP).
    * Set Port Speed to `115200`.
    * Select **Software** Flow Control.

    ZHA Serial Port Settings

---

## Zigbee2MQTT Setup

!!! warning "ZHA vs. Zigbee2MQTT"
    A coordinator can only be controlled by **one** service at a time. If Home Assistant auto-discovers the device for ZHA, you **must** choose to **Ignore** it before setting up Zigbee2MQTT.
    Ignore ZHA Discovery

!!! note "EFR32 Support"
    Zigbee2MQTT supports EFR32 coordinators, but the must be on a 7.4.x or greater firmware

### Configuring the `serial` section

Whether you are using the Zigbee2MQTT addon or a standalone `configuration.yaml` file, you will need to edit the `serial` section.

1.  Navigate to the Zigbee2MQTT addon **Configuration** tab or open your `configuration.yaml` file.
2.  Find the `serial:` block. If it doesn't exist, add it.
3.  Use the tabs below to copy the correct configuration for your device.

<figure markdown>
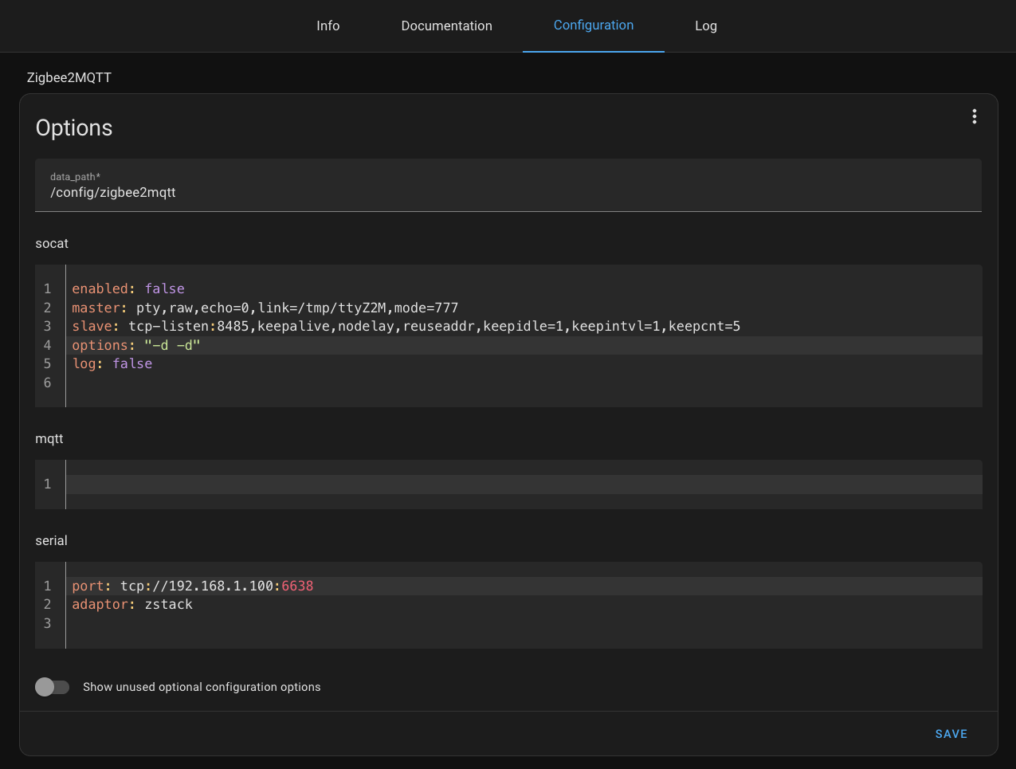
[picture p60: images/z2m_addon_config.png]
Zigbee2MQTT Addon Configuration
  
  <figcaption>Editing the serial settings in the addon configuration tab.</figcaption>
</figure>

#### Network Coordinator (Ethernet)

    For coordinators connected via Ethernet, use the `tcp://` port format. Replace `IP_ADDRESS` with your device's actual IP.

    ```yaml
    serial:
      port: 'tcp://IP_ADDRESS:6638'
      # adapter: zstack  # For CC2652 based radios
      # adapter: ember   # For EFR32 based radios
    ```

#### USB Coordinator

    For coordinators connected via USB, find the device path under **Settings > System > Hardware > All Hardware**. It will start with `/dev/serial/by-id/...`.

    ```yaml
    serial:
      port: '/dev/serial/by-id/usb-1a86_TubesZB_971229NY-if00-port0'
      # adapter: zstack  # For CC2652 based radios
      # adapter: ember   # For EFR32 based radios
    ```

---

## ESPHome Web Interface

The ESP32 microcontroller inside the gateway runs ESPHome. You can access its web interface by navigating to the device's IP address in a browser.

If you add the ESPHome device to you Home Assistant instance it will create some diagnostic entities for showing if the serial connection connected or not. as well as the connection count. 

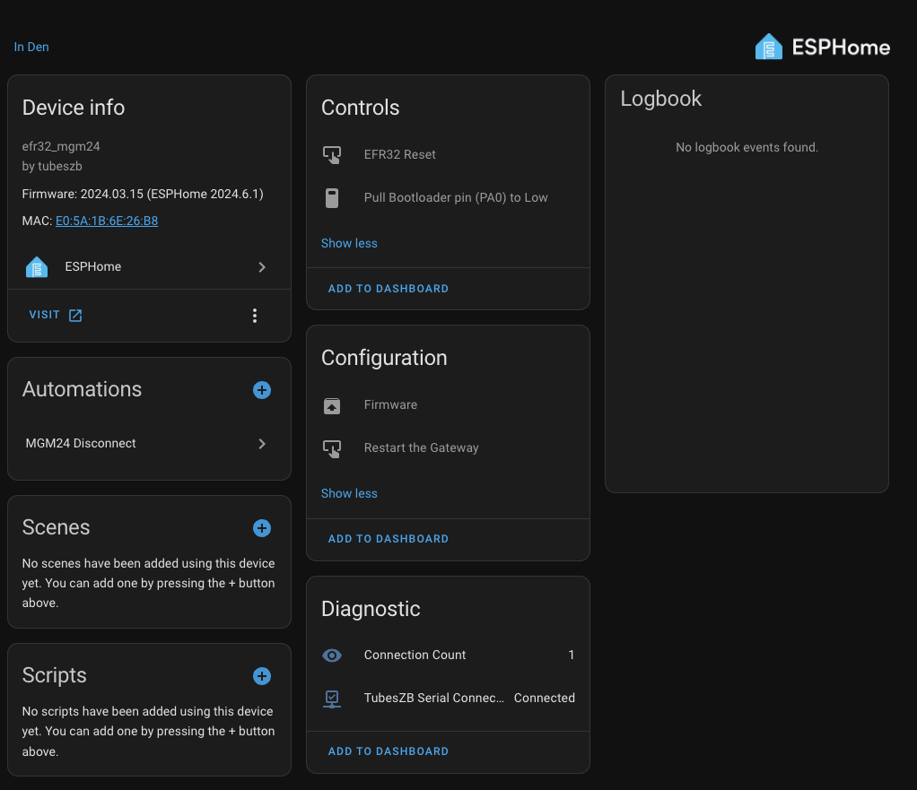
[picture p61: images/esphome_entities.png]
ESPHome Entities


!!! danger "Ignore ESPHome Entities in Home Assistant"
    There are several other enties that are created but set as disabled by default. It is **highly advised** to leave these as disabled. Accidentally toggling them can reset the Zigbee module and disrupt your network.

## Firmware Updates
Firmware update instructions can be found on the individual product pages.

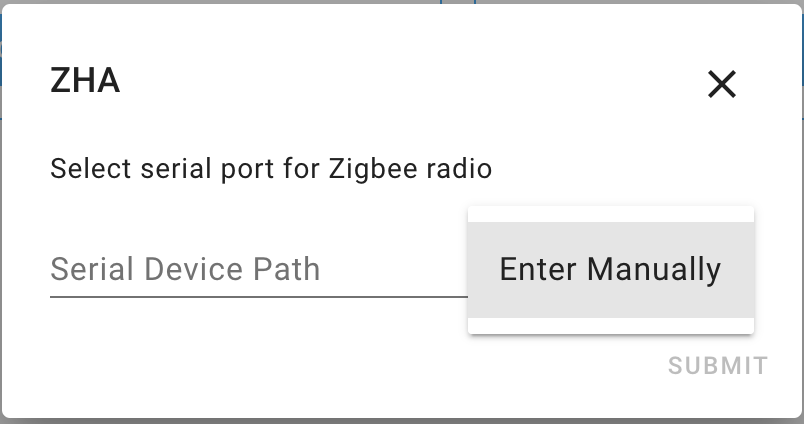
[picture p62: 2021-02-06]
images/manual.png

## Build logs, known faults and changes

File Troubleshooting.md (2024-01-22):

# Troubleshooting

## Zigbee2MQTT startup - Error: SRSP - SYS - ping after 6000ms

If you see this message in your z2m Logs with a network connected coordiator: 
```
Error: Failed to connect to the adapter (Error: SRSP - SYS - ping after 6000ms)
```

Please reflash the esphome firmware to the esp32 via serial. **For current devices**, see the Devices page in the repo, for the original rectangular coordinator see below.

Unfortunately I do not know the casue for this error. It occurs on a small number of devices, and sometimes after doing an OTA ESP32 FW update. It seems specifict to Zigbee2mqtt as the zigpy based tools continue to work fine with the devices. The most reliable fix has been a full serial flash of esphome which does a full esp32 erase before writing the firmware.

## What you need:

For the original rectangular cc2652 coordinator you will need a Serial to USB TTL adaptor - I use one similar to this one and it works well: [HiLetgo CP2102 USB to TTL UART](https://amzn.to/44PcsrF)

Grab the current esp fw bin file from your device's firmware/esphome folder on this repo either under models/current or retired. The readme on the devices folder will also have serial flashing instructions.

I use the esphome flasher tool which works well for me:
https://github.com/esphome/esphome-flasher/releases

you’ll need 3 jumper wires, the board has pins, so will need females on that end and female/male on the other depending on your Serial TTL adaptor board.

  

TX on the Serial TTL adaptor goes to the eRX pin on the board (red wire in pic)

RX on the Serial TTL adaptor goes to the eTX pin on the board (orange wire in pic)

Ground from the Serial TTL adaptor goes to the Ground pin on the board (closest to 3.3v) (brown wire in pic)

Use the jumper from the 3.3v_Bridge on the board (or another female to female jumper wire) to bridge the ground and IO0 pins (the spacing is tight I found tweezer so pinch nosed pliers best for adding the jumper)

Once all that is connected up, power on by plugging in the micro usb or by using a 4th jumper wire to connect the 3.3 volts on the Serial TTL adaptor to the 3.3v pin on the board.

## Flashing

Fire up the flasher and select the correct port and point it to the downloaded FW bin:

  

Hit flash, and you should see something like this:

  

after about a minute or so:

  

pull the power, and move the jumper back to the 3.3v_Bridge. you can leave the cables connected to do a test boot with serial logging if you want. Just plug it back in, and hit the show logs button in the flasher:

you should see something like this if not connected to ethernet, or maybe on it’s first try of connecting:

  

if connected to network, should see something like this:



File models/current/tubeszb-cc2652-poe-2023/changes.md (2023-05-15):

2023-05-15
    Added LEDs to module on DIO6 and DIO7 default to off - controlable with z2m or zha/znp config.
    Modify pin out of the UEXT header pins to alighn with future MGM21/24 boards and furture carrier board.

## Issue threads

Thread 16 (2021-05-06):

USB-to-Serial Bridge chip is used for Tube’s CC2652P2 USB Coordinator?

Hedda, 2021-05-06:
I'm curious about HW specs so wondering which USB-to-Serial Bridge chip exactly is used for Tube’s CC2652P2 USB Coordinator?

Also, wondering if the USB to Serial Bridge chip it is connected via RTS + CTS to CC2652P module for Hardware Flow Control?

I understand that CH340 series (example CH340C and CH340E) by WCH are popular because they are inexpensive, but I also understand that they have fewer features and are also known to have driver issues on Linux and Mac OS (though I read Linux is better now in newer Linux kernel versions).

I understand that FT231 chip by FTDI  or CP2102N by Silicon Labs / Silabs is recommended for more feature and better support:

https://ftdichip.com/products/ft231xs/
https://ftdichip.com/products/ft231xq/

https://www.silabs.com/interface/usb-bridges/classic/device.cp2102
https://www.silabs.com/interface/usb-bridges/classic/device.cp2104
https://www.silabs.com/developers/usb-to-uart-bridge-vcp-drivers
https://www.silabs.com/documents/public/data-sheets/cp2102n-datasheet.pdf
https://www.silabs.com/documents/public/application-notes/an197.pdf
https://www.silabs.com/documents/public/application-notes/an978-cp210x-usb-to-uart-api-specification.pdf
https://www.silabs.com/documents/public/application-notes/AN571.pdf

FYI, I read that the upcoming ZZHP/ZZH2 adapter by Electrolama will use FT231 which has more mature device drivers and will allow them to write a customized string onto the EEPROM of the USB-to-Serial chip (such as for example "Electrolama ZZHP v1.0.0") should make it more plug-and-play friendly and easier for different home automation software to automatically discover and configure without end-user interactions. I understand that a bonus feature in FT231 of allowing users to auto-reset and put the device in bootloader mode via the DTR/RTS pins exposed will enable much easier firmware upgrades for the end-users as they will no longer need to press any buttons to enter bootloader mode, and now bootloader mode can be activated via software from the firmware flasher program software which could make the firmware upgrade procedure more user-friendly.

By the way, have you read this related discussion about hardware standardisation for pins assignments in the community:

https://github.com/Koenkk/Z-Stack-firmware/issues/210

The discussion resulted in this README.md file with a matrix for pins like BSL Trigger Pin, RF Switch Control Pins, LED(s) + Auto-BSL:

https://github.com/Koenkk/Z-Stack-firmware/blob/master/coordinator/Z-Stack_3.x.0/bin/README.md

tube0013, 2021-05-06:
May change in v2 but right now it's a ch340E

Hedda, 2021-05-06:
Related PR -> https://github.com/Koenkk/Z-Stack-firmware/pull/287 (to update the info in mentioned README.md for Koenkk/Z-Stack-firmware).

tube0013, 2021-12-17:
v2 uses CH340B

Closed 2021-12-17.

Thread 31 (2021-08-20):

no network connection

tmottabr, 2021-08-20:
when i plug the controller to an POE port in my switch i get a green light in the switch indicating it is powered.

the controller board i get a red and a yellow light but no connection.

connecting a serial adapter to the header i get this:

`
[15:21:20]ets Jul 29 2019 12:21:46
[15:21:20]
[15:21:20]rst:0x1 (POWERON_RESET),boot:0x1b (SPI_FAST_FLASH_BOOT)
[15:21:20]configsip: 0, SPIWP:0xee
[15:21:20]clk_drv:0x00,q_drv:0x00,d_drv:0x00,cs0_drv:0x00,hd_drv:0x00,wp_drv:0x00
[15:21:20]mode:DIO, clock div:2
[15:21:20]load:0x3fff0018,len:4
[15:21:20]load:0x3fff001c,len:1044
[15:21:20]load:0x40078000,len:8896
[15:21:20]load:0x40080400,len:5828
[15:21:20]entry 0x400806ac
[15:21:20][I][logger:166]: Log initialized
[15:21:20][C][ota:366]: There have been 0 suspected unsuccessful boot attempts.
[15:21:20][I][app:029]: Running through setup()...
[15:21:20][C][uart_esp32:072]: Setting up UART...
[15:21:20][C][switch.gpio:011]: Setting up GPIO Switch 'zRST_gpio'...
[15:21:20][D][switch:025]: 'zRST_gpio' Turning OFF.
[15:21:20][D][switch:045]: 'zRST_gpio': Sending state ON
[15:21:20][D][switch:025]: 'zRST_gpio' Turning OFF.
[15:21:20][C][switch.gpio:011]: Setting up GPIO Switch 'zBSL'...
[15:21:20][D][switch:025]: 'zBSL' Turning OFF.
[15:21:20][D][switch:045]: 'zBSL': Sending state ON
[15:21:20][D][switch:025]: 'zBSL' Turning OFF.
[15:21:20][C][ethernet:025]: Setting up Ethernet...
[15:21:35][W][ethernet:041]: Connecting via ethernet failed! Re-connecting...
[15:21:36][D][esp-idf:000]: E (16109) emac: Timed out waiting for PHY register 0x2 to have value 0x0007(mask 0xffff). Current value 0xffff
[15:21:36]
[15:21:37][D][esp-idf:000]: E (17110) emac: Timed out waiting for PHY register 0x3 to have value 0xc0f0(mask 0xfff0). Current value 0xffff
[15:21:37]
[15:21:37][D][esp-idf:000]: E (17112) emac: Initialise PHY device Timeout
[15:21:37]
[15:21:37][E][ethernet:125]: ETH enable error: -1
[15:21:37][E][component:092]: Component was marked as failed.
`

tube0013, 2021-08-20:
I've seen this with the non PoE boards a few times and have had luck reflashing the fw bin to fix it.

The bin file is the olimex one here: https://github.com/tube0013/tube_gateways/tree/main/esphome

You can reflash over the usb connector with the esphome flasher app. The troubleshooting guide has a guide for the non PoE board but same procedure without the serial converter.

https://github.com/tube0013/tube_gateways/blob/main/Troubleshooting.md

If that doesn't work email net at store (at) tubeszb.com and We'll figure it out.

tmottabr, 2021-08-20:
had already tried using the bin file from here: https://github.com/tube0013/tube_gateways/tree/main/tube_zb_gw_cc2652p2

but no luck.. will take a look on the other link.. thanks..

tmottabr, 2021-08-21:
that fixed.. thanks..

Closed 2021-08-21.

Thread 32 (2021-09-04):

CC2652p2 POE Coordinator ZHA connection issue

glamirand, 2021-09-04:
Hi,

I just purchased a CC2652P2 Based Zigbee to Power Over Ethernet Serial Coordinator V2 to replace a ConBeeII for my Profalux covers.

I deleted all zigbee devices via zha.remove and the ZHA integration itself.
I then re set the ZHA integration according to the instructions (ZNP, socket://ip:6638, 115200, software flow control) and joined my devices to this new gateway.

All went fine except I'm having connection issues between my HA Virtual Machine (hypervised by VMM on a Synology RS1221+) & the gateway, resulting il osme lines in the Debug Log but more embarassing : my covers are slightly moving up and down on each reconnection as I guess the gateway enter permit join after a connection?

**Gateway Log**
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

**HA Log**
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

The coordinator is powered by a Unifi 8 POE switch and is set on the same VLAN as HA (so firewall shouldn't be cocnerned).
I forced the switch port to 100mbits FDX as recommended but this didn't helped.

- Can you confirm that the coordinator should permit join after a connection (is it on the coordinator or ZHA side?), and why?
- Is it possible to disable it?
- Do you have any suggestion to improve the connection stability?

**Disconnections happens variably from every minute to every half hour.
This is quite annoying and can't stay as it.
Any help is very welcome! :)
Thanks!**

tube0013, 2021-09-04:
Hi. This is for sure not the desired behavior for the device.

Let's look at the connection issues before getting into ZHA specific issues.

Could you try to reflash the PoE-ESP32.

You can do this OTA, but I'd rather do it over the usb connection on the board, so it does an erase of the current memory completely first.

The instructions are in this doc for the non-PoE coordinator, but the PoE-esp32 has an onboard serial you only need a micro usb cable (with data).

https://github.com/tube0013/tube_gateways/blob/main/Troubleshooting.md

the FW bin is here: https://github.com/tube0013/tube_gateways/tree/main/tube_poe_coordinator

The the USB port is inside the case on the side of the board. The powered Ethernet **MUST** be removed before using or you will kill the board or your computer.

If that helps great, if not we can try a build with a static IP - this ultimately helped another user with disconnection issues.

glamirand, 2021-09-04:
Hi again,

I've just reflashed the module with the provided binary over USB and a connection issue just happened again :(

Let's try a static IP build then :/

tube0013, 2021-09-04:
Bummer, but lets keep rolling...

instructions to compile with a static IP are here: https://github.com/tube0013/tube_gateways/tree/main/esphome

if you want to give me the ip/gateway/mask IPs I can build and send you as well. just let me know.

glamirand, 2021-09-04:
Just flashed with a static ip build, let's see in the near minutes/hours..

I've noticed the following in the logs :
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
I've seen you recommend to set the switch port configuration to 100mbits/Full Duplex, is there something wrong related to the log entry?

tube0013, 2021-09-04:
I'm not aware of making any recommendations about full duplex or not. I usually do not make any changes on my switch when running the devices.

glamirand, 2021-09-04:
That was actually not you, my bad!
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
https://github.com/Hedda/tube_gateways/commit/e7bdd9cf2a8cfd2684759faf1cc3e6a226e0de70

Anyway, I tried both a static IP and to replace "_" by "-" in the host name to solve esphome compilatio warnings but I'm still having the same disconnection issue :/

MattWestb, 2021-09-04:
Sorry for jumping in :-(

If forcing speed / duplex in one end (of the "cable") the other must being sett to the same.
If leaving one side in auto config it can being problems or if one side is half and the next full duplex and the same for the speed 10 / 100.

So auto on both "ends" or manual and the same in both "ends".

tube0013, 2021-09-04:
are you able to set your switch back to full auto for the port and see if that helps now with a static IP?

I'm a bit perplexed as it seems the ESP is actually staying on line, but the serial connection is closing. I have not heard of anyone with this issue, so it's either the hardware, or something specific with your network config. If hardware we can work that out, but want to fully rule out the network side.

glamirand, 2021-09-04:
> So auto on both "ends" or manual and the same in both "ends".

Thanks for the point, I set the switch back to auto then but no noticeable improvement :/

> are you able to set your switch back to full auto for the port and see if that helps now with a static IP?

I tried, but no more improvement :/

> I'm a bit perplexed as it seems the ESP is actually staying on line, but the serial connection is closing

I do agree! Is there any firmware upgrade of the "real" ZigBee stuff to try?
Any way to troubleshot the zigbee network? Perhaps certain oversized data frames which may end up crashing the stream server part?

I also tried the following things with no success :/
- Changed the VM NIC type (only virtio & e1000 are working, rtl8139 doesn't give HA an IP adress)
- Tried on a physical Raspberry Pi 4 (was my "production setup as of yesterday with a conbee2) : same issue
- Tried on a fresh VM install : always the same
- Tried to lighten the ESP part to allow more cpu time for the serial stream server component by disabling the web server and HA api : no more improvement

> I'm a bit perplexed as it seems the ESP is actually staying on line, but the serial connection is closing

I do agree! Is there any firmware upgrade of the "real" ZigBee stuff to try?
Any way to troubleshot the zigbee network? Perhaps certain oversized data frames which may end up crashing the stream server part?

I also have a ZiGate I may use for sniffing the ZigBee network even if I may need guidance for this, if it can help...

tube0013, 2021-09-04:
the zigbee side really should not come into play with the serial connection.

I'm going to reach out to you via email.

glamirand, 2021-09-05:
>connect it through another switch, even non-PoE

I actually already tried to connect it to another POE/POE+ switch with the same results

I considered EMC based interferences last evening and I tried several things :
- Replace my ethernet patch cable by a cat6 shielded one so the gateway is now "grounded" : I had no issue for the night 👍
- I then realized that I had a temporary cheap and not shielded USB extension (the one to plug your Logitech wireless keybord & mouse receiver) linking my UPS and my NAS so I also switched it for a shielded one, and went back to my unshielded ethernet patch cable.
I also reflashed the ESP, re-enabling HA api and webserver  : it's working fine for more than an hour now 👍

I'll keep you updated after a day of successful function.
If not I'll try to power up the ESP with the internal USB and a non POE switch port before reporting.

Fingers crossed! :)

tube0013, 2021-09-05:
Awesome. Fingers crossed let us know.

tube0013, 2021-09-16:
Closing this as it sounds like it has been resolved

glamirand, 2021-09-23:
>
>
> Closing this as it sounds like it has been resolved

Hi,

Sorry for the delay.

I effectively had no disconnection issue since my last post and cable management which is really nice, thanks for helping! :)

This may be another topic but I still observe my shutters to slightly move up and down (like they do when I open the ZigBee network), once the connection is established with ZHA (basically after booting up homeassistant..)

I think it's more related th the ZHA/ZNP integration than to the router itself.
It's not really big deal but I've never had this behavioir when I was using my ConBee2.

Any thoughts?

Closed 2021-09-16.

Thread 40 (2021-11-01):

Unable to update or connect to zigbee2mqtt with cc2652p2_poe.

Eagleman7, 2021-11-01:
Trying to get the cc2652p2_poe working, however I keep getting this error in zigbee2mqtt:
```
Zigbee2MQTT:error 2021-11-01 17:39:16: Error: Failed to connect to the adapter (Error: SRSP - SYS - ping after 6000ms)
    at ZStackAdapter.start (/app/node_modules/zigbee-herdsman/src/adapter/z-stack/adapter/zStackAdapter.ts:102:27)
    at Controller.start (/app/node_modules/zigbee-herdsman/src/controller/controller.ts:123:29)
    at Zigbee.start (/app/lib/zigbee.ts:63:27)
    at Controller.start (/app/lib/controller.js:116:27)
    at start (/app/index.js:95:5)
```

So I decided to install firmware to see if this resolves the issue. However when I click `Prep the cc2652p2 for firmware update` nothing happens in the debug log. This is after waiting 2 minutes:
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
Switching browsers or incognito also doesnt work. The only button that seems to do something is restart, which it then does.

Anything I can do to resolve this?

tube0013, 2021-11-01:
Hi Sorry for the trouble. If nothing is showing in the Debug log after using any of the buttons above it likely means the connection between the browser and the device has dropped.

You can you try and re-flash the ESP32/ESPHome binary - .bin available here:  https://github.com/tube0013/tube_gateways/tree/main/tube_poe_coordinator

this is done on the Devices web page via the OTA option.

 you can also do it over usb (I like the esphome flasher app) - this method clears out the memory first. the USB port is accessible if you open the case. DO NOT keep powered ethernet plugged in if you use this - there is also a warning on the PCB about this.

Eagleman7, 2021-11-01:
Thanks, the buttons are back!
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
Do I still need to do the update using these files? https://github.com/Koenkk/Z-Stack-firmware/tree/master/coordinator/Z-Stack_3.x.0/bin

tube0013, 2021-11-01:
the zigbee module comes pre-flashed with the latest fw from there, so there should be no need to update it.

when you try to connect z2m to the device, do you see anything in the debug log now?

Eagleman7, 2021-11-01:
Maybe I don't understand the toggle, I need to wait for something to show in the debug log before I can update, right?

tube0013, 2021-11-01:
There is most likely no need to update the fw on the zigbee module. it comes preflashed. the issues you are describing are with the ESP32 device. - getting connected and staying connected.

Are you seeing any logs in the Debug Log in the browser? even when you reboot the device with the button it should show something. It should also show when a serial device connects/disconnects. if nothing is showing we need to troubleshoot the esp32's ethernet connection. maybe try a fw bin with a static ip set.

Eagleman7, 2021-11-01:
I never saw anything appearing in the debug log at all stages.

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

```
[root@control cc2538-bsl]# python3 cc2538-bsl.py -p socket://zigbee-gateway.corp.pootenterprise.com:6638  -evw ../CC1352P2_CC2652P_launchpad_coordinator_20210708.hex
Opening port socket://zigbee-gateway.corp.example.com:6638, baud 500000
Reading data from ../CC1352P2_CC2652P_launchpad_coordinator_20210708.hex
Firmware file: Intel Hex
Connecting to target...
ERROR: Timeout waiting for ACK/NACK after 'Get Status (0x23)'
```

tube0013, 2021-11-01:
the Firmware update toggle runs a script on the ESP32 that toggles on the BSL button, toggles the Reset of the zigbee module, then waits about 10 secs releases the BSL, and prints a message to use the command line update tool to flash the module.

Again it shouldn't be necessary though, I flash all modules and test them, then add them to the boards, test again through the esp32 and then reset the NVRAM all over the ethernet connection before shipping the devices.

Eagleman7, 2021-11-01:
Lets skip the firmware through cc2538-bsl.pu for now then :). zigbee2mqtt is still having issues connecting:
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

tube0013, 2021-11-01:
is Z2M pointing to an IP or a hostname? if hostname try the ip

Eagleman7, 2021-11-01:
Tried using IP, same problem :(

```
advanced:
  homeassistant_discovery_topic: homeassistant
  homeassistant_status_topic: homeassistant/status
  last_seen: ISO_8601
  log_level: info
  log_output:
  - console
  network_key: GENERATE
  pan_id: GENERATE
device_options:
  retain: true
experimental:
  new_api: true
frontend:
  port: 8080
homeassistant: true
mqtt:
  base_topic: zigbee2mqtt
  include_device_information: true
  password: admin
  server: mqtt://mosquitto.home.svc.cluster.local
  user: admin
permit_join: true
serial:
  port: tcp://192.168.3.10:6638
```

Can I test that port from my computer instead, to see if something is running on that port?

tube0013, 2021-11-01:
yes, you can try a serial program that can connect to a raw serial port over network connection. I use a Mac App called Serial.

I suspect the ESP32 is not staying connected - this would explain nothing in the debug log window as well.

Something you can try - use the internal USB port to power the device via a computer and use an UN-Powered ethernet cable (this is imperative)

this will allow you to use a serial app on the computer to monitor the ESPHOME console log and not have to rely on the network connection.

Be sure the ethernet connection is un-powered if using the USB - if not there will be smoke.

Eagleman7, 2021-11-01:
Can I safely tilt out the ESP board? I am cannot find an USB cable that will fit, there is only 3mm room for the connector. I also turned off the poe on the switch and the device is now turned off. Should I be able to connect using PuTTy, if so, on what IP?

tube0013, 2021-11-01:
putty should work.

the only thing really holding the board down is friction, and the SMA antenna connector - it may be best to undo the retaining nut there and just remove the board.

tube0013, 2021-11-01:
For putty you'd want to do something like this to connect over IP Serial:

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

Eagleman7, 2021-11-01:
No smoke (yet)!
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

However I cannot seem to get anything on port 6638 using raw:
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

Eagleman7, 2021-11-01:
Ow, I just got some input, but its not readable by putty:
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

tube0013, 2021-11-01:
try and reflash the ESP32 bin over USB with the esphome app

https://github.com/esphome/esphome-flasher/releases

leave the ethernet connected and this the esphome log will show in the app after the flash.

Eagleman7, 2021-11-01:
It cannot find a suitable serial port, it is connected to the PC now:
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

Eagleman7, 2021-11-01:
I cannot try on the Mac as well because I currently do not have an USB hub with USB A :(

tube0013, 2021-11-01:
USB cable has data, and isn't power only?  By the way thanks for your patience with this.

Eagleman7, 2021-11-01:
It seems I am missing a driver :)
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

Thank you for helping me as well :)

tube0013, 2021-11-01:
Driver for windows is here:

https://www.olimex.com/Products/Breadboarding/BB-CH340T/resources/CH341SER.zip

Eagleman7, 2021-11-01:
Thanks! Got some more verbosity this time :)

From the flasher software:
```
Using 'COM5' as serial port.
Connecting................
Detecting chip type... Unsupported detection protocol, switching and trying again...
Connecting..6 %)Writing at 0x000e8df6... (100 %)Wrote 904512 bytes (501591 compressed) at 0x00010000 in 12.8 seconds (effective 565.3 kbit/s)...
Hash of data verified.

Leaving...
Hard Resetting...
Hard resetting via RTS pin...
Done! Flashing is complete!
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
tube0013, 2021-11-01:
try and connect z2m now.

Eagleman7, 2021-11-01:
```
Using '/data' as data directory
Zigbee2MQTT:info  2021-11-01 19:53:58: Logging to console only'
Zigbee2MQTT:info  2021-11-01 19:53:58: Starting Zigbee2MQTT version 1.21.2 (commit #4492212
)
Zigbee2MQTT:info  2021-11-01 19:53:58: Starting zigbee-herdsman (0.13.149)
Zigbee2MQTT:info  2021-11-01 19:54:03: zigbee-herdsman started (resumed)
Zigbee2MQTT:info  2021-11-01 19:54:03: Coordinator firmware version: '{"meta":{"maintrel":1,"majorrel":2,"minorrel":7,"product":1,"revision":20210708,"transportrev":2},"type":"zStack3x0"}'
Zigbee2MQTT:info  2021-11-01 19:54:03: Currently 0 devices are joined:
Zigbee2MQTT:info  2021-11-01 19:54:03: Zigbee: disabling joining new devices.
Zigbee2MQTT:info  2021-11-01 19:54:04: Connecting to MQTT server at mqtt://mosquitto.home.svc.cluster.local
Zigbee2MQTT:info  2021-11-01 19:54:04: Connected to MQTT server
Zigbee2MQTT:info  2021-11-01 19:54:04: MQTT publish: topic 'zigbee2mqtt/bridge/state', payload 'online'
Zigbee2MQTT:info  2021-11-01 19:54:04: Started frontend on port 0.0.0.0:8080
```

Flasher logs:
```
[19:53:59][D][streamserver:085]: New client connected from 192.168.5.20
```

tube0013, 2021-11-01:
progress!

now I'd try PoE again (with USB disconnected)

Eagleman7, 2021-11-01:
zigbee2mqtt is able to connect, but I dont think the debug log is working on the webui.

tube0013, 2021-11-01:
Good that the z2m is working now. but very odd nothing in the web debug log.. I've actually never seen that occur beyond having the webpage up when I've unpowered a device.  To be honest as long as z2m is working you should be good. the PCB has a BLS button on it to get into the module bootloader mode for FW flashing.

Another thing you could try is pulling down the esphome .yaml for the device and adding it to your esphome folder (if you have it) then ESPHome should show the device in it's frontend, and you can us the Logs button there to connect to to the logs (uses same api connection as the web portal so may or may not work).

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

Eagleman7, 2021-11-04:
Thanks for your help @tube0013! I do have ESPhome running in my network, so that is worth investigating. I am not sure if I need to do this firmware update https://github.com/Koenkk/Z-Stack-firmware/tree/master/coordinator/Z-Stack_3.x.0/bin ?

tube0013, 2021-11-04:
It already has the latest build installed. So really no need.

tube0013, 2021-11-29:
Copy of the yaml is here:

https://github.com/tube0013/tube_gateways/tree/main/esphome

tube0013, 2021-12-17:
how are things going @Eagleman7 okay to close this?

Eagleman7, 2021-12-23:
Hi @tube0013,

Its been working perfect for weeks now, thanks!

Closed 2021-12-23.

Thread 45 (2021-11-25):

tube-zb-gw-cc2652p2 compile failed in latest esphome

kylinfedora, 2021-11-25:
### esphome yaml file:
```
esphome:
  name: tube-zb-gw-cc2652p2
  platform: ESP32
  board: esp-wrover-kit

external_components:
  - source: github://oxan/esphome-stream-server

#  includes:
#    - stream_server.h
#    - stream_server.cpp

ethernet:
  type: LAN8720
  mdc_pin: GPIO23
  mdio_pin: GPIO18
  clk_mode: GPIO0_IN
  phy_addr: 1
  power_pin: GPIO16

  # Optional manual IP
  manual_ip:
    static_ip: 192.168.xxx.xxx
    gateway: 192.168.xxx.x
    subnet: 255.255.255.0
    dns1: 192.168.xxx.x

  domain: .xxxx

# Enable logging
logger:
  level: DEBUG

# Enable Home Assistant API
api:
  reboot_timeout: 0s

ota:

web_server:
  port: 80

script:
  - id: fw_update_mode
    then:
      - switch.turn_on: zBSL
      - delay: 1s
      - switch.turn_on: zRST_gpio
      - delay: 1s
      - switch.turn_off: zRST_gpio
      - logger.log: "Delaying ~10 seconds for cc2652p2 to settle"
      - delay: 11s
      - switch.turn_off: zBSL
      - logger.log: "Please try update with cc-bsl tool now"
      - logger.log: "cc-bsl usage: cc-bsl.py -p socket://ip-of-gw:6638 -evw firmware.hex"

switch:
  - platform: restart
    name: "Restart the Gateway"

  - platform: gpio
    pin: 33
    id: zRST_gpio
    inverted: yes
    restore_mode: ALWAYS_OFF
  - platform: template
    name: "zRST"
    id: zRST
    turn_on_action:
      - switch.turn_on: zRST_gpio
      - delay: 15ms
      - switch.turn_off: zRST_gpio

  - platform: gpio
    pin: 32
    name: "zBSL"
    id: zBSL
    inverted: yes
    restore_mode: ALWAYS_OFF

  - platform: template
    name: "Prep the cc2652p2 for firmware update"
    turn_on_action:
      - script.execute: fw_update_mode
    turn_off_action:
      - switch.toggle: zRST

uart:
  id: uart_bus
  rx_pin: GPIO5
  tx_pin: GPIO17
  baud_rate: 115200

custom_component:
  - lambda: |-
      auto stream_server = new StreamServerComponent(id(uart_bus));
      return {stream_server};
```

###  build info:

```
INFO Reading configuration /config/esphome/tube-zb-gw-cc2652p2.yaml...
INFO Generating C++ source...
INFO Core config or version changed, cleaning build files...
INFO Compiling app...
Processing tube-zb-gw-cc2652p2 (board: esp-wrover-kit; framework: arduino; platform: platformio/espressif32 @ 3.3.2)
--------------------------------------------------------------------------------
HARDWARE: ESP32 240MHz, 320KB RAM, 4MB Flash
Dependency Graph
|-- <AsyncTCP-esphome> 1.2.2
|-- <WiFi> 1.0
|-- <FS> 1.0
|-- <Update> 1.0
|-- <ESPAsyncWebServer-esphome> 2.1.0
|   |-- <AsyncTCP-esphome> 1.2.2
|-- <ArduinoJson-esphomelib> 5.13.3
|-- <ESPmDNS> 1.0
Compiling /data/tube-zb-gw-cc2652p2/.pioenvs/tube-zb-gw-cc2652p2/src/esphome/components/api/api_connection.cpp.o
Compiling /data/tube-zb-gw-cc2652p2/.pioenvs/tube-zb-gw-cc2652p2/src/esphome/components/api/api_frame_helper.cpp.o
Compiling /data/tube-zb-gw-cc2652p2/.pioenvs/tube-zb-gw-cc2652p2/src/esphome/components/api/api_pb2.cpp.o
Compiling /data/tube-zb-gw-cc2652p2/.pioenvs/tube-zb-gw-cc2652p2/src/esphome/components/api/api_pb2_service.cpp.o
Compiling /data/tube-zb-gw-cc2652p2/.pioenvs/tube-zb-gw-cc2652p2/src/esphome/components/api/api_server.cpp.o
Compiling /data/tube-zb-gw-cc2652p2/.pioenvs/tube-zb-gw-cc2652p2/src/esphome/components/api/list_entities.cpp.o
Compiling /data/tube-zb-gw-cc2652p2/.pioenvs/tube-zb-gw-cc2652p2/src/esphome/components/api/proto.cpp.o
Compiling /data/tube-zb-gw-cc2652p2/.pioenvs/tube-zb-gw-cc2652p2/src/esphome/components/api/subscribe_state.cpp.o
Compiling /data/tube-zb-gw-cc2652p2/.pioenvs/tube-zb-gw-cc2652p2/src/esphome/components/api/user_services.cpp.o
Compiling /data/tube-zb-gw-cc2652p2/.pioenvs/tube-zb-gw-cc2652p2/src/esphome/components/api/util.cpp.o
Compiling /data/tube-zb-gw-cc2652p2/.pioenvs/tube-zb-gw-cc2652p2/src/esphome/components/esp32/core.cpp.o
Compiling /data/tube-zb-gw-cc2652p2/.pioenvs/tube-zb-gw-cc2652p2/src/esphome/components/esp32/gpio_arduino.cpp.o
Compiling /data/tube-zb-gw-cc2652p2/.pioenvs/tube-zb-gw-cc2652p2/src/esphome/components/esp32/gpio_idf.cpp.o
Compiling /data/tube-zb-gw-cc2652p2/.pioenvs/tube-zb-gw-cc2652p2/src/esphome/components/esp32/preferences.cpp.o
Compiling /data/tube-zb-gw-cc2652p2/.pioenvs/tube-zb-gw-cc2652p2/src/esphome/components/ethernet/ethernet_component.cpp.o
Compiling /data/tube-zb-gw-cc2652p2/.pioenvs/tube-zb-gw-cc2652p2/src/esphome/components/gpio/switch/gpio_switch.cpp.o
Compiling /data/tube-zb-gw-cc2652p2/.pioenvs/tube-zb-gw-cc2652p2/src/esphome/components/json/json_util.cpp.o
Compiling /data/tube-zb-gw-cc2652p2/.pioenvs/tube-zb-gw-cc2652p2/src/esphome/components/logger/logger.cpp.o
Compiling /data/tube-zb-gw-cc2652p2/.pioenvs/tube-zb-gw-cc2652p2/src/esphome/components/md5/md5.cpp.o
Compiling /data/tube-zb-gw-cc2652p2/.pioenvs/tube-zb-gw-cc2652p2/src/esphome/components/mdns/mdns_component.cpp.o
Compiling /data/tube-zb-gw-cc2652p2/.pioenvs/tube-zb-gw-cc2652p2/src/esphome/components/mdns/mdns_esp32_arduino.cpp.o
Compiling /data/tube-zb-gw-cc2652p2/.pioenvs/tube-zb-gw-cc2652p2/src/esphome/components/mdns/mdns_esp8266.cpp.o
Compiling /data/tube-zb-gw-cc2652p2/.pioenvs/tube-zb-gw-cc2652p2/src/esphome/components/mdns/mdns_esp_idf.cpp.o
Compiling /data/tube-zb-gw-cc2652p2/.pioenvs/tube-zb-gw-cc2652p2/src/esphome/components/network/util.cpp.o
Compiling /data/tube-zb-gw-cc2652p2/.pioenvs/tube-zb-gw-cc2652p2/src/esphome/components/ota/ota_backend_arduino_esp32.cpp.o
Compiling /data/tube-zb-gw-cc2652p2/.pioenvs/tube-zb-gw-cc2652p2/src/esphome/components/ota/ota_backend_arduino_esp8266.cpp.o
Compiling /data/tube-zb-gw-cc2652p2/.pioenvs/tube-zb-gw-cc2652p2/src/esphome/components/ota/ota_backend_esp_idf.cpp.o
Compiling /data/tube-zb-gw-cc2652p2/.pioenvs/tube-zb-gw-cc2652p2/src/esphome/components/ota/ota_component.cpp.o
Compiling /data/tube-zb-gw-cc2652p2/.pioenvs/tube-zb-gw-cc2652p2/src/esphome/components/restart/restart_switch.cpp.o
Compiling /data/tube-zb-gw-cc2652p2/.pioenvs/tube-zb-gw-cc2652p2/src/esphome/components/script/script.cpp.o
Compiling /data/tube-zb-gw-cc2652p2/.pioenvs/tube-zb-gw-cc2652p2/src/esphome/components/socket/bsd_sockets_impl.cpp.o
Compiling /data/tube-zb-gw-cc2652p2/.pioenvs/tube-zb-gw-cc2652p2/src/esphome/components/socket/lwip_raw_tcp_impl.cpp.o
Compiling /data/tube-zb-gw-cc2652p2/.pioenvs/tube-zb-gw-cc2652p2/src/esphome/components/switch/automation.cpp.o
Compiling /data/tube-zb-gw-cc2652p2/.pioenvs/tube-zb-gw-cc2652p2/src/esphome/components/switch/switch.cpp.o
Compiling /data/tube-zb-gw-cc2652p2/.pioenvs/tube-zb-gw-cc2652p2/src/esphome/components/template/switch/template_switch.cpp.o
Compiling /data/tube-zb-gw-cc2652p2/.pioenvs/tube-zb-gw-cc2652p2/src/esphome/components/uart/uart.cpp.o
Compiling /data/tube-zb-gw-cc2652p2/.pioenvs/tube-zb-gw-cc2652p2/src/esphome/components/uart/uart_component.cpp.o
Compiling /data/tube-zb-gw-cc2652p2/.pioenvs/tube-zb-gw-cc2652p2/src/esphome/components/uart/uart_component_esp32_arduino.cpp.o
Compiling /data/tube-zb-gw-cc2652p2/.pioenvs/tube-zb-gw-cc2652p2/src/esphome/components/uart/uart_component_esp8266.cpp.o
Compiling /data/tube-zb-gw-cc2652p2/.pioenvs/tube-zb-gw-cc2652p2/src/esphome/components/uart/uart_component_esp_idf.cpp.o
Compiling /data/tube-zb-gw-cc2652p2/.pioenvs/tube-zb-gw-cc2652p2/src/esphome/components/uart/uart_debugger.cpp.o
Compiling /data/tube-zb-gw-cc2652p2/.pioenvs/tube-zb-gw-cc2652p2/src/esphome/components/web_server/web_server.cpp.o
Compiling /data/tube-zb-gw-cc2652p2/.pioenvs/tube-zb-gw-cc2652p2/src/esphome/components/web_server_base/web_server_base.cpp.o
Compiling /data/tube-zb-gw-cc2652p2/.pioenvs/tube-zb-gw-cc2652p2/src/esphome/core/application.cpp.o
Compiling /data/tube-zb-gw-cc2652p2/.pioenvs/tube-zb-gw-cc2652p2/src/esphome/core/color.cpp.o
Compiling /data/tube-zb-gw-cc2652p2/.pioenvs/tube-zb-gw-cc2652p2/src/esphome/core/component.cpp.o
Compiling /data/tube-zb-gw-cc2652p2/.pioenvs/tube-zb-gw-cc2652p2/src/esphome/core/controller.cpp.o
Compiling /data/tube-zb-gw-cc2652p2/.pioenvs/tube-zb-gw-cc2652p2/src/esphome/core/entity_base.cpp.o
Compiling /data/tube-zb-gw-cc2652p2/.pioenvs/tube-zb-gw-cc2652p2/src/esphome/core/helpers.cpp.o
Compiling /data/tube-zb-gw-cc2652p2/.pioenvs/tube-zb-gw-cc2652p2/src/esphome/core/log.cpp.o
Compiling /data/tube-zb-gw-cc2652p2/.pioenvs/tube-zb-gw-cc2652p2/src/esphome/core/scheduler.cpp.o
Compiling /data/tube-zb-gw-cc2652p2/.pioenvs/tube-zb-gw-cc2652p2/src/esphome/core/util.cpp.o
Compiling /data/tube-zb-gw-cc2652p2/.pioenvs/tube-zb-gw-cc2652p2/src/main.cpp.o
Generating partitions /data/tube-zb-gw-cc2652p2/.pioenvs/tube-zb-gw-cc2652p2/partitions.bin
Compiling /data/tube-zb-gw-cc2652p2/.pioenvs/tube-zb-gw-cc2652p2/lib528/AsyncTCP-esphome/AsyncTCP.cpp.o
Compiling /data/tube-zb-gw-cc2652p2/.pioenvs/tube-zb-gw-cc2652p2/lib64d/WiFi/ETH.cpp.o
Compiling /data/tube-zb-gw-cc2652p2/.pioenvs/tube-zb-gw-cc2652p2/lib64d/WiFi/WiFi.cpp.o
Compiling /data/tube-zb-gw-cc2652p2/.pioenvs/tube-zb-gw-cc2652p2/lib64d/WiFi/WiFiAP.cpp.o
Compiling /data/tube-zb-gw-cc2652p2/.pioenvs/tube-zb-gw-cc2652p2/lib64d/WiFi/WiFiClient.cpp.o
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
tube0013, 2021-11-25:
Dupe of #44 will have fix soon

kylinfedora, 2021-11-29:
I think just config error,
change the file like tihs, build ok, but  not test the fw
#custom_component:
#  - lambda: |-
#      auto stream_server = new StreamServerComponent(id(uart_bus));
#      return {stream_server};
stream_server:
   uart_id: uart_bus
   port: 6638

kylinfedora, 2021-12-13:
I build with this config，build is ok, who can test?
```
esphome:
  name: tube-zb-gw-cc2652p2
  platform: ESP32
  board: esp-wrover-kit

external_components:
  - source: github://oxan/esphome-stream-server

#  includes:
#    - stream_server.h
#    - stream_server.cpp

ethernet:
  type: LAN8720
  mdc_pin: GPIO23
  mdio_pin: GPIO18
  clk_mode: GPIO0_IN
  phy_addr: 1
  power_pin: GPIO16

# Enable logging
logger:
  level: DEBUG

# Enable Home Assistant API
api:
  reboot_timeout: 0s

ota:

web_server:
  port: 80

script:
  - id: fw_update_mode
    then:
      - switch.turn_on: zBSL
      - delay: 1s
      - switch.turn_on: zRST_gpio
      - delay: 1s
      - switch.turn_off: zRST_gpio
      - logger.log: "Delaying ~10 seconds for cc2652p2 to settle"
      - delay: 11s
      - switch.turn_off: zBSL
      - logger.log: "Please try update with cc-bsl tool now"
      - logger.log: "cc-bsl usage: cc-bsl.py -p socket://ip-of-gw:6638 -evw firmware.hex"

switch:
  - platform: restart
    name: "Restart the Gateway"

  - platform: gpio
    pin: 33
    id: zRST_gpio
    inverted: yes
    restore_mode: ALWAYS_OFF
  - platform: template
    name: "zRST"
    id: zRST
    turn_on_action:
      - switch.turn_on: zRST_gpio
      - delay: 15ms
      - switch.turn_off: zRST_gpio

  - platform: gpio
    pin: 32
    name: "zBSL"
    id: zBSL
    inverted: yes
    restore_mode: ALWAYS_OFF

  - platform: template
    name: "Prep the cc2652p2 for firmware update"
    turn_on_action:
      - script.execute: fw_update_mode
    turn_off_action:
      - switch.toggle: zRST

uart:
  id: uart_bus
  rx_pin: GPIO5
  tx_pin: GPIO17
  baud_rate: 115200

#custom_component:
# - lambda: |-
#     auto stream_server = new StreamServerComponent(id(uart_bus));
#     return {stream_server};
stream_server:
   uart_id: uart_bus
   port: 6638
```

tube0013, 2021-12-17:
confirmed a similar build works (added the feature to adopt a device as well).

2652 v1 and PoE are adapted so far. v2 used a fork of the serial server with some extra features so looking as to how to get those working still.

https://github.com/tube0013/tube_gateways/blob/main/esphome

tube0013, 2022-01-06:
Notice: I have been unable to flash the cc2652 using the newer compiled ESPHome Firmware. I am unsure if the serial component changes or general esphome changes are the cause, but rolling back the firmware to the original binary allows the firmware to flash with no issues.

https://github.com/tube0013/tube_gateways/blob/main/tube_poe_coordinator/tube_zb_gw_cc2652p2_oliemex_poe.bin

Closed 2021-12-17.

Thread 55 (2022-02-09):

Updated ESPHome on my tube-zb-gw-cc2652p2-v2 and now it doesn't work :)

hvddrift, 2022-02-09:
I did exactly the same as:

> So I think I messed up my coordinator, but not really sure how. It is the tube-zb-gw-cc2652p2-v2 model :)
>
> I updated ESPHome to the tube-zb-gw-cc2652p2-v2_2022_01_15.bin that was posted on GitHub, that worked fine, but then I could not connect to the serial port on 6638. I rolled it back to tube-zb-gw-cc2652p2-v2_2021_09_17.bin which was what I wasn on previously, but it still did not work. I attempted to flash new zstack code onto it, but that just fails - I was able to update it to this version of zstack a few days ago without problems.

But I am unable to get the device into boot mode.

I have the jumpers in this postion

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

I hold down boot, plug in the device, but my windows PC does not see it.

Any suggestions?

tube0013, 2022-02-09:
Windows needs the ch340 serial driver. Does device show in device manager?

hvddrift, 2022-02-09:
No, but I did add the driver

hvddrift, 2022-02-09:
Just want to make sure I am doing it correctly.

Photo of jumpers and boot button I am pressing.

I hold the boot down, plug into the USB and release. I get no sound of a USB device being plugged in like other devices.

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

tube0013, 2022-02-09:
that's all good, but you don't have the ESP32 module on the board so there is nothing to put into boot mode or talk to over serial.

hvddrift, 2022-02-09:
Ok. Old age mistake there. I could not read the PCB so I was took off what I thought was just the ethernet connector,

Let's see if I can get it to work.

P.S I feel both embarrassed and stuip

tube0013, 2022-02-09:
no worries. and not discounting something could be wrong.

Also I saw yo post on twitter, and there is no compatible PoE module with this device. The PoE model I sell is has a different esp32 which has a different pin out, and is much larger. If you want poe I'd advise getting a PoE > micro usb + ethernet splitter.

hvddrift, 2022-02-09:
Ok... Still no luck. I have an adapter
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

I could try to connect with tx,rx, gnd and 3.3

tube0013, 2022-02-09:
yes, you can give that a try. is the board getting power over usb? (lights on the esp32 light up at all?)

hvddrift, 2022-02-09:
Just plugged into a USB power board to check. No lights there either.

tube0013, 2022-02-09:
nothing n the esp32? there will be no lit leds on the tubeszb pcb, but should see some on the esp32 when powered up.

It is possible the usb connector has come loose. and this could be causing the issues - no power or serial.

can you try to power the esp32 module separately with the adaptor you showed?

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

hvddrift, 2022-02-09:
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

Ok, we can power the esp32 module

hvddrift, 2022-02-09:
And a close up of the USB connector
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

tube0013, 2022-02-09:
okay thanks.

that's a better picture than I could have gotten ;)

do you have a multimeter by chance?

hvddrift, 2022-02-09:
yes

tube0013, 2022-02-09:
could try and update the FW on the router, new build I put out ups the tx strengh a little bit.

hvddrift, 2022-02-09:
And that's using this method correct?

https://github.com/tube0013/tube_gateways#zigbee-module-firmware-updates

hvddrift, 2022-02-09:
And that's using this method, right?

https://github.com/tube0013/tube_gateways#zigbee-module-firmware-updates

But with a serial adapter. Is there a page with instructions for this?

tube0013, 2022-02-09:
I actually just add the router specific flashing guide here:

https://github.com/tube0013/tube_gateways/tree/main/tube_cc_router#flashing-the-router

hvddrift, 2022-02-09:
Where you able to test if the 3.3 v is ok for the short term?

tube0013, 2022-02-09:
no still in my office. can check in a few hours.. I have to build some devices as well before I can confirm as I don't have any on hand.

tube0013, 2022-02-10:
confirmed 3.3v from a usb serial adapter powers the board up including the esp32 when using the 3.3v and GND pins on the PCB.

hvddrift, 2022-02-10:
Ok, will test now.

However, I wanted to update the routers first (as I wont have my serial adapter) and I have tested with both a Linux and Windows machine and I get this error on the flash attempt.

```
Opening port COM3, baud 500000
Reading data from tubeszb_router_20220111.hex
Your firmware looks like an Intel Hex file
ERROR: Hex file contains invalid record at line 7
```

tube0013, 2022-02-10:
my bad, I should have zipped the .hex file. I just replaced it with a zipped version,  pull this down and unzip and use it to flash I think that will solve this.

https://github.com/tube0013/tube_gateways/raw/main/tube_cc_router/firmware/tubeszb_router_20220111.hex.zip

hvddrift, 2022-02-10:
Getting closer....

```
Opening port COM3, baud 500000
Reading data from tubeszb_router_20220111.hex.zip
Cannot auto-detect firmware filetype: Assuming .bin
Connecting to target...
CC1350 PG2.0 (7x7mm): 352KB Flash, 20KB SRAM, CCFG.BL_CONFIG at 0x00057FD8
Primary IEEE Address: 00:12:4B:00:23:7D:FC:D5
    Performing mass erase
Erasing all main bank flash sectors
    Erase done
Writing 193671 bytes starting at address 0x00000000
ERROR: Invalid data size: 193671. Size must be a multiple of 4.
```

hvddrift, 2022-02-10:
Nope, had to unzip.... Flashing now

tube0013, 2022-02-10:
looks good. you'll need this essentially factory resets them as well, so you'll need to rejoin them once coordinator is back up.

hvddrift, 2022-02-10:
And I think I will need to solder a header on the board first. This is where I connect the 3.3 and GND to correct?

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

tube0013, 2022-02-10:
correct.

hvddrift, 2022-02-10:
OK... All seems to be up. I was not able to keep my devices, But I thought I might as well start of right.

From a tweet I posted. Would you change the channel?
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

hvddrift, 2022-02-10:
And the first device I added wad the freshly flashed router. Its 4 feet way.  But RSSI is Unknown.

Just not sure if this is a symptom of bigger issues.

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

hvddrift, 2022-02-13:
Made a big change and switched to zigbee2mqtt.

At this point I could not be happier. I find it so much better and more robust that ZHA.

Just seeing if or how we can rectify the usb tracing issue. Can I get a replacement board?

tube0013, 2022-02-13:
can you send me an email at my store email - store @ tubeszb.com and we can figure something out.

thansk!

Closed 2022-02-14.

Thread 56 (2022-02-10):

PoE Coordinator unresponsive

scruloose, 2022-02-10:
Hi there! I bought one of your PoE Zigbee Coordinators recently (Order No. 729000642), and I'm (somewhat belatedly) trying to get it up and running.

I'm a fairly competent Linux admin, but *completely* new to Zigbee and home automation, so it's entirely possible I'm missing something really basic here, but I can't seem to get past step 0 with this device. I don't have mDNS, but I have dnsmasq all set up on my router and I'm very familiar with setting up static DHCP leases. I was expecting the coordinator to request a DHCP lease from the router as soon as it was plugged in to PoE, so I could grab the MAC address from the router's logs and give it a static entry in my dhcp-hosts file just like any other client on the LAN.

What's actually happening is nothing. I've tried connecting it directly to an Ethernet port on my Edgerouter and turning on PoE to that port, and I see the PoE indicator light come on, but the link indicator just stays dark. I've also tried connecting it to an Ethernet switch elsewhere in the house via a PoE injector, with similar results: the PoE injector's power LED comes on, but the link indicator LED on the switch stays dark. In the name of thoroughness, I've tried three different Ethernet cables. Looking at the logs for dnsmasq, no activity at all shows up when I plug in the co-ordinator. I've tried leaving it plugged in for ~30 minutes and nothing changes.

Is there something I'm missing, or some obvious troubleshooting I should try? For reference, I have near zero expertise on the hardware side of things.

scruloose, 2022-02-10:
Confirmed. Popping off the cover while it's connected to PoE, there are no lights lit up.

scruloose, 2022-02-10:
Ah, okay. I see I'm going to have to dismantle the antenna connector and take the board out of the case to access the microUSB port. I'll try that next and let you know what happens, but it won't be today.

tube0013, 2022-02-10:
Okay. Just so you know where this is going. I am assuming it will work over usb.

We can try re-flashing the ESP32 over usb and see if that sorts it out. If not, I'll do and exchange. I've had a few PoE modules exhibit this, but it has been usually straightaway, and they haven't made it out the door as I test all over PoE before shipping.

thanks for your patience.

scruloose, 2022-02-11:
As you expected, when connected over USB, the lights come on and /dev/ttyUSB0 appears on the host machine. When connected to both USB and  (regular, non-PoE) Ethernet, it grabs a DHCP lease and I can reach the ESPHome web interface.

Now should I follow the *Zigbee Module Firmware Updates* instructions from [here](https://github.com/tube0013/tube_gateways)? Or do you have a different process in mind?

tube0013, 2022-02-11:
Pretty much

Esphome firmware for the PoE unit is here: https://github.com/tube0013/tube_gateways/tree/main/tube_poe_coordinator (bin file)

Recommend the standalone esphome flasher if you don't have something else you are use.

This shouldn't take long and if it doesn't work will get the exchange going.

tube0013, 2022-02-11:
Edited the above a few times 🤦‍♂️

scruloose, 2022-02-11:
Haha, okay.  Just to be sure I'm not about to do something stupid, let me confirm:
* When you say "the standalone esphome flasher", you mean the web interface on the device at `http://tube-zb-gw-cc2652p2-poe/`, yes?
* And if so, do I need to do the two-step process of "prep for firmware update" and then run `cc2538-bsl programmer`? Or can I just click the OTA upgrade button and browse to the bin file I got from the link you just posted?

I definitely don't have a firmware flashing tool I'm used to using, no. ;-)

tube0013, 2022-02-11:
Sorry for the confusion.

I'm mean this one:

https://github.com/esphome/esphome-flasher

It will do a full erase vs the one in the web hi on the device.

The toggles on the web ui relate to doing Zigbee module fw updates.

The coordinators are made of 2 components both with their own firmware so it can be confusing.

Here we are dealing with the esp32 which is using esphome.

scruloose, 2022-02-11:
That made no difference, I'm afraid.

For whatever reason, it took several tries to get a successful flash… but it did ultimately report success then reboot and display the whole bootup log in the console.

The symptoms remain exactly the same: when connected to PoE, there's no activity, no LED indicators or anything.

tube0013, 2022-02-11:
Okay. Send me an email at store @ tubeszb.com. So I can find your order and I'll get a replacement out today.

Thanks for going through the testing steps.

scruloose, 2022-02-11:
Done!

And no problem. It would have been a win for me too if we'd been able to sort it out without having to wait for a replacement to get here. It was worth a try!

scruloose, 2022-03-01:
Update: I received the replacement coordinator and plugged it into the PoE injector, and got no response (no DHCP request, no LEDs light up; nothing).

I haven't yet popped this one out of its case to try powering it from microUSB, but I thought I should let you know the preliminary result anyway.

Now I'm wondering whether there are incompatible PoE voltages or something. My only PoE gear is a Ubiquiti AP connected to a Ubiquiti router, so it was just plug and play, but... what are the odds that two PoE modules in a row spontaneously died in transit after you tested them, right? It strikes me as more likely that whatever the PoE module in the coordinator is, it's not playing well with whatever PoE supply Ubiquiti uses. I'll let you know what happens when I try the new coordinator on USB power, and I guess I'll look up the specs on the PoE output for the Ubiquiti stuff in case that's helpful.

tube0013, 2022-03-01:
Wow, yeah, that doesn't seem like a coincidence.

the Olimex-ESP32-POE:

ESP32-PoE is an IoT WIFI/BLE/Ethernet development board with Power-Over-Ethernet feature. The PoE is handled by TPS2375PW chip (Si3402-B in older revisions) that is IEEE 802.3-compliant, including pre-standard (legacy) PoE support. The PoE powering requires at least 37V DC to operate successfully. The board takes power from the Ethernet cable and can be expanded with sensors and actuators. Perfect solution for Internet-of-Things projects.

Not really sure why an ubiquity poe switch would be any issue. I have one that I can check when next home. - I don't use it generally when testing as it's powering some APs and Cams.

scruloose, 2022-03-01:
From the manual for my Edgerouter:

Feature | Specification
--- | ---
Max. Total PoE Output | 50W @ 24V
PoE Output | Passive 24V (Pins 4, 5+; 7, 8‑)

So I guess that explains it. There's probably nothing wrong with either of the coordinators, though I'll have to get my hands on a proper standards-compliant PoE injector to find out for sure, and you might want to add a note to the product listing. Ubiquiti's pretty popular, and they're not the only ones using [nonstandard implementations](https://en.wikipedia.org/wiki/Power_over_Ethernet#Non-standard_implementations) of PoE, as it turns out.

tube0013, 2022-03-01:
interesting.  I have an injector that came with one of the Unifi AP's that I've used before. also have a a pair these TP-Link switches I use for testing them.

https://www.amazon.com/gp/product/B076PRM2C5

scruloose, 2022-03-06:
Yeah, it looks like Ubiquiti has used "Passive 24V" in some of their products and proper 802.3 PoE in others. I've been mostly very happy with Ubiquiti, and I'd like to think all their new PoE gear will be 802.3, but who knows.

With all the supply issues going on at the moment, it was ridiculously hard to find *any* consumer-priced switch with 802.3 PoE and tagged VLAN capability available in Canada, but I finally managed to order this [Netgear switch](https://www.netgear.com/ca-en/business/wired/switches/plus/gs108pe/). In theory, that'll be here in a few days, and then I'll be able to verify the coordinators and send one back to you.

tube0013, 2022-03-06:
Good to know for sure, I updated the little paper I send with the units to note the requirement for at least 37V DC. Will update the product listing as well shortly.

let me know how the new switch works out and we can sort out hopefully the return of the second one.

scruloose, 2022-03-16:
Sure enough, once I got that switch set up and tried the coordinators on its PoE ports, I was able to verify that both of them power up and grab a DHCP lease within a few seconds, as expected.

I haven't yet set up an actual Zigbee network — there's a bit of a learning curve to get everything set up before I reach that point. The coordinators seem to be fine, though, so I'll try to get the second one mailed in the next day or two.

tube0013, 2022-03-16:
Awesome, good to hear!

Closed 2022-06-07.

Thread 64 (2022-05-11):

[SUGGESTION] RTC (Real-Time-Clock) and a clock-battery + a buzzer and RGB LED to the PCB board?

Hedda, 2022-05-11:
Maybe consider adding an RTC (Real-Time-Clock) and a clock-battery + a buzzer and tri-color RGB LED or LEDs if it would not add to much cost to Tube's gateways as products.

That way they could it would not only be a Zigbee Coordinator bridge or Zigbee Router but the ESPHome part could also serve multiple other purposes like for example an alarm-clock or doorbell-chime/buzzer with flashing lights in seperate colors to show/give status alerts for different things. See example these :

https://www.adafruit.com/product/5125

https://www.adafruit.com/product/5126

I read that the new “ITead SONOFF Zigbee Bridge Pro” in addition to having some kind of a "buzzer" so that it can be used as an alarm or a doorbell chime, and this new "Pro" variant also feature an onboard RTC (Real-Time-Clock) to keep time while offline-> https://github.com/arendst/Tasmota/discussions/14419

With both ESP32 and an RTC it would make it very suitable as a Zigbee2Tasmota gateway -> https://tasmota.github.io/docs/Zigbee/

Zigbee2Tasmota on an ESP32 based gateway RTC (Real-Time-Clock) and clock-battery could be used as a stand-alone offline gateway/hub to keep schemas and schedules for "Wake Up Alarm Clock" even when the internet goes down and it reboot, like when there is power blackout.

tube0013, 2022-05-11:
This is outside the scope of what I want to do / make. Users can add anything they'd like to the other pins of the esp32, however I can not support problems or issues that may occur.

Closed 2022-05-11.

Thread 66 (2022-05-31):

Coordinator unresponsive

kinselp, 2022-05-31:
Hi, have had my Poe coordinator running for months and in an attempt to fix an issue with Z2M I tried to flash it thru the webserver OTA update using the bin file.

Guessing I haven't showered myself in glory, as even though the update said successful it now doesn't seem to get an IP (have red and orange leds on, but no green).

What's the best way to check what's going on?  I'm guessing I've either flashed the wrong image or its failed mid flash - hoping a USB flash will get me back on track.

Appreciate any assistance.

tube0013, 2022-05-31:
DO you have the round PoE version? if so you'll want this bin file:

https://github.com/tube0013/tube_gateways/raw/main/tube_poe_coordinator/tube_zb_gw_cc2652p2_oliemex_poe.bin

I suggest flashing over USB, so remove PoE power, pop the coordinator lid, and you will likely need to undo the antenna retaining nut to full remove the PCB from the case. once removed you can use the micro USB connection to flash the bin.

ESPhome Flasher works well.

kinselp, 2022-06-04:
Coordinator back up - thanks @tube0013.  now to get Z2M working again!

tube0013, 2022-06-04:
Good to hear 👍

Closed 2022-06-04.

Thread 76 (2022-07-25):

CC2652P flashing fails

nerdinand, 2022-07-25:
Today I tried connecting the shiny new PoE-Coordinator to my Home Assistant instance. It got auto-discovered and I tried scanning for devices but couldn't find any. So I figured, let's do a firmware update (probably a dumb idea)...

I toggled "Prep the cc2652p2 for firmware update" and then ran:
```
$ python cc2538-bsl.py -p socket://tubeszb-cc2652-poe-2022.local:6638  -evw ~/Downloads/CC1352P2_CC2652P_launchpad_coordinator_20220219.hex
```
This seemed to do the right thing, until it didn't. After a while It failed with `ERROR: Timeout waiting for ACK/NACK`.

I have now tried numerous times to flash, everytime it fails with a similar error after a couple of seconds.
I also tried flashing via USB, with similar misfortune:

```
$ python cc2538-bsl.py -p /dev/tty.usbserial-1110 -evw ~/Downloads/CC1352P2_CC2652P_launchpad_coordinator_20220219.hex

Opening port /dev/tty.usbserial-1110, baud 500000
Reading data from /Users/ferdi/Downloads/CC1352P2_CC2652P_launchpad_coordinator_20220219.hex
Your firmware looks like an Intel Hex file
Connecting to target...
ERROR: Timeout waiting for ACK/NACK after 'Synch (0x55 0x55)'
```

Any ideas?

tube0013, 2022-07-25:
The Coordinator was flashed with the latest build of the Z-Stack FW when shipped.

as far as flashing, sometime you have to try multiple times. another option is to trigger the boot loader manually, to do this, pop the top with the device unpowered, hold down the BSL button while plugging in PoE, it's important to hold it for several seconds as the ESP32 will trigger a reset of the zigbee module after it boots.

To flash over USB you will need a USB Serial converter. the Onboard USB on the PoE module only talks to the ESP32 and is only good for flashing/debugging that.

Typically when devices can't join, it's due to interference. I'd suggest running a energy scan using the [zigpy-znp tools](https://github.com/zigpy/zigpy-znp/blob/dev/TOOLS.md) to see which channel has the least noise. After that you can do a NVRAM reset and then define the desired channel in HA/ZH configuration.yaml (see [zha docs](https://www.home-assistant.io/integrations/zha/#configuration---yaml))  and when zha starts up on a fresh radio it will form a new network on the new specified channel.

nerdinand, 2022-07-26:
Thanks for your input!

I finally managed to get the flashing through by moving my laptop and the coordinator closer together on the network (only a switch apart, no wifi involved).

However, now when I try to convince Home Assistant to connect to it, I get a "Failed to connect" everytime:

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

The tube_zb_gw_cc2652p2_poe Web Server is showing this:

```
[D][streamserver:085]: New client connected from 192.168.88.228
[D][streamserver:050]: Client 192.168.88.228 disconnected
```

Maybe related question: Which one of these is the right firmware for the Olimex board?

tube_zb_gw_cc2652p2_oliemex_poe.bin
tube_zb_gw_cc2652p2_(2021_04_08).bin
tube-zb-gw-cc2652p2-poe_olimex_round_latest.bin

Could it be that i flashed the wrong firmware on the Olimex board?

nerdinand, 2022-07-26:
Ah, I see. I did a successful OTA update with that one just now. However I still get the "Failed to connect" and sometimes "Unknown error" and the autodiscovery of home assistant doesn't discover it either... :(

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

I'll update my home assistant to the latest release now, but I don't think that'll help...

tube0013, 2022-07-26:
do you see any errors in the HA log? can you post them?

you can also try to manually set up the integrations and type in socket://ip:6638

nerdinand, 2022-07-26:
Finally got it to work! Not sure, what exactly changed this time around. I could imagine the reboot of Home Assistant because of the update did something. I was able to connect to 2 of my Hue devices with no problems and I'm able to control them! Thanks for your prompt help! Here's to no more problems... 🍻

tube0013, 2022-07-26:
Awesome. glad to hear!

Closed 2022-07-26.

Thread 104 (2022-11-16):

Power issue

astappiev, 2022-11-16:
Hi, first of all thank you for the great project.

I got mine CC2652P2 ethernet USB coordinator from ebay (b-ware) in Germany, but unfortunately it comes with a partially broken USB port (I think).

The issue is that after some time of work it turns off. After reconnecting or moving the USB it works again. There are no visible problems with the USB connector and of course I tried a bunch of different cables.

Is there any other easy way to power the board?
I see 3.3v, GND holes on the bottom left, are they input or output?

Thanks again!

tube0013, 2022-11-16:
There should be 3.3v and ground pins accessible which you could use as alternative power via a usb serial adapters power and ground pins.

Depending on condition of the pads for the usb port a cellphone repair shop or similar may be able to fix it.

astappiev, 2022-11-17:
Thank you for the quick reply, I will try to use the pins for power.
Will update with the results later

astappiev, 2022-12-27:
As you suggested, I looked for USB adapters I have, but the only thing I found was a battery charger like below. Which I ugly soldered to the very first transistor's pins near the USB port on the gateway.
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

But later replaced the MicroUSB port, which I ordered from Aliexpress ([a box with 10 different models](https://www.aliexpress.com/item/1005003311571316.html), one was similar). Likely all work now, including data pins :)

Closed 2022-12-27.

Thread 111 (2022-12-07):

ESP 32 Flash on tubeszb-cc2652-eth_usb + WT32-ETH01 flashing problem...

mcarbonneaux, 2022-12-07:
i've buy 2 tubesb cc2652 eth usb coordinator.
i've buy separatly 3 WT32-ETH01 (v1.4)

i followed the instructions : https://github.com/tube0013/tube_gateways/tree/main/models/current/tubeszb-cc2652-eth_usb#esp32-flashing

i switched the connector to usb esp32... click holded in the boot button...
i've installed the CH340 driver
the com port are found by windows (in device manager).
i've downloaded esphome-flasher (v1.4.0) 32bit and 64bit windows version.
i've downloaded the esp32 firmware : https://github.com/tube0013/tube_gateways/blob/main/models/current/tubeszb-cc2652-eth_usb/firmware/esphome/tube-zb-gw-cc2652p2-v2_2021_09_17.bin
but when i try to flash... i take an error:
```
Using 'COM5' as serial port.
Connecting......................................
Unexpected error: ESP Chip Auto-Detection failed: Failed to connect to Espressif device: No serial data received.
For troubleshooting steps visit: https://github.com/espressif/esptool#troubleshooting
```
when i click on logs:
```
Using 'COM5' as serial port.
Unexpected error: could not open port 'COM5': PermissionError(13, 'Accès refusé.', None, 5)
```

i've tried to change my cable by another one.... the same...

i'm on Windows 10 22H2 (i'm on ryzen 5 2600 + gigabyte mb B450)...
the version of the driver CH340 : 3.5.2019.1

tube0013, 2022-12-07:
are you holding the EBOOT button down when plugging in the device to flash? (you can also hold it and tap the ERST button to reset the esp32 into bootloader mode).

tube0013, 2022-12-07:
did the boards work with zigbee over usb without issue?

mcarbonneaux, 2022-12-07:
erst tryed and not permit to flash...

" zigbee over usb " how to try that ?

tube0013, 2022-12-07:
hook up to home assistant server with usb cable?

do the wt32-eth01 modules light up when plugged into USB? you should see a red LED.

mcarbonneaux, 2022-12-07:
ok i've done that : press and hold RESET, press BOOT, release Reset and then release BOOT,
and flash are gooing !

mcarbonneaux, 2022-12-07:
```
Auto-detected serial port: COM5
Connecting....

Chip Info:
 - Chip Family: ESP32
 - Chip Model: ESP32D0WDQ5 (revision 1)
 - Number of Cores: 2
 - Max CPU Frequency: 240MHz
 - Has Bluetooth: YES
 - Has Embedded Flash: NO
 - Has Factory-Calibrated ADC: YES
 - MAC Address: xx:xx:xx:xx:xx:xx:xx
Uploading stub...
Running stub...
Stub running...
Changing baud rate to 460800
Changed.
 - Flash Size: 4MB
 - Flash Mode: dio
 - Flash Frequency: 40MHz
Erasing flash (this may take a while)...
Chip erase completed successfully in 13.1s
Compressed 15872 bytes to 10319...
Wrote 15872 bytes (10319 compressed) at 0x00001000 in 0.3 seconds (effective 501.1 kbit/s)...
Hash of data verified.
Compressed 3072 bytes to 144...
Wrote 3072 bytes (144 compressed) at 0x00008000 in 0.0 seconds (effective 3619.4 kbit/s)...
Hash of data verified.
Compressed 8192 bytes to 47...
Wrote 8192 bytes (47 compressed) at 0x0000e000 in 0.0 seconds (effective 16381.3 kbit/s)...
Hash of data verified.
Compressed 924768 bytes to 524202...
Wrote 924768 bytes (524202 compressed) at 0x00010000 in 13.5 seconds (effective 547.0 kbit/s)...
Hash of data verified.

Leaving...
Hard Resetting...
Done! Flashing is complete!
```

mcarbonneaux, 2022-12-07:
is needed to flash also the ti part (CC2652) or is pre flashed?

tube0013, 2022-12-07:
The cc2652 is pre-flashed.

mcarbonneaux, 2022-12-07:
> erst tryed and not permit to flash...
>
> " zigbee over usb " how to try that ?

ok is to use the coordinator usb zigbee dongle for z2m or zha ?!

tube0013, 2022-12-07:
you can go straight to ethernet now if you have the wt32-eth01 flashed and installed.

guides are on the site and z2m has docs for setting up a network connected coordinator (skip to step 3 on that page).

mcarbonneaux, 2022-12-08:
i while test that tomorow ! :)

Closed 2022-12-07.

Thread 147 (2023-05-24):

[CC2652P2 ETH/USB] Error : Failed to connect to the adapter

shad-lp, 2023-05-24:
Hello,

For some weeks now I'm having problems with my CC2652P2 ETH/USB controller.
The serial connection goes off some minutes after I restart the device :

```
Using '/app/data' as data directory
Zigbee2MQTT:info  2023-05-24 21:39:49: Logging to console and directory: '/app/data/log/2023-05-24.21-39-49' filename: log.txt
Zigbee2MQTT:info  2023-05-24 21:39:49: Starting Zigbee2MQTT version 1.30.3 (commit #24c6b2e)
Zigbee2MQTT:info  2023-05-24 21:39:49: Starting zigbee-herdsman (0.14.103)
Zigbee2MQTT:info  2023-05-24 21:39:53: zigbee-herdsman started (resumed)
Zigbee2MQTT:info  2023-05-24 21:39:53: Coordinator firmware version: '{"meta":{"maintrel":1,"majorrel":2,"minorrel":7,"product":1,"revision":20220219,"transportrev":2},"type":"zStack3x0"}'
Zigbee2MQTT:info  2023-05-24 21:39:53: Currently 2 devices are joined:
Zigbee2MQTT:info  2023-05-24 21:39:53: AQ-SDB (0x00158d0008c11fd8): WSDCGQ11LM - Xiaomi Aqara temperature, humidity and pressure sensor (EndDevice)
Zigbee2MQTT:info  2023-05-24 21:39:53: AQ-CHP (0x00158d000910b4ed): WSDCGQ11LM - Xiaomi Aqara temperature, humidity and pressure sensor (EndDevice)
Zigbee2MQTT:warn  2023-05-24 21:39:53: `permit_join` set to  `true` in configuration.yaml.
Zigbee2MQTT:warn  2023-05-24 21:39:53: Allowing new devices to join.
Zigbee2MQTT:warn  2023-05-24 21:39:53: Set `permit_join` to `false` once you joined all devices.
Zigbee2MQTT:info  2023-05-24 21:39:53: Zigbee: allowing new devices to join.
Zigbee2MQTT:info  2023-05-24 21:39:53: Connecting to MQTT server at mqtt://ida.aelnas.ovh:1883
Zigbee2MQTT:info  2023-05-24 21:39:53: Connected to MQTT server
Zigbee2MQTT:info  2023-05-24 21:39:53: MQTT publish: topic 'zigbee2mqtt/bridge/state', payload '{"state":"online"}'
Zigbee2MQTT:info  2023-05-24 21:39:53: Started frontend on port 0.0.0.0:8080
Zigbee2MQTT:info  2023-05-24 21:39:54: MQTT publish: topic 'zigbee2mqtt/AQ-SDB', payload '{"battery":97,"humidity":75.53,"linkquality":65,"power_outage_count":7,"pressure":1012.9,"temperature":20.6,"voltage":2995}'
Zigbee2MQTT:info  2023-05-24 21:39:54: MQTT publish: topic 'zigbee2mqtt/AQ-CHP', payload '{"battery":90,"humidity":46.52,"linkquality":112,"power_outage_count":6,"pressure":1012.3,"temperature":20.6,"voltage":2985}'
Zigbee2MQTT:info  2023-05-24 21:39:54: Zigbee2MQTT started!
Error: SRSP - ZDO - mgmtPermitJoinReq after 6000ms
    at Timeout._onTimeout (/app/node_modules/zigbee-herdsman/src/utils/waitress.ts:64:35)
    at listOnTimeout (node:internal/timers:569:17)
    at processTimers (node:internal/timers:512:7)
Using '/app/data' as data directory
Zigbee2MQTT:info  2023-05-24 21:43:24: Logging to console and directory: '/app/data/log/2023-05-24.21-43-24' filename: log.txt
Zigbee2MQTT:info  2023-05-24 21:43:24: Starting Zigbee2MQTT version 1.30.3 (commit #24c6b2e)
Zigbee2MQTT:info  2023-05-24 21:43:24: Starting zigbee-herdsman (0.14.103)
Zigbee2MQTT:error 2023-05-24 21:43:44: Error while starting zigbee-herdsman
Zigbee2MQTT:error 2023-05-24 21:43:44: Failed to start zigbee
Zigbee2MQTT:error 2023-05-24 21:43:44: Check https://www.zigbee2mqtt.io/guide/installation/20_zigbee2mqtt-fails-to-start.html for possible solutions
Zigbee2MQTT:error 2023-05-24 21:43:44: Exiting...
Zigbee2MQTT:error 2023-05-24 21:43:44: Error: Failed to connect to the adapter (Error: SRSP - SYS - ping after 6000ms)
    at ZStackAdapter.start (/app/node_modules/zigbee-herdsman/src/adapter/z-stack/adapter/zStackAdapter.ts:103:27)
    at Controller.start (/app/node_modules/zigbee-herdsman/src/controller/controller.ts:132:29)
    at Zigbee.start (/app/lib/zigbee.ts:58:27)
    at Controller.start (/app/lib/controller.ts:101:27)
    at start (/app/index.js:107:5)
```

And so on, looping indefinitely.

In the mean time, on the TubeZB interface :

```
21:50:21 | [I] | [restart.button:012] | Restarting device...
-- | -- | -- | --
21:50:21 | [I] | [restart.button:012] | Restarting device...
21:50:21 | [I] | [app:134] | Rebooting safely...
21:51:47 | [D] | [streamserver:102] | Client 192.168.100.222 disconnected
21:51:47 | [D] | [binary_sensor:036] | 'TubesZB Serial Connected': Sending state OFF
21:51:52 | [D] | [streamserver:074] | New client connected from 192.168.100.222
21:51:52 | [D] | [binary_sensor:036] | 'TubesZB Serial Connected': Sending state ON
21:52:11 | [D] | [streamserver:102] | Client 192.168.100.222 disconnected
21:52:11 | [D] | [binary_sensor:036] | 'TubesZB Serial Connected': Sending state OFF
21:52:17 | [D] | [streamserver:074] | New client connected from 192.168.100.222
21:52:17 | [D] | [binary_sensor:036] | 'TubesZB Serial Connected': Sending state ON
```

Sometimes it stays online for a while, but definitely can't be reached from z2m few minutes later.

Everything was running smooth for the last months.
I have not yet upgraded the firmware (can't find the version I'm using right now, where should I check ?).
I have downgraded z2m version to 1.30.2, but same behaviour, so I guess it's not related to z2m.

The coordinator answers to ping, even while the state is set to OFF.

Thanks in advance.

tube0013, 2023-05-24:
please see the troubleshooting guide here:

https://github.com/tube0013/tube_gateways/blob/main/Troubleshooting.md

shad-lp, 2023-05-24:
Thanks for the quick answer :

- I had to install pyserial and intelhex package from pip3
- Run the script :

```
./cc2538-bsl.py -p socket://tubezb.xxxxxx.ovh:6638 -evw ./CC1352P2_CC2652P_launchpad_coordinator_20221226.hex
Opening port socket://tubezb.xxxxxx.ovh:6638, baud 500000
Reading data from ./CC1352P2_CC2652P_launchpad_coordinator_20221226.hex
Your firmware looks like an Intel Hex file
Connecting to target...
CC1350 PG2.0 (7x7mm): 352KB Flash, 20KB SRAM, CCFG.BL_CONFIG at 0x00057FD8
Primary IEEE Address: 00:12:4B:00:2A:2E:C8:C6
    Performing mass erase
Erasing all main bank flash sectors
    Erase done
Writing 360448 bytes starting at address 0x00000000
Write 104 bytes at 0x00057F980
    Write done
Verifying by comparing CRC32 calculations.
    Verified (match: 0xa9dc145d)
```

After 2 minutes, I rebooted the device and started zigbee2mqtt again.
This time, no more state on/off loop.

So far, so good, z2m started successfully :

```
Using '/app/data' as data directory
Zigbee2MQTT:info  2023-05-24 22:33:36: Logging to console and directory: '/app/data/log/2023-05-24.22-33-36' filename: log.txt
Zigbee2MQTT:info  2023-05-24 22:33:36: Starting Zigbee2MQTT version 1.30.4 (commit #b2dd21e)
Zigbee2MQTT:info  2023-05-24 22:33:36: Starting zigbee-herdsman (0.14.111)
Zigbee2MQTT:info  2023-05-24 22:36:40: zigbee-herdsman started (restored)
Zigbee2MQTT:info  2023-05-24 22:36:40: Coordinator firmware version: '{"meta":{"maintrel":1,"majorrel":2,"minorrel":7,"product":1,"revision":20221226,"transportrev":2},"type":"zStack3x0"}'
Zigbee2MQTT:info  2023-05-24 22:36:40: Currently 2 devices are joined:
Zigbee2MQTT:info  2023-05-24 22:36:40: AQ-SDB (0x00158d0008c11fd8): WSDCGQ11LM - Xiaomi Aqara temperature, humidity and pressure sensor (EndDevice)
Zigbee2MQTT:info  2023-05-24 22:36:40: AQ-CHP (0x00158d000910b4ed): WSDCGQ11LM - Xiaomi Aqara temperature, humidity and pressure sensor (EndDevice)
Zigbee2MQTT:warn  2023-05-24 22:36:40: `permit_join` set to  `true` in configuration.yaml.
Zigbee2MQTT:warn  2023-05-24 22:36:40: Allowing new devices to join.
Zigbee2MQTT:warn  2023-05-24 22:36:40: Set `permit_join` to `false` once you joined all devices.
Zigbee2MQTT:info  2023-05-24 22:36:40: Zigbee: allowing new devices to join.
Zigbee2MQTT:info  2023-05-24 22:36:40: Connecting to MQTT server at mqtt://ida.aelnas.ovh:1883
Zigbee2MQTT:info  2023-05-24 22:36:41: Connected to MQTT server
Zigbee2MQTT:info  2023-05-24 22:36:41: MQTT publish: topic 'zigbee2mqtt/bridge/state', payload '{"state":"online"}'
Zigbee2MQTT:info  2023-05-24 22:36:41: Started frontend on port 0.0.0.0:8080
Zigbee2MQTT:info  2023-05-24 22:36:41: MQTT publish: topic 'zigbee2mqtt/AQ-SDB', payload '{"battery":97,"humidity":75.53,"linkquality":65,"power_outage_count":7,"pressure":1012.9,"temperature":20.6,"voltage":2995}'
Zigbee2MQTT:info  2023-05-24 22:36:41: MQTT publish: topic 'zigbee2mqtt/AQ-CHP', payload '{"battery":90,"humidity":46.52,"linkquality":112,"power_outage_count":6,"pressure":1012.3,"temperature":20.6,"voltage":2985}'
Zigbee2MQTT:info  2023-05-24 22:36:41: Zigbee2MQTT started!
```

I'll monitor the logs for the next days, thanks again for the prompt answer.

Closed 2023-05-24.

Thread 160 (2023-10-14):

Unable to create ZHA Network with EFR32-MGM210-POE-2023 with HA 2023.10.X

VonJedi, 2023-10-14:
Not sure if I'm doing or done something wrong here.

I plugged in the device with PoE and it's powered up okay, I can get to the web interface, I attempted to set up the ZHA and it seems to hang on the 'Create a Network' page, then just says 'Error' and an okay button.
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

Shows this in the web interface for the device:
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

I get this in the error logs of HA.
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

Not sure what I'm doing wrong, I updated the firmware on the device using the micro usb, and updated HA to the latest version (2023.11). Still doing it.

Any ideas?

tube0013, 2023-10-14:
Are you using HASOS - with add-ons? if yes can you try using my addon for firmware updates and try re-flashing the zigbee module.

https://github.com/tube0013/tubeszb_addons/blob/main/tzb-silabs-flasher/DOCS.md

the URL for the firmware file is:

https://github.com/tube0013/tube_gateways/raw/main/models/current/tubeszb-efr32-MGM210-poe/firmware/efr32_MGM210/ncp/7.2.3/MGM21_2022_ncp-uart-7.2.3.gbl

Software flow

after you start the login check and refresh the logs, if it fails, let me know what the logs say.

thanks.

VonJedi, 2023-10-14:
Hey mate,

No errors, seemed to flash fine.

Still having the same issue though. So strange.

tube0013, 2023-10-14:
Please enable debug logging for zha as per the zha component docs, adding the lines to configuration.yaml. Restart HA, and go through trying to set up zha again. After the failure upload the log - or email to me at store@tubeszb.com hopefully can figure this out.

If the flash worked with no errors, the flashing script was able to speak to the coordinator via ezsp to put it into bootloader mode then successfully send the fw, so I'm hoping the debug logging will give some insight into why zha is failing setup.

Are you doing manual setup up or going through the discovered device flow?

Thanks

revulsion, 2023-10-14:
I am also having this exact problem.  if you still need logs, please let me know

tube0013, 2023-10-14:
Are you setting up manually or via the auto discovered device?

revulsion, 2023-10-14:
Manually.

revulsion, 2023-10-14:
Manual

I am probably making things overly complicated as I have:
1. HA is running in Kubernetes via the official home-assistant :latest container image
2. My "iot" devices get their own subnet (routing works and other devices are work, eg an rtsp camera)

tube0013, 2023-10-14:
Can you pull the debug logs when trying to add?

I'm going to try and replicate shorty in a test environment to see if something is up with current HA

revulsion, 2023-10-14:
[logs-2.txt](https://github.com/tube0013/tube_gateways/files/12908247/logs-2.txt)

tube0013, 2023-10-15:
Okay I was able to replicate this. It seems to be with the latest HA release and backend libs.

as a work around you can roll back to 2023.9.3 and set it up, and then re-update to 2023.10.3, I've confirmed this works.

Working with the ZHA dev to identify the issue.

tube0013, 2023-10-15:
pretty sure it's from this. https://github.com/zigpy/bellows/pull/584

revulsion, 2023-10-15:
Yes, rolling back to 2023.9.3 allowed me to add it.

VonJedi, 2023-10-15:
Yeah that's done it. Perfect. Thanks mate.

tube0013, 2023-11-05:
Confirmed network formation works in the 2023.11.x releases. So closing this.

If anyone comes to this issue and is running 2023.10.x the solution is to downgrade to 2023.9.x  set up ZHA then upgrade back to 2023.10.x or just upgrade to 2023.11.x or greater and all should be okay.

LordNex, 2023-11-05:
Question, does that mean it's safe to let ESPHome update the coordinator now?  It seems after adoption that it's just a small snippet of code pointing to your yaml file. Just wondering as ESPHome is still at version 10.6 in HA 11.1

tube0013, 2023-11-05:
Please don't comment on closed issues unless it is related to the closed issue.

You can update the ESPHome fw at your own risk, the fw depends on external components that could break with an update at anytime. You can always roll back with the provided binary provided here.

Closed 2023-11-05.

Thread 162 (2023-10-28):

Unable to update firmware on EFR32 MGM21 Ethernet/USB

davidrule1969, 2023-10-28:
I just received a new EFR32 MGM21 Ethernet/USB device.  When I first tried powering it up, I got no LEDs on the ethernet module or the main PCB.  I popped off the cover and noticed that the ethernet module was installed incorrectly, the pins were offset by one.  I don't know if powering the unit up in this state has caused a problem or not.  Anyway, I disconnected the ethernet module and reconnected it in the correct position and I get LEDs and everything seems ok, except I cannot get ZHA or Zigbee2MQTT to recognise it.

Zigbee2MQTT gives me this error:

`Zigbee2MQTT:error 2022-10-14 23:42:17: Error: Failed to connect to the adapter (Error: SRSP - SYS - ping after 6000ms)
    at ZStackAdapter.start (/app/node_modules/zigbee-herdsman/src/adapter/z-stack/adapter/zStackAdapter.ts:103:27)
    at Controller.start (/app/node_modules/zigbee-herdsman/src/controller/controller.ts:132:29)
    at Zigbee.start (/app/lib/zigbee.ts:58:27)
    at Controller.start (/app/lib/controller.ts:101:27)
    at start (/app/index.js:109:5)`

ZHA gives a blank dialog box with the title ERROR.

The ESPHome interface is working fine.  However, I refreshed it anyway as some other postings here suggested I do so.  No problems there, ESPHome is still working.

So I thought I'd try updating the firmware on the EFR32.  This seems to have made things even worse!

I followed the YouTube video here: https://www.youtube.com/watch?v=zKrISuWEzL4

After uploading the gbl file (I'm using 20230219_MGM12ncp-uart-sw_7.2.1_2022.gbl) with XMODEM, the serial connection doesn't seem to recognise the end of the upload.  It just sits there at CCCC.

Now when I reset the EFR32, regardless of whether the Bootloader pin is set to Low or High, it always returns to the menu and I never get the '~' to indicate that it is running.

`Gecko Bootloader v2.01.01
1. upload gbl
2. run
3. ebl info
BL >`

Any help gratefully appreciated!
-David

tube0013, 2023-10-28:
Hi, sorry about the mis-aligned esp32 module!

ZHA has a bug in the current 2023.10.x version for setting up network connected coordinators. It will work in 2023.9.x if you downgrade once set up you can re update to 2023.10.x. Alternatively you can update to the 2023.11 beta and it should work there as well.

For z2m you if you choose to go that way despite the warnings with a efr32 coordinator being experimental. You have to make sure under the port line you tell it ezsp otherwise it assumes a TI adaptor which is why you see the error you got.

davidrule1969, 2023-10-28:
Thanks for the prompt response!

I updated to 2023.11 beta and now ZHA says "Failed to connect".  I suspect this is because I messed up the EFR32 firmware.  How can I recover this?

Connecting via serial I always get the bootloader menu

`Gecko Bootloader v2.01.01`
`  1. upload gbl`
`  2. run`
`  3. ebl info`

I no longer get the ~ prompt regardless of the state of the Bootloader pin.

tube0013, 2023-10-28:
Are you using HASOS with addons?

if so you can use the addon I have here:

https://github.com/tube0013/tubeszb_addons/blob/main/tzb-silabs-flasher/DOCS.md

the Firmware link to use is:
https://github.com/tube0013/tube_gateways/raw/main/models/current/tubeszb-efr32-MGM210-poe/firmware/efr32_MGM210/ncp/7.2.3/MGM21_2022_ncp-uart-7.2.3.gbl

if not using hasos you can download the the firmware linked above and use the universal-siliconlabs-flasher from nabu casa:

https://github.com/NabuCasa/universal-silabs-flasher

the command you'd want to use is:

`$ universal-silabs-flasher --probe-method bootloader --device socket://IP_ADDRESS:6638  flash --firmware MGM21_2022_ncp-uart-7.2.3.gbl `

davidrule1969, 2023-10-28:
OK, thanks.  That was it.  I was using the wrong .gbl file.  ~ prompt restored and ZHA is now seeing the device! :-)

Now to start playing with experimental zigbee2mqtt :-D

Thanks again for the help.

LordNex, 2023-10-31:
Along those lines will we be seeing a new version soon? I didnt know about the 10/X bug but I havent let ESPHome write to it yet, although the yaml file looks like it just repoints it to your code. Its mostly just annoying as i like to try and keep everything's at the updated stable version,

LordNex, 2023-11-04:
Is it safe to let ESPHome to update the coordinator now that HA11 is out?

mtnbiker717, 2023-11-09:
> For z2m you if you choose to go that way despite the warnings with a efr32 coordinator being experimental. You have to make sure under the port line you tell it ezsp otherwise it assumes a TI adaptor which is why you see the error you got.

What issues are they seeing with Z2M?

Closed 2024-03-20.

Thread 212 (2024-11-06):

Unable To Update Firmware

D3v01dZA, 2024-11-06:
To start I'm not some ESP wizard and have no idea of how it works and I'm pretty sure whatever the mistake is I'm making is simple and obvious but I've now given up.

I have this adapter https://tubeszb.com/product/efr32-mgm24-poe-coordinator/. I am currently unable to update it and I cannot work out why, I am using the firmwares from https://github.com/tube0013/tube_gateways/tree/main/models/current/tubeszb-efr32-MGM24/firmware/mgm24/ncp. Specifically I wanted to try ```tubesZB-EFR32-MGM24_NCP_7.4.3.gbl```.

I've tried a couple different methods from https://www.youtube.com/watch?v=zKrISuWEzL4 to https://github.com/NabuCasa/universal-silabs-flasher/tree/dev/universal_silabs_flasher - I run a docker based HASS so the add on is a bit painful but looking at the code it just delegates to this.

When I tried https://www.youtube.com/watch?v=zKrISuWEzL4 everything "looks" normal and I see the little ~ and everything, then when I try to start Zigbee2MQTT it still fails with ```2024-11-06 16:13:30] error: 	z2m: Error: Adapter EZSP protocol version (11) is not supported by Host [13-14].```. It's very unclear where anything is failing or how the firmware is actually written, and there are no errors/output during any steps.

When trying universal_silabs_flasher the same story mostly, no errors, sometimes flash uploads and does nothing, sometimes it spews out "No Firmware"

Probe output - this is the same output no matter what I do, post firmware "upgrade" etc.
```
└─(15:58:47)──> universal-silabs-flasher --device socket://zigbee.lan:6638 probe                                                                                                                                                                                                                                                                                         
2024-11-06 15:58:54.030 Chris-MacBook.local universal_silabs_flasher.flasher INFO Probing ApplicationType.GECKO_BOOTLOADER at 115200 baud
2024-11-06 15:58:56.049 Chris-MacBook.local universal_silabs_flasher.flasher INFO Probing ApplicationType.CPC at 460800 baud
2024-11-06 15:59:00.381 Chris-MacBook.local universal_silabs_flasher.flasher INFO Probing ApplicationType.CPC at 115200 baud
2024-11-06 15:59:04.704 Chris-MacBook.local universal_silabs_flasher.flasher INFO Probing ApplicationType.CPC at 230400 baud
2024-11-06 15:59:09.083 Chris-MacBook.local universal_silabs_flasher.flasher INFO Probing ApplicationType.EZSP at 115200 baud
2024-11-06 15:34:42.372 Chris-MacBook.local universal_silabs_flasher.flasher INFO Detected ApplicationType.EZSP, version '7.2.3.0 build 215' (7.2.3.0.215) at 115200 baudrate (bootloader baudrate None)
2024-11-06 15:34:42.372 Chris-MacBook.local universal_silabs_flasher.flash INFO Dumping EmberZNet Config
CONFIG_PACKET_BUFFER_COUNT=255
CONFIG_NEIGHBOR_TABLE_SIZE=26
...
```

Playhing with the bootloader pin I sometimes get
```
└─(16:04:35)──> universal-silabs-flasher --probe-method bootloader --device socket://zigbee.lan:6638 flash --firmware tubesZB-EFR32-MGM24_NCP_7.4.3.gbl                                                                                                                                                                                                                           1 ↵ ──(Wed,Nov06)─┘
2024-11-06 16:04:39.993 Chris-MacBook.local universal_silabs_flasher.flash INFO Extracted GBL metadata: NabuCasaMetadata(metadata_version=1, sdk_version='4.4.3', ezsp_version='7.4.2.0', ot_rcp_version=None, cpc_version=None, fw_type=<FirmwareImageType.NCP_UART_HW: 'ncp-uart-hw'>, baudrate=115200)
2024-11-06 16:04:39.993 Chris-MacBook.local universal_silabs_flasher.flasher INFO Probing ApplicationType.GECKO_BOOTLOADER at 115200 baud
2024-11-06 16:04:41.050 Chris-MacBook.local universal_silabs_flasher.flasher INFO Detected bootloader version '2.1.1'
2024-11-06 16:04:41.051 Chris-MacBook.local universal_silabs_flasher.flasher INFO Detected ApplicationType.GECKO_BOOTLOADER, version '2.1.1' at 115200 baudrate (bootloader baudrate 115200)
tubesZB-EFR32-MGM24_NCP_7.4.3.gbl  [####################################]  100%
Traceback (most recent call last):
  File "/Users/christopheraltona/.asdf/installs/python/3.12.2/bin/universal-silabs-flasher", line 8, in <module>
    sys.exit(main())
             ^^^^^^
  File "/Users/christopheraltona/.asdf/installs/python/3.12.2/lib/python3.12/site-packages/click/core.py", line 1157, in __call__
    return self.main(*args, **kwargs)
           ^^^^^^^^^^^^^^^^^^^^^^^^^^
  File "/Users/christopheraltona/.asdf/installs/python/3.12.2/lib/python3.12/site-packages/click/core.py", line 1078, in main
    rv = self.invoke(ctx)
         ^^^^^^^^^^^^^^^^
  File "/Users/christopheraltona/.asdf/installs/python/3.12.2/lib/python3.12/site-packages/click/core.py", line 1688, in invoke
    return _process_result(sub_ctx.command.invoke(sub_ctx))
                           ^^^^^^^^^^^^^^^^^^^^^^^^^^^^^^^
  File "/Users/christopheraltona/.asdf/installs/python/3.12.2/lib/python3.12/site-packages/click/core.py", line 1434, in invoke
    return ctx.invoke(self.callback, **ctx.params)
           ^^^^^^^^^^^^^^^^^^^^^^^^^^^^^^^^^^^^^^^
  File "/Users/christopheraltona/.asdf/installs/python/3.12.2/lib/python3.12/site-packages/click/core.py", line 783, in invoke
    return __callback(*args, **kwargs)
           ^^^^^^^^^^^^^^^^^^^^^^^^^^^
  File "/Users/christopheraltona/.asdf/installs/python/3.12.2/lib/python3.12/site-packages/click/decorators.py", line 33, in new_func
    return f(get_current_context(), *args, **kwargs)
           ^^^^^^^^^^^^^^^^^^^^^^^^^^^^^^^^^^^^^^^^^
  File "/Users/christopheraltona/.asdf/installs/python/3.12.2/lib/python3.12/site-packages/universal_silabs_flasher/flash.py", line 40, in inner
    return asyncio.run(f(*args, **kwargs))
           ^^^^^^^^^^^^^^^^^^^^^^^^^^^^^^^
  File "/Users/christopheraltona/.asdf/installs/python/3.12.2/lib/python3.12/asyncio/runners.py", line 194, in run
    return runner.run(main)
           ^^^^^^^^^^^^^^^^
  File "/Users/christopheraltona/.asdf/installs/python/3.12.2/lib/python3.12/asyncio/runners.py", line 118, in run
    return self._loop.run_until_complete(task)
           ^^^^^^^^^^^^^^^^^^^^^^^^^^^^^^^^^^^
  File "/Users/christopheraltona/.asdf/installs/python/3.12.2/lib/python3.12/asyncio/base_events.py", line 685, in run_until_complete
    return future.result()
           ^^^^^^^^^^^^^^^
  File "/Users/christopheraltona/.asdf/installs/python/3.12.2/lib/python3.12/site-packages/universal_silabs_flasher/flash.py", line 423, in flash
    await flasher.flash_firmware(
  File "/Users/christopheraltona/.asdf/installs/python/3.12.2/lib/python3.12/site-packages/universal_silabs_flasher/flasher.py", line 299, in flash_firmware
    await gecko.run_firmware()
  File "/Users/christopheraltona/.asdf/installs/python/3.12.2/lib/python3.12/site-packages/universal_silabs_flasher/gecko_bootloader.py", line 101, in run_firmware
    raise NoFirmwareError("No firmware exists on the device")
universal_silabs_flasher.gecko_bootloader.NoFirmwareError: No firmware exists on the device
```

But mostly I get something that looks "successful" but the probe output and zigbee2MQTT error remains the same.

```
└─(15:00:54)──> universal-silabs-flasher --device socket://zigbee.lan:6638 flash --firmware tubesZB-EFR32-MGM24_NCP_7.4.3.gbl
2024-11-06 15:01:13.851 Chris-MacBook.local universal_silabs_flasher.flash INFO Extracted GBL metadata: NabuCasaMetadata(metadata_version=1, sdk_version='4.4.3', ezsp_version='7.4.2.0', ot_rcp_version=None, cpc_version=None, fw_type=<FirmwareImageType.ZIGBEE_NCP: 'zigbee_ncp'>, fw_variant=None, baudrate=115200)
2024-11-06 15:01:13.851 Chris-MacBook.local universal_silabs_flasher.flasher INFO Probing ApplicationType.GECKO_BOOTLOADER at 115200 baud
2024-11-06 15:01:13.907 Chris-MacBook.local universal_silabs_flasher.flasher INFO Detected bootloader version '2.1.1'
2024-11-06 15:01:13.907 Chris-MacBook.local universal_silabs_flasher.flasher INFO Detected ApplicationType.GECKO_BOOTLOADER, version '2.1.1' at 115200 baudrate (bootloader baudrate 115200)
tubesZB-EFR32-MGM24_NCP_7.4.3.gbl  [####################################]  100%
```

D3v01dZA, 2024-11-06:
Bellows thinks I'm still on 7.2. I am actually trying to migrate from ZHA to Z2MQTT. I had both containers down while I was working on this, could confirm on the sticks webpage where it showed 0 active connections and serial not connected.

After the upload using Serial it took a little bit to show the ~ but it was quicker than the upload. The universal-silabs-flasher just returns quickly after the upload.

Using Serial I followed your YouTube exactly (although that was a different controller). Am I supposed to pull the boot loader pin for this flasher to work? I'm a bit stumped :)

```
└─(17:47:48)──> bellows --baudrate 115200 -d socket://zigbee.lan:6638 info
[00:21:2e:ff:ff:09:4b:93]
[0x0000]
[<EmberNetworkStatus.JOINED_NETWORK: 2>]
[<EmberStatus.SUCCESS: 0>, <EmberNodeType.COORDINATOR: 1>, EmberNetworkParameters(extendedPanId=74:94:a3:5c:14:9c:f1:2b, panId=0xE7D7, radioTxPower=8, radioChannel=20, joinMethod=<EmberJoinMethod.USE_MAC_ASSOCIATION: 0>, nwkManagerId=0x0000, nwkUpdateId=0, channels=<Channels.ALL_CHANNELS: 134215680>)]
[<EmberStatus.SUCCESS: 0>, EmberCurrentSecurityState(bitmask=<EmberCurrentSecurityBitmask.GLOBAL_LINK_KEY|HAVE_TRUST_CENTER_LINK_KEY|TRUST_CENTER_USES_HASHED_LINK_KEY|96: 244>, trustCenterLongAddress=00:21:2e:ff:ff:09:4b:93)]
Manufacturer: TubesZB
Board name: Series 2
EmberZNet version: 7.2.3.0 build 215
```

tube0013, 2024-11-06:
as long as there is a working ezsp firmware on the device, the universal-silabs-flasher should be able to put the device into bootloader mode with ezsp commands with you not having to do anything else.

I have been running and now recommend this FW:
https://github.com/tube0013/tube_gateways/tree/main/models/current/tubeszb-efr32-MGM24/firmware/mgm24/ncp/4.4.4

can you try and run:

`universal-silabs-flasher -vv --device socket://zigbee.lan:6638 --bootloader-baudrate 115200 --ezsp-baudrate 115200 flash --firmware ./tubeszb-mgm24-hw-max_ncp-uart-hw_7.4.4.0.gbl --force`

D3v01dZA, 2024-11-06:
I would prefer not to brick my device, can --force do something weird? (Speaking from a little bit of experience with --force equivalents that made me sad :()

tube0013, 2024-11-06:
Then just leave that off. I use it so I can flash different builds of the same fw version

D3v01dZA, 2024-11-06:
Didn't see to take again. Killed my ZHA - checked 0 connections on the web page as well as no serial user. I waited a good 5 minutes after typing this original draft then ran bellows again.
```
universal-silabs-flasher -vv --device socket://zigbee.lan:6638 --bootloader-baudrate 115200 --ezsp-baudrate 115200 flash --firmware ./tubeszb-mgm24-hw-max_ncp-uart-hw_7.4.4.0.gbl
```
[Attached Logs](https://github.com/user-attachments/files/17654211/upload.log)
```
bellows --baudrate 115200 -d socket://zigbee.lan:6638 info
```

tube0013, 2024-11-07:
are you 100% confident you have an mgm24? the board name shown is not what I program on the mgm24 modules, that is what I put on the mgm21 modules.

can you take a picture of the module so I can confirm? or do you see a ceramic antenna on the the board? if so it's a mgm21. and it is likely rejecting the fw for that reason.

D3v01dZA, 2024-11-07:
>I'm pretty sure whatever the mistake is I'm making is simple and obvious

Remember when I said this? That is the mistake. I am not exactly sure _how_ I thought I had the MGM24 but a search in my inbox initially showed that - I rechecked now and it is indeed an MGM21 :)

The flash went smoothly once I downloaded the right firmware!

Closed 2024-11-07.

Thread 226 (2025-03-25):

Power Cycle ZWave via ESPHome

VACIndustries, 2025-03-25:
Is there a way to power cycle the ZWave (in my case Zooz) via the POE ESPHome?

VACIndustries, 2025-03-25:
Ahh okay so restarting the ESP32 will restart the Zooz module as well?

VACIndustries, 2025-03-25:
Ahh gotcha; so it would have to be either cycling the entire POE device (if powered via POE) or soft resetting the module via ZWave direct.  Good to know.  Thanks @tube0013 !

Closed 2025-03-25.

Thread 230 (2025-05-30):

Dual Radio can only use One device at a time.

phantomdez, 2025-05-30:
Maybe I am missing something but I just purchased the tubeszb-dual-radio-kit-mgm24 and purchased a Zooz 800 Series Z-Wave Long Range GPIO Module ZAC93 LR.  In Home Assistant when I connect Z2M to tcp://IP:6638 the connection works fine.  in Z-WAVE JS UI It won't connect to tcp://IP:6639.  If I shutdown Z2M then Z-WAVE JS connects.  Am I missing something in terms of the setup?  Is this expected usage?  My impression was that this would serve both protocols simultaneously.  Any guidance is appreciated.

[zwave.log](https://github.com/user-attachments/files/20526257/zwave.log)
[z2m.log](https://github.com/user-attachments/files/20526256/z2m.log)

tube0013, 2025-05-30:
if you go to the IP of the device in a browser what is the device name? It's possible I flashed the wrong firmware before shipping. If the web frontend doesn't say dual radio than that is the case. you can reflash the Olimex ESP32 using my web flasher here: https://tube0013.github.io/TubesZB-ESPHome-Builder/

(micro USB cable needed - don't have it plugged into PoE and USB at the same time).

phantomdez, 2025-05-30:
It does say Dual Radio:

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

phantomdez, 2025-06-01:
I did a few more troubleshooting steps.

- Reflashed Firmware.  I did this just incase there was something wrong.  Same result.
- UnInstalled Z2M cleared data and re-installed.  Same results
- I thought my old Conbee II was getting in the way and I removed it. Same result

Any further advice?  Anyway to enable more detailed logging to see what's going on?

Thanks for your help.

tube0013, 2025-06-01:
Confirming a few things.

Independently if run 1 at a time:

- z2m connects to port 6638 and runs
- zwavejs connects to port 6639 and runs

Have you had the web frontend open at all times when trying to have both connected at the same time? This should be an issue but not having it open will clear up resources on the esp32.

can you test using https://github.com/tube0013/tubeszb_addons/blob/main/tzb-zigpy-cli-tools/DOCS.md and attempting to run the info command on the zigbee module :6638 while zwavejs is running. if you are comfortable with pyhton you can run this from the command line too (https://github.com/zigpy/zigpy-cli) the command would be:

```zigpy radio ezsp socket://IP:6638 info```

You can also run an energy scan which will run until stopped for a continuous connection test if the info works.  also available in the addon or via command line:

```zigpy radio ezsp socket://IP:6638 energy-scan```

if these don't work can you describe how your HA is run and your home network is setup?

phantomdez, 2025-06-01:
Hi tube0013,
                    So first off to confirm yes if I run each add on independently they connect to the dual  radio.  In each test zwavejs will fail to connect if z2m is connected and z2m will fail to connect if zwavejs is connected.

So I did a few tests.  It seems that while I have the web frontend open to the device it only accepts 1 additional connection.  If I close the broweser to then I am able to connect to both zwavejs and z2m to the dual radio system.  I don't know if there is a traffic limitation to the hardware but if there is I think you may want to increase it past 2 connections.

Initially I couldn't get the zigpy-cli to work as it was even being refused connections until I shutdown both zwavejs and z2m.  I closed the web frontend and magic but now the web frontend will give me a site cannot be reached.

Here is output from zigpy-cli for your reference.  Let me know if I can provide additional information to help improve this:
Before  shutting down Web Frontend
`(.venv) root@zigpy:/zigpy# ./.venv/bin/zigpy radio ezsp socket://10.1.60.53:6638 info
Traceback (most recent call last):
  File "/zigpy/./.venv/bin/zigpy", line 8, in <module>
    sys.exit(cli())
             ^^^^^
  File "/zigpy/.venv/lib/python3.11/site-packages/click/core.py", line 1442, in __call__
    return self.main(*args, **kwargs)
           ^^^^^^^^^^^^^^^^^^^^^^^^^^
  File "/zigpy/.venv/lib/python3.11/site-packages/click/core.py", line 1363, in main
    rv = self.invoke(ctx)
         ^^^^^^^^^^^^^^^^
  File "/zigpy/.venv/lib/python3.11/site-packages/click/core.py", line 1830, in invoke
    return _process_result(sub_ctx.command.invoke(sub_ctx))
                           ^^^^^^^^^^^^^^^^^^^^^^^^^^^^^^^
  File "/zigpy/.venv/lib/python3.11/site-packages/click/core.py", line 1830, in invoke
    return _process_result(sub_ctx.command.invoke(sub_ctx))
                           ^^^^^^^^^^^^^^^^^^^^^^^^^^^^^^^
  File "/zigpy/.venv/lib/python3.11/site-packages/click/core.py", line 1226, in invoke
    return ctx.invoke(self.callback, **ctx.params)
           ^^^^^^^^^^^^^^^^^^^^^^^^^^^^^^^^^^^^^^^
  File "/zigpy/.venv/lib/python3.11/site-packages/click/core.py", line 794, in invoke
    return callback(*args, **kwargs)
           ^^^^^^^^^^^^^^^^^^^^^^^^^
  File "/zigpy/.venv/lib/python3.11/site-packages/click/decorators.py", line 46, in new_func
    return f(get_current_context().obj, *args, **kwargs)
           ^^^^^^^^^^^^^^^^^^^^^^^^^^^^^^^^^^^^^^^^^^^^^
  File "/zigpy/.venv/lib/python3.11/site-packages/zigpy_cli/cli.py", line 20, in inner
    return loop.run_until_complete(cmd(*args, **kwargs))
           ^^^^^^^^^^^^^^^^^^^^^^^^^^^^^^^^^^^^^^^^^^^^^
  File "/usr/lib/python3.11/asyncio/base_events.py", line 653, in run_until_complete
    return future.result()
           ^^^^^^^^^^^^^^^
  File "/zigpy/.venv/lib/python3.11/site-packages/zigpy_cli/radio.py", line 87, in info
    await app.connect()
  File "/zigpy/.venv/lib/python3.11/site-packages/bellows/zigbee/application.py", line 154, in connect
    await self._ezsp.connect(use_thread=self.config[CONF_USE_THREAD])
  File "/zigpy/.venv/lib/python3.11/site-packages/bellows/ezsp/__init__.py", line 138, in connect
    await self.startup_reset()
  File "/zigpy/.venv/lib/python3.11/site-packages/bellows/ezsp/__init__.py", line 119, in startup_reset
    await self._gw.wait_for_startup_reset()
  File "/zigpy/.venv/lib/python3.11/site-packages/bellows/uart.py", line 63, in wait_for_startup_reset
    await self._startup_reset_future
ConnectionResetError: Remote server closed connection`

After Shutting down Web Frontend:
`(.venv) root@zigpy:/zigpy# ./.venv/bin/zigpy radio ezsp socket://10.1.60.53:6638 info
PAN ID:                0x1A62
Extended PAN ID:       dd:dd:dd:dd:dd:dd:dd:dd
Channel:               11
Channel mask:          [11, 12, 13, 14, 15, 16, 17, 18, 19, 20, 21, 22, 23, 24, 25, 26]
NWK update ID:         0
Device IEEE:           70:54:64:ff:fe:58:13:5f
Device NWK:            0x0000
Network key:           01:03:05:07:09:0b:0d:0f:00:02:04:06:08:0a:0c:0d
Network key sequence:  0
Network key counter:   40961`

You can see when two connections to the device are made a "Remote server closed connection" is provided.

tube0013, 2025-07-19:
I'm actively troubleshooting this now. I have been able to reproduce, the best work around currently is to not connect to the web interface at all, if you have close the browser and power cycle the device. You can add the device to HA as an ESPHome device to monitor the serial connections if you enable the disabled entities you can have all the same controls as in the web front end.

baudneo, 2025-07-19:
Its kind of hit or miss for me now, sometimes it works sometimes it doesnt. I hadnt opened the web server at all yet, but after opening it and closing it, I have both radios working.

baudneo, 2025-07-20:
Awesome, thank you! Appreciate the work!

Closed 2025-07-20.

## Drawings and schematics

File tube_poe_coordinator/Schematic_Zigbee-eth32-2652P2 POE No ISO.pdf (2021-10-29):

## ESP32-POE

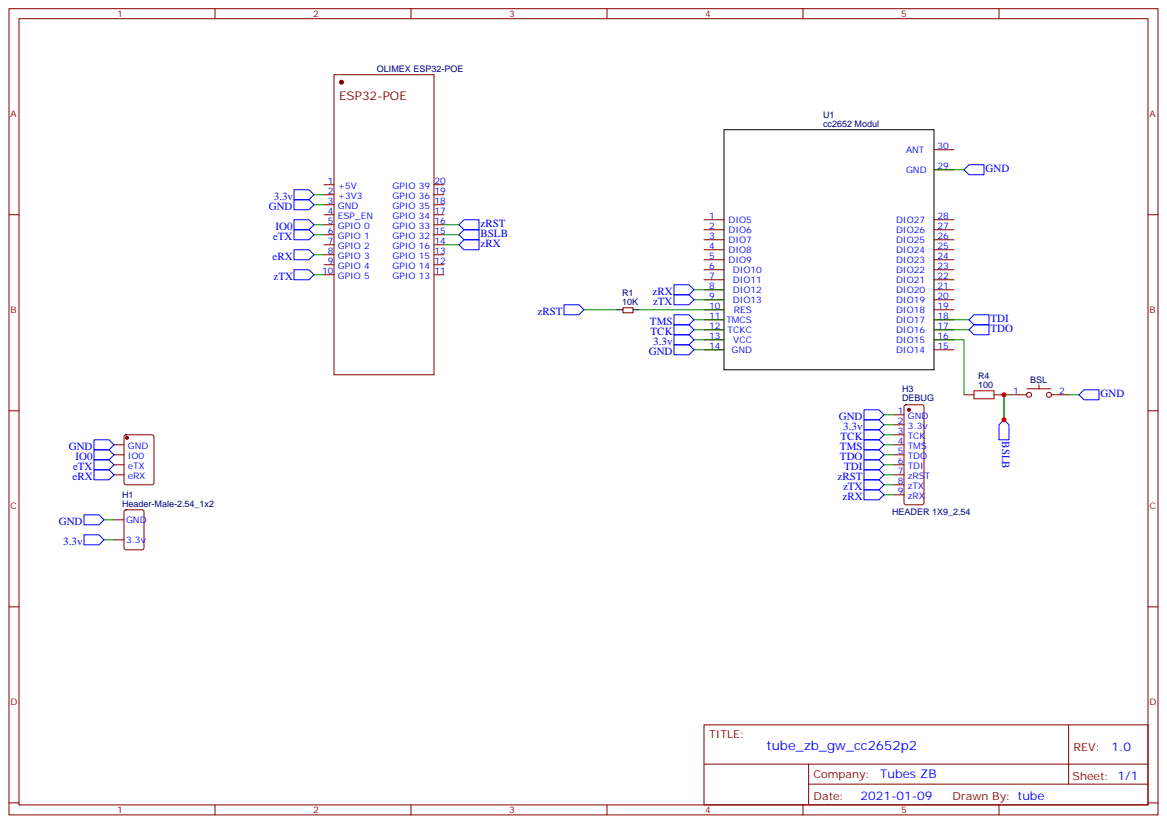
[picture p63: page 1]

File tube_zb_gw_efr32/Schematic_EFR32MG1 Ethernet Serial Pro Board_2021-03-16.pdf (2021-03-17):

## GPIO39 GPIO36

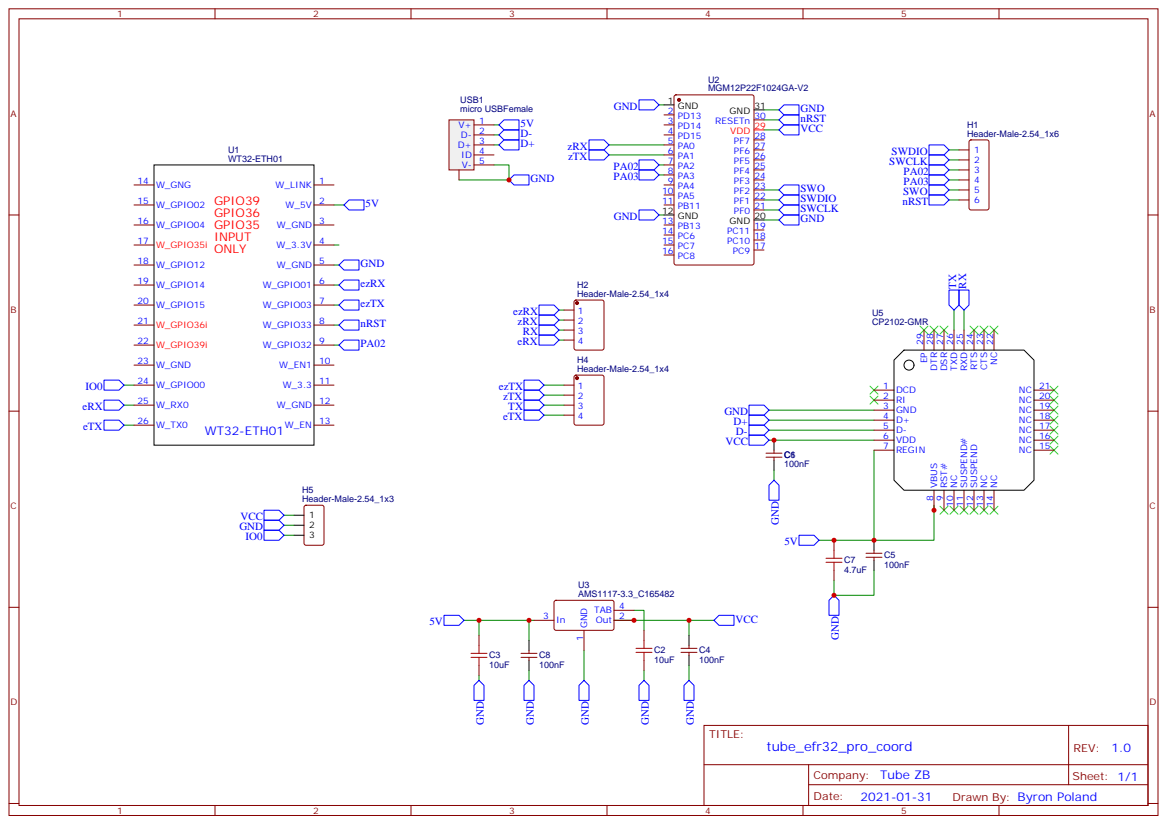
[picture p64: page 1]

NC 22 CTS 23 RTS 24 RXD 25 TXD 26 DSR 27 DTR 28 EP 29

Drawn By: Byron Poland

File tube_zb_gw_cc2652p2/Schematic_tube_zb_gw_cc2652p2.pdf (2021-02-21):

## GPIO39 GPIO36

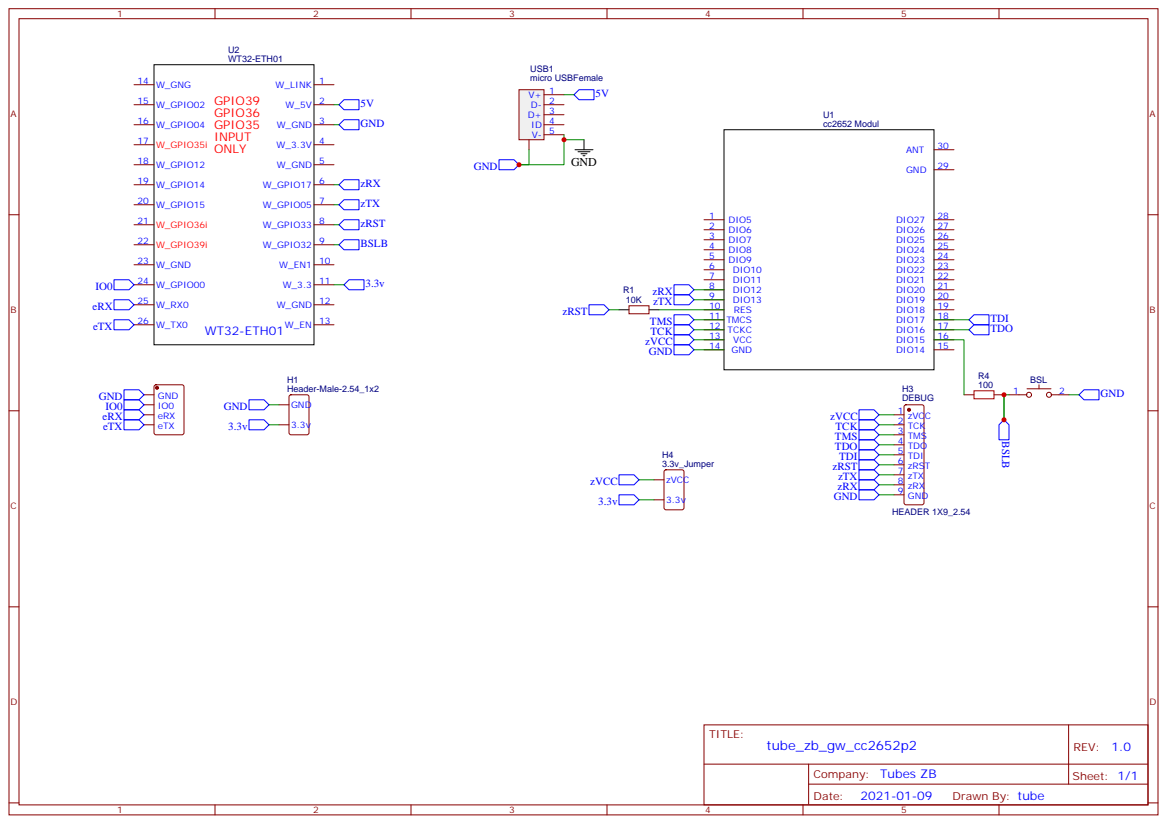
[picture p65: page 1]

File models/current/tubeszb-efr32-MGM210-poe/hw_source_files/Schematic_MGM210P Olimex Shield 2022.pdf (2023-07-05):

# MGM210P

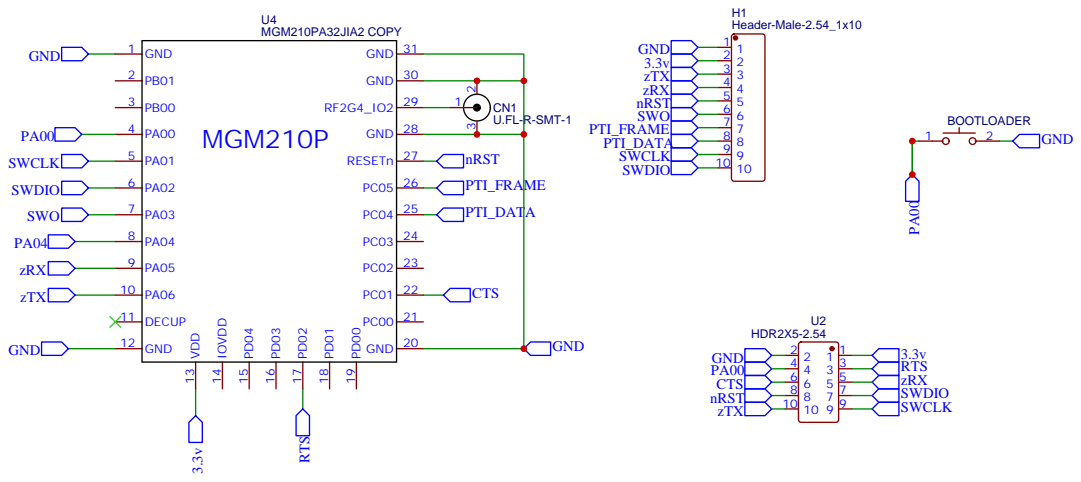
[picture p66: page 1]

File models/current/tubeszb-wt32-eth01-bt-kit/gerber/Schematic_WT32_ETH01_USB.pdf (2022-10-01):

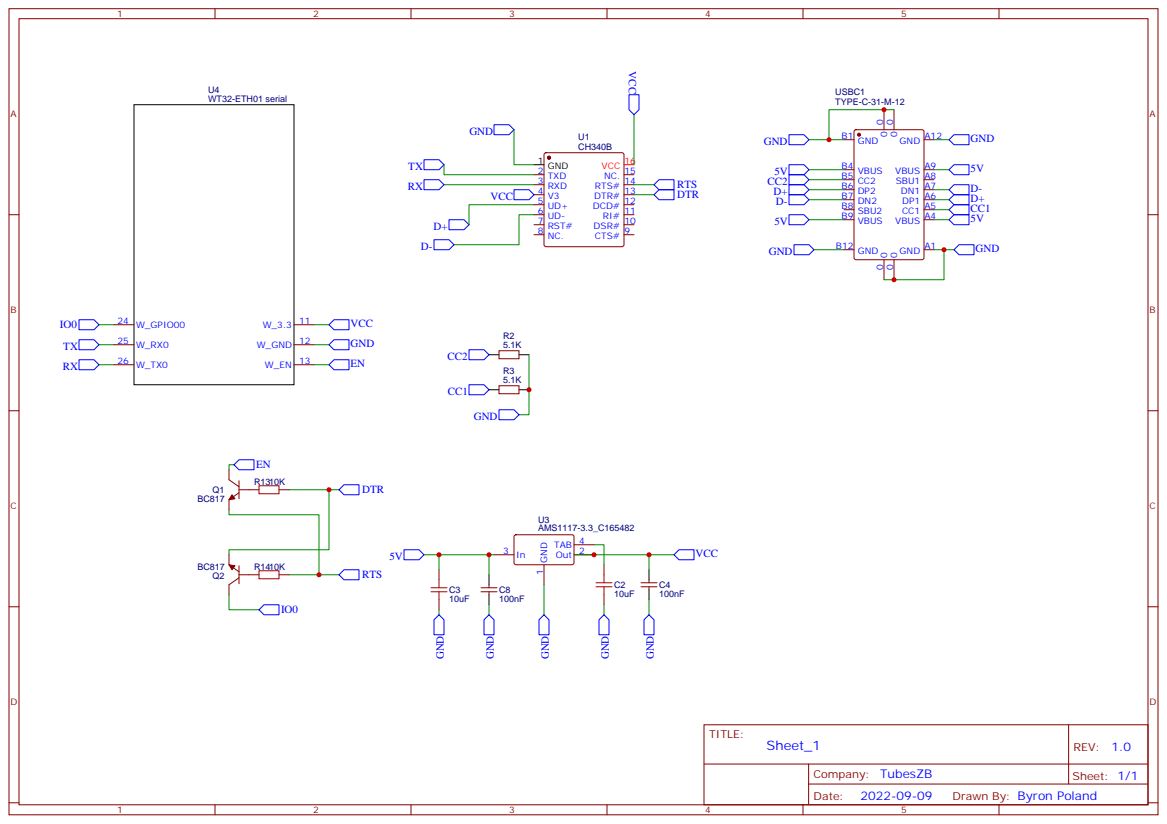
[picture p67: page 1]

DSR# 10 RI# 11 DCD# 12 DTR# 13 RTS# 14 NC. 15 VCC 16

Drawn By: Byron Poland

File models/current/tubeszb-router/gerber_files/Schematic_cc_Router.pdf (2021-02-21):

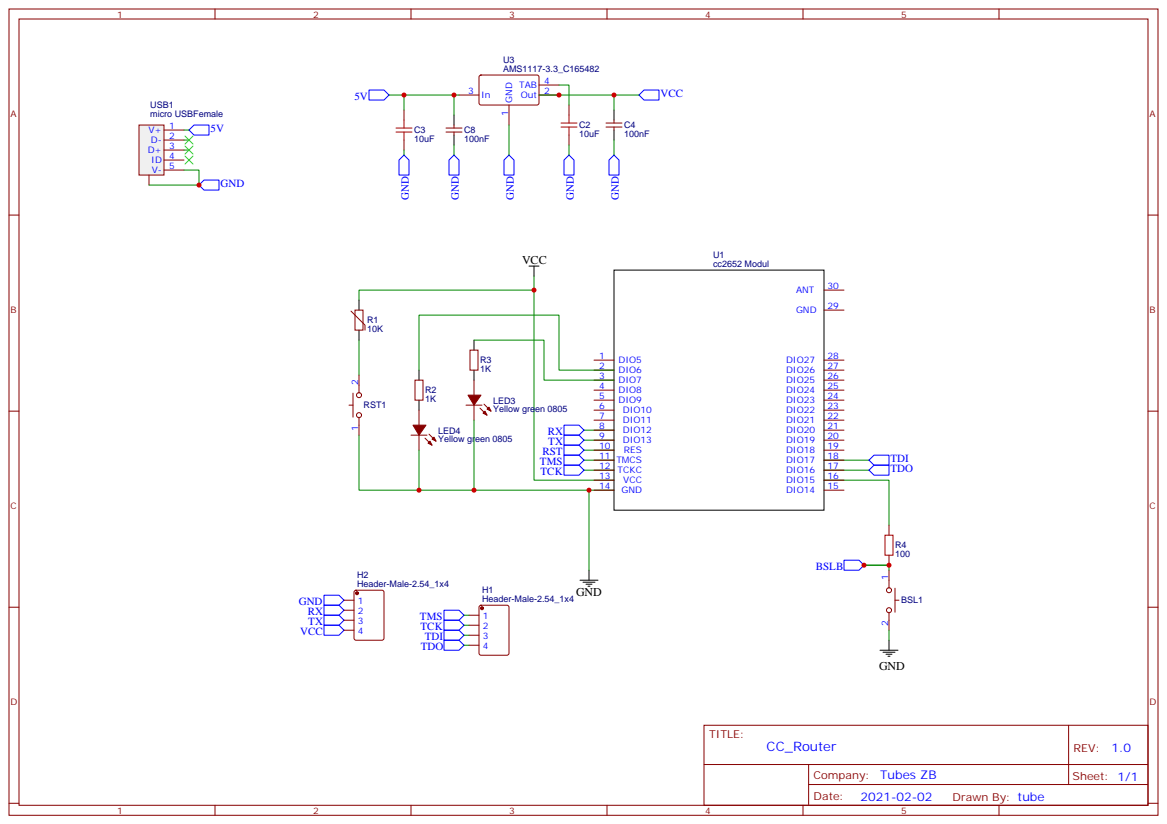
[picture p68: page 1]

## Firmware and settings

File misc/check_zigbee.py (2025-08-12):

import argparse
import asyncio
import sys
import logging
import os
import traceback

# Configure basic logging
logging.basicConfig(level=logging.INFO)
# Set library logging to WARNING to keep the output clean
logging.getLogger("bellows").setLevel(logging.WARNING)
logging.getLogger("zigpy_znp").setLevel(logging.WARNING)


# --- Check for and import required libraries ---
try:
    from bellows.zigbee.application import ControllerApplication as BellowsApp
    # We need the types for the getValue call
    import bellows.types
    BELLOWS_AVAILABLE = True
except ImportError:
    BELLOWS_AVAILABLE = False

try:
    from zigpy_znp.zigbee.application import ControllerApplication as ZNPApp
    ZNP_AVAILABLE = True
except ImportError:
    ZNP_AVAILABLE = False

# --- EZSP (Bellows) Checker ---
async def check_ezsp(device_path, baudrate):
    """Attempts to connect to a device as an EZSP coordinator."""
    if not BELLOWS_AVAILABLE:
        return False

    print("\n--- [1/2] PROBING FOR EZSP (Silicon Labs) ---")
    radio = None
    try:
        config = {
            'device': {'path': device_path, 'baudrate': baudrate},
            'database_path': None, # No database needed for this check
        }
        radio = BellowsApp(config=config)
        # Use .connect() for a low-level check without forming a network
        await radio.connect()
        
        # Fetch only the firmware version info
        version_info_list = await radio._ezsp.getValue(
            bellows.types.EzspValueId.VALUE_VERSION_INFO
        )
        
        # The value is the second element in the returned list
        version_info_bytes = version_info_list[1]
        
        # Parse the binary data into a readable version string
        if len(version_info_bytes) >= 6:
            major = version_info_bytes[2]
            minor = version_info_bytes[3]
            patch = version_info_bytes[4]
            build = version_info_bytes[5]
            firmware_version = f"{major}.{minor}.{patch}.{build}"
        else:
            firmware_version = version_info_bytes.hex(' ') # Fallback to hex
        
        print("\n✅ SUCCESS: Detected EZSP-based coordinator.")
        print("==============================================")
        print(f"  Firmware:       {firmware_version}")
        print("==============================================")
        return True
    
    except Exception:
        print(f"  INFO: Device is not responding as EZSP.")
        return False
    finally:
        if radio:
            # Gracefully handle disconnection errors
            try:
                await radio.disconnect()
            except Exception:
                pass

# --- ZNP (zigpy-znp) Checker ---
async def check_znp(device_path, baudrate):
    """Attempts to connect to a device as a ZNP coordinator."""
    if not ZNP_AVAILABLE:
        return False

    print("\n--- [2/2] PROBING FOR ZNP (Texas Instruments) ---")
    znp = None
    try:
        config = {'device': {'path': device_path, 'baudrate': baudrate}}
        znp = ZNPApp(config=config)
        # Use .connect() for a low-level check
        await znp.connect()
        
        # Fetch only the version information
        version_info = znp._znp.version
        
        print("\n✅ SUCCESS: Detected ZNP-based coordinator.")
        print("==============================================")
        print(f"  Protocol:     ZNP")
        print(f"  Z-Stack Ver:  {version_info}")
        print("==============================================")
        return True

    except Exception:
        print(f"  INFO: Device is not responding as ZNP.")
        return False
    finally:
        if znp:
            # Gracefully handle disconnection errors
            try:
                await znp.disconnect()
            except Exception:
                pass

async def main():
    """Main function to parse args and run checks."""
    if not BELLOWS_AVAILABLE or not ZNP_AVAILABLE:
        print("\n❌ FATAL: Required libraries 'bellows' or 'zigpy-znp' could not be imported.")
        print("Please ensure they are installed in the correct environment:")
        print("  pip install bellows zigpy-znp")
        sys.exit(1)

    parser = argparse.ArgumentParser(description="Universal Zigbee Coordinator Check")
    parser.add_argument("device", help="Serial port or socket URI (e.g., /dev/ttyACM0 or 'socket://host:port')")
    parser.add_argument("--baudrate", type=int, default=115200, help="Baud rate for the serial connection")
    args = parser.parse_args()

    print(f"\nStarting Zigbee radio check on {args.device} at {args.baudrate} baud...")

    if await check_ezsp(args.device, args.baudrate):
        sys.exit(0)

    if await check_znp(args.device, args.baudrate):
        sys.exit(0)

    print("\n❌ FAILED: Could not detect a known Zigbee radio (EZSP or ZNP).")
    print("Please check the following:")
    print("  1. The device path is correct.")
    print("  2. The device is properly plugged in and powered.")
    print("  3. The baud rate is correct (115200 is common, but some use 57600).")
    print("  4. The device is not in use by another program (e.g., Home Assistant, Zigbee2MQTT).")
    sys.exit(1)

if __name__ == "__main__":
    try:
        asyncio.run(main())
    except KeyboardInterrupt:
        print("\nExiting.")

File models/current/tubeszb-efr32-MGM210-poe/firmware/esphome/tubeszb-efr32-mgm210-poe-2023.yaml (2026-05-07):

esphome:
  name: tubeszb-efr32-mgm210-poe-2023
  project:
    name: tubeszb.efr32_mgm210_poe_2023
    version: "3.0"

esp32:
  board: esp-wrover-kit
  framework:
    type: arduino

external_components:
  - source: github://oxan/esphome-stream-server

dashboard_import:
  package_import_url: github://tube0013/tube_gateways/models/current/tubeszb-efr32-MGM210-poe/firmware/esphome/tubeszb-efr32-mgm210-poe-2023.yaml

#Olimex ESP32-PoE Ethernet
ethernet:
  type: LAN8720
  mdc_pin: GPIO23
  mdio_pin: GPIO18
  clk_mode: GPIO17_OUT
  phy_addr: 0
  power_pin: GPIO12

#WT32_ETH01 Ethernet
#ethernet:
#  type: LAN8720
#  mdc_pin: GPIO23
#  mdio_pin: GPIO18
#  clk_mode: GPIO0_IN
#  phy_addr: 1
#  power_pin: GPIO16
  
    # Optional manual IP
  #manual_ip:
    #static_ip: 
    #gateway: 
    #subnet: 255.255.255.0  

# Enable logging
logger:
  level: DEBUG
  
# Enable Home Assistant API
api:
  reboot_timeout: 0s

ota:
  platform: esphome

web_server:
  port: 80
  local: true
    
switch:
  - platform: gpio
    pin: 5
    id: zRST_gpio
    inverted: yes
    restore_mode: ALWAYS_OFF
        
  - platform: gpio
    pin: 16
    name: "Pull Bootloader pin (PA0) to Low"
    id: zBSL
    inverted: yes
    restore_mode: ALWAYS_OFF
    disabled_by_default: true  
    
button:    
  - platform: restart
    name: "Restart the Gateway"
    disabled_by_default: true

  - platform: template
    name: "EFR32 Reset"
    id: zRST
    disabled_by_default: true  
    on_press:
      - switch.turn_on: zRST_gpio
      - delay: 15ms
      - switch.turn_off: zRST_gpio

uart:
  id: uart_bus
  rx_pin: GPIO36 #2022 5 # 2023 36
  tx_pin: GPIO4 #2022 16 # 2023 4
  baud_rate: 115200


stream_server:
  uart_id: uart_bus
  port: 6638 # optional, default is 6638
#  buffer_size: 512

binary_sensor:
  - platform: stream_server
    connected:
      name: "TubesZB Serial Connected"

mdns:
  services:
    - service: "_tubeszb"
      protocol: "_tcp"
      port: 6638
      txt:
        version: 1.0
        name: TubesZB
        radio_type: ezsp
        baud_rate: 115200
        data_flow_control: software

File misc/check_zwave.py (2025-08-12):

import serial
import time
import argparse
import sys

# Z-Wave Serial API constants
SOF = 0x01  # Start Of Frame
ACK = 0x06  # Acknowledge
NAK = 0x15  # Not Acknowledged

# Frame types
REQUEST = 0x00
RESPONSE = 0x01

# Z-Wave Commands
FUNC_ID_GET_VERSION = 0x15

def calculate_checksum(frame_data):
    """Calculates the Z-Wave checksum (XOR of all bytes)."""
    checksum = 0xFF
    for byte in frame_data:
        checksum ^= byte
    return checksum

def main():
    parser = argparse.ArgumentParser(description="Z-Wave Radio Basic Functionality Check")
    parser.add_argument("port", help="Serial port or socket URI (e.g., COM3, /dev/ttyACM0, or 'socket://host:port')")
    parser.add_argument("--timeout", type=float, default=2.0, help="Serial port read timeout in seconds")
    args = parser.parse_args()

    print(f"Attempting to connect to Z-Wave radio on {args.port}...")

    try:
        # Baudrate is ignored for sockets but is needed for real serial ports.
        ser = serial.serial_for_url(args.port, timeout=args.timeout)
        
    except serial.SerialException as e:
        print(f"Error: Could not open port {args.port}. {e}")
        sys.exit(1)

    with ser:
        print(f"Successfully opened port: {ser.name}")
        
        # Construct the GET_VERSION command frame
        frame_core = bytes([
            0x03, # Length of frame (this field + type + cmd)
            REQUEST, # Type: Request
            FUNC_ID_GET_VERSION # Command
        ])
        checksum = calculate_checksum(frame_core)
        command = bytes([SOF]) + frame_core + bytes([checksum])
        
        print(f"-> Sending GET_VERSION command: {command.hex(' ')}")
        ser.write(command)

        # Wait for ACK
        ack = ser.read(1)
        if not ack:
            print("Error: Timed out waiting for ACK from the controller.")
            sys.exit(1)
        if ack != bytes([ACK]):
            print(f"Error: Expected ACK (0x06) but received {ack.hex()}.")
            sys.exit(1)

        print("<- Received ACK (0x06). Controller is listening.")

        # Wait for the full response frame
        response = ser.read(1) # Read SOF
        if response != bytes([SOF]):
            print(f"Error: Expected SOF (0x01) for response frame but got {response.hex()}.")
            sys.exit(1)
        
        response_data = ser.read(128)
        if len(response_data) < 4:
            print("Error: Incomplete response frame received.")
            sys.exit(1)
            
        print(f"<- Received Response Frame: {response.hex(' ')} {response_data.hex(' ')}")

        # Decode and print the result
        version_string = response_data[3:3+12].decode('ascii', errors='ignore').strip('\x00')
        library_type = response_data[15]

        library_map = {
            0x01: "Static Controller", 0x02: "Controller", 0x03: "Enhanced Slave",
            0x04: "Slave", 0x05: "Installer", 0x06: "Routing Slave",
            0x07: "Bridge Controller", 0x08: "Device Under Test",
        }

        print("\n🎉 Success! Z-Wave Radio is alive and responding.")
        print("==============================================")
        print(f"  Z-Wave Library Version: {version_string}")
        print(f"  Library Type:           0x{library_type:02x} ({library_map.get(library_type, 'Unknown')})")
        print("==============================================")

if __name__ == "__main__":
    main()

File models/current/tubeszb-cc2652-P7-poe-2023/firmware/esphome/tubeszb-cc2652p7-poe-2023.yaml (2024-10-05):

esphome:
  name: tubeszb-cc2652p7-poe-2023
  project: 
    name: tubezb.cc2652p7-poe-2023
    version: "3.0"
  on_boot:
    priority: 600
    then:
      - switch.turn_on: zRST_gpio
      - delay: 15ms
      - switch.turn_off: zRST_gpio

esp32:
  board: esp32-poe
  framework:
    type: esp-idf

external_components:
  - source: github://oxan/esphome-stream-server


dashboard_import:
  package_import_url: github://tube0013/tube_gateways/models/current/tubeszb-cc2652-P7-poe-2023/firmware/esphome/tubeszb-cc2652p7-poe-2023.yaml

#Olimex ESP32-PoE Ethernet
ethernet:
  type: LAN8720
  mdc_pin: GPIO23
  mdio_pin: GPIO18
  clk_mode: GPIO17_OUT
  phy_addr: 0
  power_pin: GPIO12
  
    # Optional manual IP
  #manual_ip:
    #static_ip: 
    #gateway: 
    #subnet: 255.255.255.0  

# Enable logging
logger:
  level: DEBUG
  
# Enable Home Assistant API
api:
  reboot_timeout: 0s

ota:
  platform: esphome

web_server:
  port: 80


script:
  - id: fw_update_mode
    then:
      - switch.turn_on: zBSL
      - delay: 1s
      - switch.turn_on: zRST_gpio
      - delay: 1s
      - switch.turn_off: zRST_gpio
      - logger.log: "Delaying ~10 seconds for cc2652p2 to settle"
      - delay: 11s
      - switch.turn_off: zBSL
      - logger.log: "Please try update with cc2538-bsl tool now"
      - logger.log: "cc-bsl usage: cc2538-bsl.py -p socket://ip-of-gw:6638 -evw firmware.hex"
      
switch:
  - platform: gpio
    pin: 5
    id: zRST_gpio
    inverted: yes
    restore_mode: ALWAYS_OFF
      
  - platform: gpio
    pin: 16
    name: "Zigbee Module Bootloader Pin"
    id: zBSL
    inverted: yes
    restore_mode: ALWAYS_OFF
    disabled_by_default: true

button:
  - platform: restart
    name: "Restart the Device"

  - platform: template
    name: "Zigbee Module Reset"
    disabled_by_default: true
    id: zRST
    on_press:
      - switch.turn_on: zRST_gpio
      - delay: 15ms
      - switch.turn_off: zRST_gpio

  - platform: template
    name: "Trigger Zigbee Module Bootloader"
    disabled_by_default: true
    on_press:
      - script.execute: fw_update_mode

uart:
  id: uart_bus
  rx_pin: GPIO36
  tx_pin: GPIO4
  baud_rate: 115200

stream_server:
#  buffer_size: 2048
  uart_id: uart_bus
  port: 6638 # optional, default is 6638


binary_sensor:
  - platform: stream_server
    connected:
      name: "TubesZB Serial Connected"

mdns:
  services:
    - service: "_tubeszb"
      protocol: "_tcp"
      port: 6638
      txt:
        version: 1.0
        name: TubesZB
        radio_type: znp
        baud_rate: 115200
        data_flow_control: software

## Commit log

2021-02-21 upload Gerbers/STL
    upload Gerbers/STL
    [Gerber_BoardOutline.GKO, Gerber_BottomLayer.GBL, Gerber_BottomSolderMaskLayer.GBS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]
2021-03-02 updates
    small reorg and start on efr32 pro gw docs
    [bottom_v6.2.stl, top_v6.1.stl, top_v6.2.stl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]
2021-03-02 FW upload
    [MGM12P32GE_ncp-uart-sw_6.7.8.gbl, MGM12P32GE_ncp-uart-sw_6.9.1_02262021_2.gbl]
2021-03-17 Update EFR32 GW Docs
    [MGM12P32GE_ncp-uart-sw_6.7.8.gbl, MGM12P32GE_ncp-uart-sw_6.9.1_02262021_2.gbl, MGM210PA32JIA_ncp-uart-sw_6.9.1_2.gbl]
2021-03-17 Update case
    Replace zigbee logo as to not get in trouble.
    [GW_bottom_v6.2.stl, GW_top_v7.stl, top_v6.2.stl]
2021-03-17 Update Router Cases
    change logo to not get in trouble with ZA.
    [cc-router_top_v10.1.stl, cc_router_bot_v10.stl, cc_router_bot_v11.stl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]
2021-03-17 More uploads/updates
    [BOM_EFR32MG1 Ethernet Serial Pro Board_2021-03-16.csv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]
2021-03-17 Update BOM_EFR32MG1 Ethernet Serial Pro Board_2021-03-16.csv
    [BOM_EFR32MG1 Ethernet Serial Pro Board_2021-03-16.csv]
2021-04-28 Add Reboot Switch to ESPhome
    Addresses #4
    [tube_zb_gw_efr32_Pro.yaml]
2021-04-29 Add 6.7.9 FW Builds for Series2 EFR32
    [MGM210PA32JIA_ncp-uart-sw_6.7.9.gbl]
2021-05-03 Add USB Coord STLs
    [cc_usb_cord_Bottom_v0.5b.stl, cc_usb_cord_top_v0.5.stl]
2021-05-18 Add 6.9.2 FW for Pro Series 1
    [MGM12P32GE_ncp-uart-sw_6.9.2.gbl]
2021-07-28 Update Gerbers
    [Gerber_BoardOutline.GKO, Gerber_BottomLayer.GBL, Gerber_BottomSolderMaskLayer.GBS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]
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2021-09-24 V2 Start
    Start of Docs for V2
    [Eth_Insert.stl, V2_TubesZB_Eth_Cord_v1_bottom.stl, V2_TubesZB_Eth_Cord_v1_top.stl]
2021-09-27 Add 6.9.2
    [Eth_Insert.stl, V2_TubesZB_Eth_Cord_v1_bottom.stl, V2_TubesZB_Eth_Cord_v1_top.stl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]
2021-10-29 add poe gerbers
    [Gerber_BoardOutline.GKO, Gerber_BottomLayer.GBL, Gerber_BottomSilkLayer.GBO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]
2021-11-13 Fix Folder Name Typo
    [Eth_Insert.stl, V2_TubesZB_Eth_Cord_v1_bottom.stl, V2_TubesZB_Eth_Cord_v1_top.stl]
2021-11-13 Add case with breakaway tab
    [Eth_Insert.stl, V2_TubesZB_Eth_Cord_v1_bottom_with_Tab.stl]
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2022-01-27 Updates for 2022_EFR32 MGM112
    [Eth_Insert.stl, V2_TubesZB_Eth_Cord_v1_bottom.stl, V2_TubesZB_Eth_Cord_v1_top.stl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]
2022-04-25 Add Gerbers
    [BOM_V2_tube_zb_gw_cc2652p2.csv]
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2022-06-28 Add 2022 PoE Cases
    Finally
    [TubesZB_2022_PoE_Coordinator_Case.f3d, TubesZB_2022_PoE_Coordinator_Case.step, TubesZB_2022_PoE_Coordinator_Case_Bottom.stl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]
2022-07-27 organize files
    [BOM_V2_tube_zb_gw_cc2652p2.csv, tubeszb-cc2652-eth_usb_bottom.stl, tubeszb-cc2652-eth_usb_top.stl]
2022-07-27 poe docs reorg
    [TubesZB_2022_PoE_Coordinator_Case.f3d, TubesZB_2022_PoE_Coordinator_Case.step, tubeszb-cc2652-poe-2022_Bot.stl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]
2022-08-02 re-org router stuff
    [BOM_cc_router.csv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]
2022-08-02 more re-org
    [BOM_EFR32MG1 Ethernet Serial Pro Board_2021-03-16.csv, BOM_cc_router.csv, BOM_tube_zb_gw_cc2652p2.csv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]
2022-08-02 more -reorg
    [BOM_V2_tube_zb_gw_cc2652p2.csv, TubesZB_2022_PoE_Coordinator_Case.f3d, TubesZB_2022_PoE_Coordinator_Case.step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]
2022-08-12 Add files via upload
    Top Cover holding Ailkin USB charger (Size: 1.49'' x 1.49'' x 1.77'')
    [cover over usb power.stl]
2022-08-12 creat usermod folder
    [cover over usb power.stl]
2022-10-01 add hw source
    [BOM_PCB_WT32_ETH01_USB.csv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]
2022-10-10 beta fw updates for new esphome serial server!
    [tubeszb-cc2652-eth_usb_bottom.stl, tubeszb-cc2652-eth_usb_top.stl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]
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2022-10-17 EFR32 FW for MGM210 PoE
    [MGM210PA32JIA_ncp-uart-sw_6.10.3_TubesZB_2022.gbl]
2022-11-09 Updated Case files for new Olimex Rev K
    Olimex has updated the ESP32-PoE to Rev K, which is 6mm longer than previous revisions 🤦‍♂️
    [TubesZB_2022_PoE_Coordinator_Case_Rev_K_Olimex.3mf, TubesZB_2022_PoE_Coordinator_Case_Rev_K_Olimex.f3d, TubesZB_2022_PoE_Coordinator_Case_Rev_K_Olimex.step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]
2022-11-25 Update README.md
    Fix a couple typo
2023-01-10 Fix Dashboard import path/ New bins
    Fix Dashboard import paths, update Binary builds for fix and esphome v2022.12.3
    [tubeszb-cc2652-poe-2022.yaml, tubeszb-cc2652-poe.yaml, tubeszb-efr32-mgm12-2022.yaml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]
2023-02-19 2021 Series 2 fw builds
    [MGM210PA32JIA_6.9.2_tube_1.gbl, MGM210PA32JIA_ncp-uart-sw_6.10.3_TubesZB_2021.gbl, MGM210PA32JIA_ncp-uart-sw_6.7.9.gbl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]
2023-02-20 silabs fw builds
    [20230219_MGM12ncp-uart-sw_7.2.1_2021.gbl, 20230219_MGM12ncp-uart-sw_7.2.1_2022.gbl, MGM12P32GE_ncp-uart-sw_6.7.8.gbl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]
2023-04-18 add mgm21 7.7.2 fw
    from 2023.04.16 Build Action
    [MGM210PA32JIA_ncp-uart-sw_7.2.2_TubesZB_2022.gbl]
2023-05-15 Update Repo for 2023 Rev of cc2652PoE
    Adds Leds (controled by z2m or zha/znp config) to module and adjusts UEXT pin out for upcoming carrier board.
    [TubesZB_PoE_Bottom_20230305.stl, TubesZB_PoE_Top_20230305.stl]
2023-06-05 update router cases.
    [cc_router_bot_v11.stl, cc_router_top_v11.stl, tubesZB_router_bottom_v12.stl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]
2023-10-06 Update tubeszb-cc2652-poe-2022.yaml
    fix path
    [tubeszb-cc2652-poe-2022.yaml]
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2024-04-11 Add Untested efr32 7.4.2 ncp builds
    [TubesZB-BM24-2023_7.4.2_ncp.gbl, TubesZB_MGM12ncp-uart-2021_7.4.2.gbl, TubesZB_MGM21_ncp-uart_2021-7.4.2.gbl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]
2024-04-16 add ZW case STLs
    [Z-Wave_PoE_AntHole_011224.stl, Z-Wave_PoE_No_AntHole_011224.stl, Z-Wave_PoE_Top_011224.stl]
2024-05-20 Add EFR32 FW builds for SDK Release 4.4.3 (ezsp 7.4.3)
    [tubesZB-EFR32-MGM24_NCP_7.4.3.gbl, tubeszb-BM24-2023-hwflow-high_7.4.3.gbl, tubeszb-MGMPB-hwflow-high_7.4.3.gbl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]
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2025-07-22 add Dual Radio Kit enclosure STLs
    [tubeszb_dual-radio_bottom_07012025.stl, tubeszb_dual-radio_top_2025.stl]
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2026-05-08 add firmware to docs for ghpages add missing mgm24 7.4.4 gbl
    [tubeszb-BM-MG24B2-7.4.4.gbl, tubeszb-mgm24-hw-max_ncp-uart-hw_7.4.4.0.gbl]
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2026-07-12 docs: add PoE/USB simultaneous-power warning to EFR32 coordinator page
    The micro-USB port is not isolated; powering from PoE and USB at the same
    time can damage the board and the connected computer. CC2652 and Z-Wave
    pages already carried this warning — the EFR32 page did not.
